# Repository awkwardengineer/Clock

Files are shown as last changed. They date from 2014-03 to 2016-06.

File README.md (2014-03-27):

Voltmeter Clock Image

# Intro
This is the repository for the AWK-105 Voltmeter clock. Here is where we'll be storing requirements documents, design history files, useful tidbits of information, and other material that otherwise wouldn't be release to manufacture or included in a Bill of Materials

##Consumer Facing Page
The repo may be cool, but it's not for everyone. The consumer facing product page has the bulk of the media material.

[Awkward Engineer Product Page](http://www.awkwardengineer.com/pages/voltmeter-clock)

##How This Repo Is Organized
In general, there are two categories of thing:  
+ Artifacts that will become part of the Bill Of Materials and will be released to a manufacturer. This includes CAD files, drawings, Gerbers, etc.  
+ Documentation and design files that record useful and important information, but that the manufacturer doesn't need to actually MAKE something.

The idea was to try to organize the documentation near the design file, kindof like things are arranged below.

Clock  
|  
|--Mechanical  
|&nbsp;&nbsp;&nbsp;|----CAD            <=== BOM artifacts, 3d part files, drawings  
|&nbsp;&nbsp;&nbsp;|----Design Docs    <=== Documentation specific to mechanical stuff
|&nbsp;&nbsp;&nbsp;|----Reference Mat. <=== Usually mostly .pdfs  
|  
|--Electrical  
|&nbsp;&nbsp;&nbsp;|----CAD            <=== Gerbers, net files, etc...  
|&nbsp;&nbsp;&nbsp;|----Design Docs    <=== Documentation specific to electrical stuff  
|  
|--Photos  
|  
|--etc...  

##Design Documents
Here are some quick links to some design stuff, right off the bat.

[Requirements](Electrical/Design Docs/requirements.md)  
[Microchip selection](Electrical/Design Docs/microcontroller selection.md)  
Sales strategy

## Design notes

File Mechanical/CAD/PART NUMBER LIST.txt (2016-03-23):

NUMBER	DESCRIPTION

AWK-105-0001-ARTWORK    ARTWORK FOR METERS
AWK-105-0001-H          VOLTMETER, HOURS
AWK-105-0001-M          VOLTMETER, MINUTES
AWK-105-0001-S          VOLTMETER, SCRAP
AWK-105-0002            BOX, FRONT FACE
AWK-105-0003            ASSEMBLY, VOLTMETER
AWK-105-0004            BOX, BACK FACE
AWK-105-0005            PCB
AWK-105-0006            **** obsolete BOX MODIFICATION NOTES
AWK-105-0007            PCB LAYOUT SKETCH
AWK-105-0008            QUADRATURE ENCODER, BOURNES PEC12R-2xxxF-Nxxxx
AWK-105-0009	        POTENTIOMETER              
AWK-105-0010            HOUSING DRAWINGS, VOLTMETER CLOCK
AWK-105-0011            PHILLIPS PAN HEAD SCREW, 4-40x.25, 18-8 SS
AWK-105-0012            NUT, METRIC M2, 18-8 SS
AWK-105-0013            PHILLIPS PAN HEAD SCREW, METRIC M2 x 4mm, 18-8 SS
AWK-105-0014            CONTROL KNOB
AWK-105-0015            ASSEMBLY DRAWINGS, VOLTMETER CLOCK
AWK-105-0016            SCREEN PRINT ARTWORK, FRONT FACE
AWK-105-0017            SCREEN PRINT ARTWORK, TOP FACE
AWK-105-0018            PHILLIPS PAN HEAD SCREW, METRIC M2.5 x 4mm, 18-8 SS
AWK-105-0019            CARDBOARD MAILER BOX
AWK-105-0020            STICKER, MAILER BOX
AWK-105-0021            ARTWORK, STICKER, MAILER BOX

AWK-105-0022            PROGRAMMED ATtiny CHIP
AWK-105-0023 Rev A      HEX FILE TO BURN INTO CHIP
AWK-105-0024 Rev A      FUSE SETTINGS TO BURN CHIP

AWK-105-0024            BATTERY CLIP

AWK-105-0025            VOLTMETER CLOCK ASSEMBLY PROCEDURE

AWK-105-0026            TOGGLE SWITCH
AWK-105-0027            TOGGLE SWITCH COVER
AWK-105-0028            LED

AWK-105-0029            WADDING (PACKAGING)

AWK-105-0030            SCREEN PRINT ARTWORK, TOP FACE, ALARM
AWK-105-0031            SCREEN PRINT ARTWORK, FRONT FACE, ALARM

AWK-105-0032            AA BATTERY
AWK-105-0033            INSTRUCTION SHEET
AWK-105-0034            METER TEST SPEC
AWK-105-0035            STICKER DOT
AWK-105-0036            M3 PEM NUT
AWK-105-0037		CASE FRONT, UNPAINTED
AWK-105-0038		CASE BACK, UNPAINTED
AWK-105-0039		INK PAD
AWK-105-0040		EXTRA NARROW SOCKET DRIVER
AWK-105-0041		SQUEEZE DRIVER HAND TOOL
AWK-105-0042            MASTER CARTON
AWK-105-0043            MASTER CARTON LABEL
AWK-105-0044            MASTER CARTON ARTWORK
AWK-105-0045		GIFT CODE INSERT

TEST RIGS BLOCK O'NUMBERS:
===============================================
AWK-105-0100            METER TEST MASTER MODEL
AWK-105-0101		HOUSING, TEST RIG

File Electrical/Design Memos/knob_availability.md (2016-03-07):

Potentiometer, 50K from panasonic  
readily available with 10mm centerline height (same as existing) and a 25mm flatted shaft (5mm longer)  
EVU-E2AF25B54  
  
has a 3 pin configuration, whereas the Bourns PTV111 family I used had 4 pins

from Bourns, not as readily available 10K version in identical package

PTV09A-2025F-B103

PTV-09A-2020F is slightly shorter, but available in more resistances, although not as many

TT Electronics has an encoder, but footprint doesn't work EN11-HSM

CUI makes an ACZ11 family that is pin compatable with the PEC12 encoder, but isn't super available

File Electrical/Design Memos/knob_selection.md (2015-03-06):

>**Executive Summary:** An archived memo details the experience of browsing Digikey and eventually settling on some encoders and potentiometers from a manufacturing company called Bourns. The right angle components were slightly more expensive, but they more than make up for the cost in terms of reduced assembly steps. This memo recaps the selection of specific part numbers.

##Encoder
PEC12R-<config><detents><shaft length>F-<switch><resolution>

PEC12R-2120F-N0012

PEC12R-

2  - <config: horizontal>
1  - <detents: 12>
20 - <shaft length: 20mm shaft>
F  - flatted shaft
N  - <switch: no switch>
0012 - <resolution: 12 pulses>

##Potentiometer

PTV111-2420A-B104

PTV111-

2 - <config: no bushing, pins horizontal>
4 - <center detent?: none>
20 - <shaft length: 25mm>
A - Flat type shaft
B - <taper: most linearly tapered curve available>
104 - <resistance: 100K>

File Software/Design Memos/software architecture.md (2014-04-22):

>**Executive Summary:** Offload as much work to the TIMERs as possible and shutting down the CPU to save power.

##Software/Power Strategy
To truly take advantage of what the ATtiny84 microcontroller can do, we're going to be getting into some of the features of the chip that the Arduino environment normally hides. More specifically, we'll be taking advantage of some of the power saving modes.

As it turns out, the ATtiny84 has two timers that can be run completely independently of the actual CPU (plus a watchdog, which we won't use). The general idea, therefore, is to keep the CPU off as much as possible, saving power, and only doing work during periodic interrupt service routines when TIMER1 maxes out.

The first timer, TIMER0, will be used to control the PWM outputs that control the hands on the voltmeter. When initialized with the right settings, the timer will chug along, independently of the CPU and the Output Compare Registers A & B will automatically compare their settings to the timer count, setting the duty cycle of the PWM outputs.

The second timer, TIMER1, has a 16 bit register that triggers an interrupt when it overflows, waking up the CPU. The microcontroller then polls the input to see if the "Mode select" knob has changed, adjusts the hands as appropriate, then goes back to sleep.

We started making some notes

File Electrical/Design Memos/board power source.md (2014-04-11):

#Selecting a Power Source

We've gotten some feedback to ditch the wall-wart power supply and move the clock over to battery power. That certainly has some appeal (Ditches a pricey component, eliminates the assembly operation to feed the cable through the wall, eliminates a grommet at the wall, etc...), so we decided to look into it.

#Is battery power reasonable?

Wikipedia gives the capacity of an [AA battery](http://en.wikipedia.org/wiki/AA_battery) as 1800-2600mAHr. The ATtiny84 draws 300uA and the two ammeters draw an average total of 50uA. With some assumptions about an AA battery and some simple math:

2200mAHr / 350uA = 6286 Hrs = 261 days = about 8 months.

8 months is pretty good! And that's without taking advantage of the microcontroller sleep modes. I'd feel pretty good about performance if I could stretch it to a full year. I think adding a battery in parallel would provide good margin to do that.

#Implications of Switching to Battery Power
Other than the need to conserve power, the next challenge is that the battery voltage will droop as it discharges. The ATtiny84 has some brown out detection stuff I don't know much about, but more importantly, drooping voltage can't effect the position of the time keeping analog needles.

There are a few ways I'm considering to deal with this problem:

|Method | Pros | Cons |
|---|---|---|
| Linear regulator on battery | simple | less efficient |
| Buck (and/or) Boost converter on battery | more expensive | more efficient |
| Leave the battery unregulated, but use a voltage reference to make a constant current source to drive the meters. | unsure of cost or efficiency | unsure of cost or efficiency |

The ATtiny84 can run on anything from 1.8V to 5V, so it means 2 or 3 AA batteries in series off the bat. According to [this source](http://www.powerstream.com/AA-tests.htm), an AA alkaline battery will slowly droop from 1.5V to 1V over the course of it's life before really crashing.

I started looking into various ways to power the clock, and figured I'd have to actually price it out to make a decision. Here are the various circuit diagrams I'll refer to:

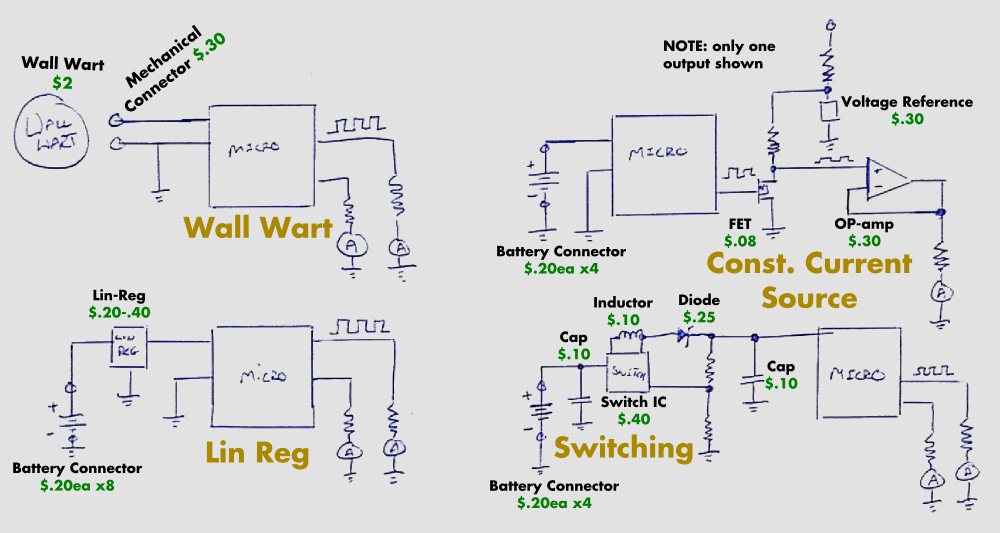
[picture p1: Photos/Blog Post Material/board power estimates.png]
circuit diagram


##Linear Regulator
Working again through the firehose that is Digikey, linear regulator chips like [this](http://www.ti.com/lit/ds/symlink/lp2951-33.pdf) are available for about $.20-.40 in the 100 piece volume range. This is pretty cheap, but the trade is that the two AA batteries will have an average voltage of about 2.5V over their lifespan and if I'm trying to output 2V or so to the micro, the .5V difference between input and output is like a 20% hit to power. Instead of the board pulling 350uA, it'd seem more like 420uA.

##Switching Regulator
Switching regulators can be more efficient than linear regulators and because they can boost voltage, it'd be possible to generate the needed 1.8V to run the micro, even from a 1.5V AA battery.

Again, Digikey can be overwhelming, as there are over 20,000 switching converter SKU's available. My approach was filter by current load first, which got it down to a more manageable 2000 pieces, then sorted by cost in volumes of 100. That lead me to [this chip](http://www.diodes.com/datasheets/AP3015_A.pdf), specifically meant for boosting from one or two battery cells.

It runs aroune $.40, plus it requires several additional components, and can introduce ripple to the voltage. (Although high frequency ripple at the switching speeds will be completely mechanically damped at the needles). The required extra components (caps, inductor, diode), might run $.05-.20 each, which I'll estimate rolled together at adding another $.40, make the boost cicuit cost about $.80.

##Unregulated Battery
The ATtiny84 chip will certainly run off battery power, but to get a consistant current to the meters, rather than rely on the voltage from the micro's digital output, I'd use that to control a constant current source. This could be built with a precision voltage reference, an op-amp, and some FETS. Of course, I'd need to double these up for both the "Hours" meter and the "Minutes" meter.

After browsing digikey for precision voltage references, filtering by current draw, then sorting on price, I found that precision voltage references that drew < .1mA current ran around $.30. Given the other components required, I don't it will be significantly cheaper than the regulated versions, and it is certainly more complicated.

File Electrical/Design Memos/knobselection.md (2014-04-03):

>**Executive Summary:** Browsing digikey found no appropriate SMT encoders or pots. Of the through-hole connectors, the "right angle" style are $.10-.20 more expensive, but I believe that is justified by the fact a single board can connect the knobs and dials, reducing assembly complexity, and eliminating the need for flying leads or jumpers to the dials. Quantities may necessitate a special order through a distributor. [Bourns](http://www.bourns.com/Products.aspx) was the company picked to select encoders and pots from. I picked the Bourns **PEC12R-2020F-N0024** encoder, and the Bourns **PTV11-2420A-A4503** potentiometer.

##Intro
The Clock has two control knobs, one to select the mode of operation, and one to make adjustments to time or calibration, depending on the mode. The mode select knob uses a pot to measure absolute position and the adjustment knob uses a quadrature encoder to allow the knob to rotate 360 degrees and to measure relative motion.

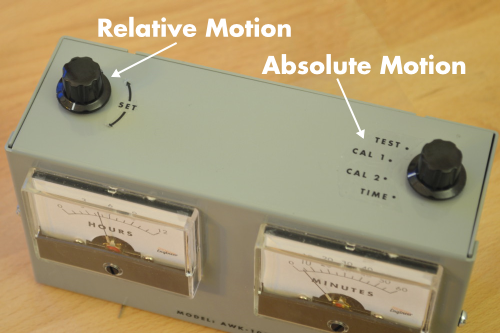
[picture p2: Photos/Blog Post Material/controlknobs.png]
knobs


##The Prototype, aka The Rat's Nest
The prototype has a lot of hand soldered flying leads, cobbled together from knob components that I found, the Digispark microcontroller, and the voltmeters.

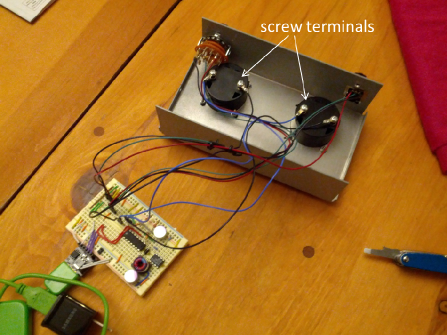
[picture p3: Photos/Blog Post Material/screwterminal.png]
rat nest


##Designing for Assembly
The electronics assembly absolutely needs to be cleaned up so that assembly process can be quick and reliable. I've worked in the past with a mechanical assembly house that provide employment for the mentally disabled and I try to keep them in mind when designing. The assembly house is also near my e-commerce warehouse, so I have to have a really good reason to not use them. Poor design can't be one of those reasons.

I had two ideas:

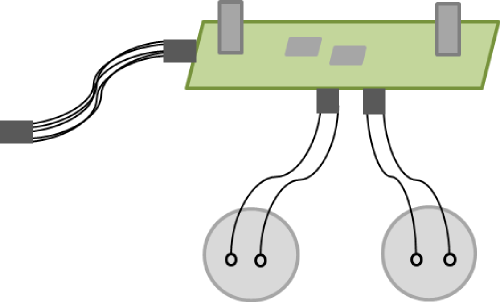
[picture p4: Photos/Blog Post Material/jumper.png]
jumper
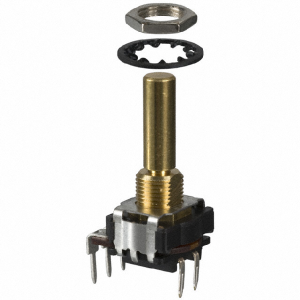
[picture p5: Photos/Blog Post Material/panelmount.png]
panel mount
1. Use panel mount switches to hold the PCBA underneath the clock. The flying leads running to the dials would be replaced with a jumper kit, with a plug on one end of the harness running to the board and ring terminal crimps on the other that would screw onto the dial leads. I figured the overall board size would be smaller (and therefore cheaper), and the cable, if I could source it, would be easy for an unskilled laborer to install. The nuts on "panel mount" style knobs would secure the PCBA and eliminate the need for standoffs in the housing.<br>
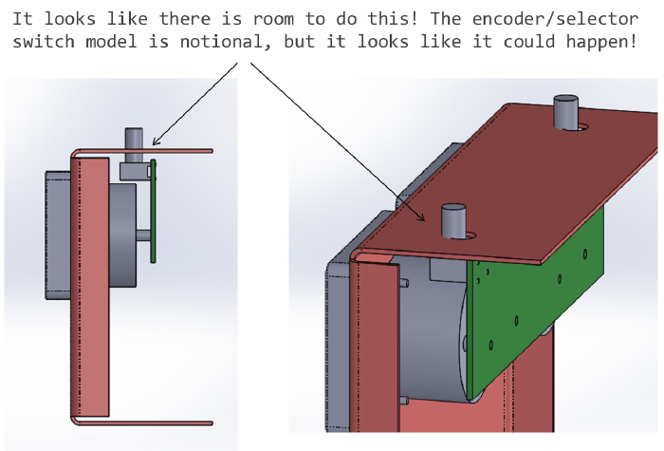
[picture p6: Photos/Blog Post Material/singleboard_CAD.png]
single
2. I had a second idea to use the board itself to run traces to a through hole. The area around the hole would be plated so that screwing the board to the dial leads would make electrical contact and mechanically mount the board. This would require a "right angle" style encoder and pot. <br>

##Searching Digikey
Much like microcontroller selection, browsing the zillions of components on Digikey can be overwhelming. Here's what drove selection:

- sorting by price, I found 6mm shafts were typically cheapest. (closest metric size to 1/4in and a common knob size. I learned this from work on the Awkard Engineer [Panic Button Light Switch Kit](http://www.awkwardengineer.com/collections/stuff/products/panic-button-limited-edition))
- SMTs were out pretty quickly, they're just not available in the right sizes or form factors.
- next I learned that right angle style components were running around $.10-.20 more expensive than straight on style devices, but given that it saves sourcing a jumper cable and two nut turning operations on the panel mount style switch, I think it's worth it.
- finally, try to select by size / price.

Of the Digkey components I found, [Bourns](http://www.bourns.com/Products.aspx) was a name that popped up for in stock products in the sub $1 range for components.

##A comment on sourcing before final selection
I know I'm too small a player to deal with a manufacturer directly and my volumes may necessitate a special order, given what I saw on Digikey. Rather than designing based on what's in-stock with Digikey right *now*, my approach will be to take the manufacturer I identified, select an encoder and pot with identical packaging (will make mechanical assembly easier) and pick what I really want.

An EE friend suggested that when you cross over from the on-demand, prototype quantities available through Digi-key, there's another market for chips out there with a mix of distributors and "gray market" sources. Manufacturers take multi thousand piece orders (think whole reels, trays, or cases... in retail we'd call this the Minimum Order Quantity, or MOQ)from middlemen, then little guys like me buy from the middleman.

For example, a distributor may place the MOQ sized order and hold the balance in stock while selling the smaller quanitity to me, or a board house who had to place a MOQ sized order to populate a PCBA might try to sell the balance of their stock on the gray market.

The EE friend refered me specifically to [findchips.com](http://www.findchips.com/) as a "meta" search engine, that will search all the distributors for a paricular part and return the amount in stock. If the components aren't available there, then I'd place an order through a distributor and the lead time might be about 8-12 weeks.

##Selecting components
Finally, after picking Bourns's catalog, I used the parts I found using the "sort by price" option on Digikey to direct me to a specific "series" of part.

Within each series, you can pick from a range of options like mounting style, shaft length, encoder counts per revolution, press on / press off switch, and so on.  I picked

encoder: PEC12R-2020F-N0024
potentiometer: PTV11-2420A-A4503

When it comes time to go to fab, I may work with the board house to come up with a list of alternate components that would be acceptable. (For example, a 20K pot would be just as good as a 50K pot for my purposes).

##Physical Check
I modeled the components in CAD to physically check them. It looks like the single board idea will work, but I'll either need to stand it off from the screw terminals, or move the control knobs forward. (I know which way is cheaper, but also which way affects the look of the finished part)

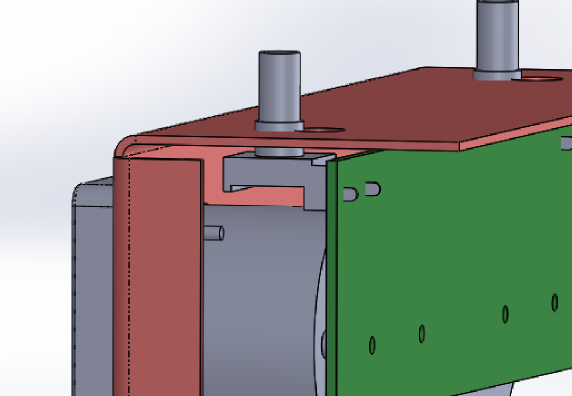
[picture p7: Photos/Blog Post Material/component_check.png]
CAD Check


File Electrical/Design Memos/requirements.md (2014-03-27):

#Short background of the requirements:

The microchip is meant to run a "voltmeter clock." It's responsible for time keeping, sending PWM signals to the meters, reading inputs from the control knobs, and so on. The prototype was controlled with a Digispark hobby board and I'm trying to develop a short run production version. (probably more than 100 units and less than 1000)  

Prototype program code was around 5kB on a Digispark board (atTiny85) using the Arduino environment plus whatever bootloader was already burned on the chip

##System Diagram
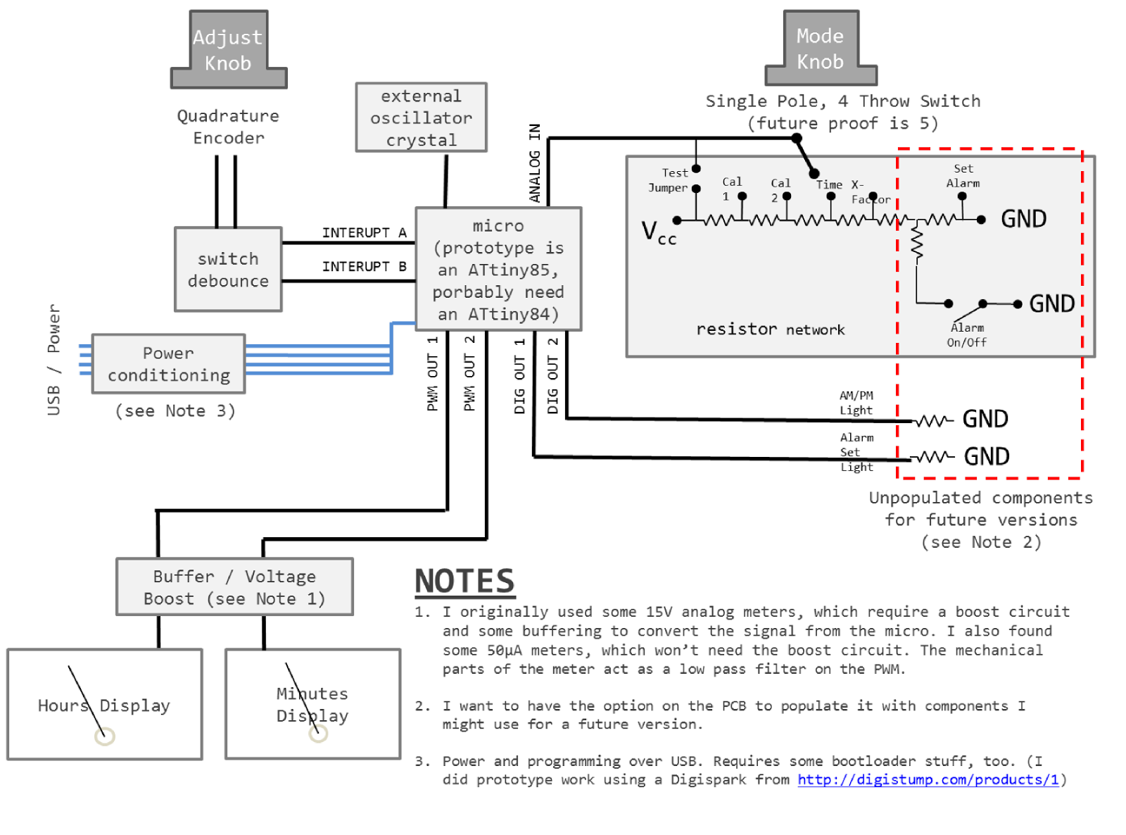
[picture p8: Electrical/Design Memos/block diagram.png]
system diagram


##Pin requirements
(beyond what's on the Digispark) would be as follows:

1 analog in to read selector switch / voltage divider  
2 interrupts to read quadrature encoder  
2 PWM outputs  
3 digital outputs for am/pm light, alarm set, and buzzer  
2 pins for external oscillator crystal

ISP connection

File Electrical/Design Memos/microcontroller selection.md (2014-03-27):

#Microcontroller Selection and Justification by Someone Who's Only Selected One or Two Before

>**Executive Summary:** An ATtiny84 microchip was selected based on requirements developed after prototyping a Voltmeter clock with a Digispark Board/ATtiny85. Specifically, the ATtiny84 can handle the 10 I/O plus ISP lines and a 5Kb+ program size.

##Intro
The purpose of this document is to justify the selection of a microcontroller for the Voltmeter Clock. Although a prototype was built using a Digispark Board/ATtiny85, the ATtiny85 didn't have enough I/O to implement all the desired features.

##Requirements review:
The following quotes from the [requirements doc](requirements.md).  
>**Pin summary**  
>1 analog in to read selector switch / voltage divider  
>2 interrupts to read quadrature encoder  
>2 PWM outputs  
>3 digital outputs for am/pm light, alarm set, and buzzer  
>2 pins for external oscillator crystal  

All together, this works out to 8 I/O pins, the 2 clock pins, and whatever is needed for In System Programming (ISP) pins, which can serve double duty.

##Design Descision \#1: Stay in the Atmel family
This decision is made more on qualitative measures rather than rigorous analysis. I'm familiar with the Arduino toolchain, I have some familiarity with libraries available for the ATtiny, and the parts are in stock and available in volumes of hundreds through Digikey.

##Design Decision \#2: Chip Selection with parametric tool
Atmel has a parametric selection tool [here](http://www.atmel.com/products/microcontrollers/avr/default.aspx?tab=parameters). Using the I/O pin slider on the parametric tool, the closest breakpoint after the 10 I/O pins (plus ISP) I required is 11. Setting the maximum number of I/O pins at 12 and making sure I have enough flash (8Kb is the next breakpoint after the estimated 5Kb in size), results in a more manageable selection choice of 4 devices: the ATtiny84, plus three other automotive qualified and/or low power variants.  Of these, I've selected the **ATtiny84**

##Design Note on the Dual Purpose ISP pins and RESET
I learned that Digispark disabled the RESET pin on the ATtiny85 after burning the initial bootloader with the ISP. This means that once the bootloader is on there and the RESET pin has been switched to a general purpose input, it can't be programmed with ISP any more. **I would like to be able to reprogram the boards!**

Quoting from the digispark [website](https://digistump.com/wiki/digispark/tutorials/programming)
>\[ISP\] is meant to provide a cheap way to update code, to fix bugs, or to extend capabilities without unsoldering the chip. There are, however,some restrictions to this mode as well: ISP uses MISO, MOSI and SCK (as well as RESET), and there is limited interference with those three pins allowed. Atmel recommends using resistors between these ISP pins and their other uses in a circuit. In general it's a good recommendation, to read design considerations:

>As ISP connection needs the enabled RESET function (and therefore disabled GPIO function of the shared physical pin), there is no way, to program an off-the-shelf digispark with any ISP device, because the digispark has disabled the reset function.

##Pin out check on the ATtiny84
The proposed pinouts are below. Note that there were enough pins to be able to leave the reset pin clear.

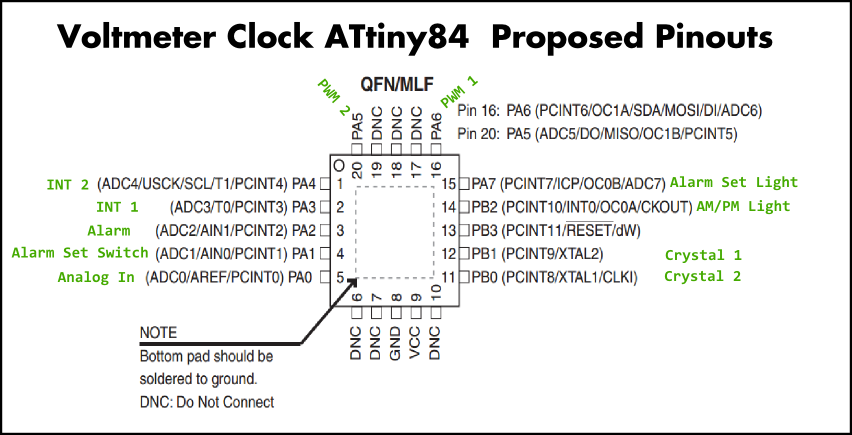
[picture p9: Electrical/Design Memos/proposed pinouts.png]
pinouts


8kB memory [check!]  
Interrupts galore [check!]  
2 PWM channels [check!]  
Digital channels galore [check!]  
External clock pins [check!]  

##Conclusion
The **ATtiny84** is an appropriate chip for this project.

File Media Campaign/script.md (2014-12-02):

This is my take on what a desk clock would be in a world that isn't overrun by flashing LCD screens. This is the Model AWK-105 Analog Voltmeter Clock.

It's look and feel is heavily inspired by my grandfather's WWII era telegraph keyer. The sheet metal construction and the instrumentation knobs were so solid and substantial, it left no doubt as to the durability and quality of construction. To me, old analog equipment like that has a functional beauty and aesthetic quality that I really tried to capture with my Clock design.

Clock operation is simple. The key design feature is of course, the dual analog meters. The first meter's gage goes up to 12, for hours, and the other goes up to 60, for minutes.

The mode knob selects between time keeping and calibration modes, and the adjustment knob does what it's name would suggest, adjusting the time and calibration.

Behind the sheet metal enclosure, a 32.768 Khz crystal oscillator and an ATtiny microcontroller keep track of the time and power the machine.

We really want this Clock to be a keepsake that's worthy of a place on your desk for the years to come. We've gone through CAD modeling, laid out custom circuit boards, and written our own firmware, and we're ready to build a small batch of these. We're turning to Kickstarter to get funds so we can place bulk orders and bring this project to life. Please donate, and thank you for your support!

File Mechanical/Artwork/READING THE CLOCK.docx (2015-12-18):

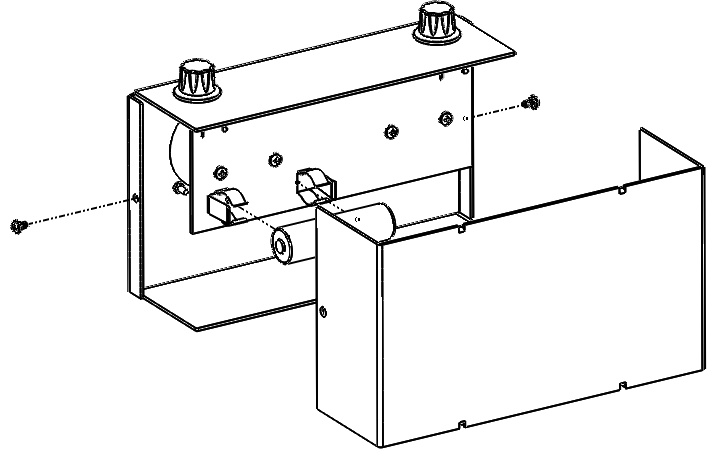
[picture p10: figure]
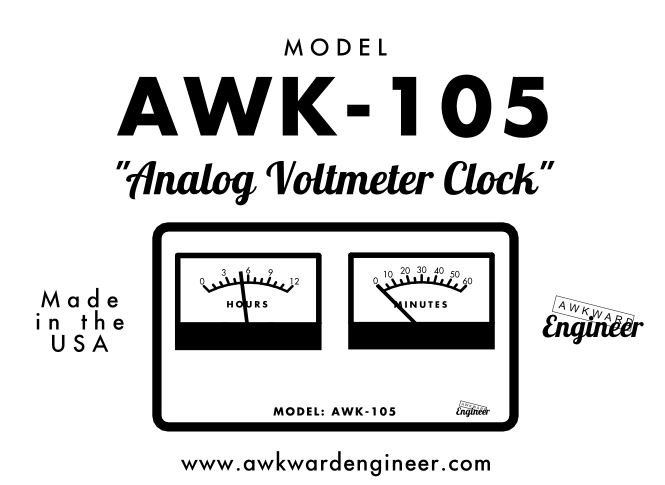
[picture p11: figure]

INSTALLING THE BATTERY Remove the screws from both sides of the case and then remove the back cover. Install single AA battery in the direction indicated on the circuit board.
INSTALLING THE BATTERY Remove the screws from both sides of the case and then remove the back cover. Install single AA battery in the direction indicated on the circuit board.

READING THE CLOCK

Read the time below as 4:57 (almost 5 o’clock somewhere.) The hours hand moves in whole hour increments.

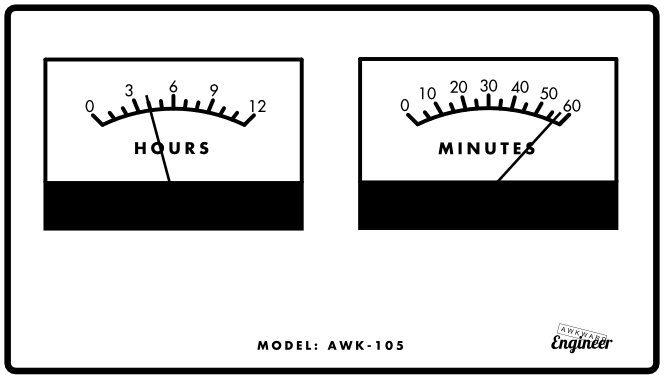
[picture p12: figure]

CONTROL KNOB FUNCTIONS

note: Calibration modes are to adjust meter sensitivity, not time!

MODE | METERS STATUS | ADJUST KNOB FUNCTION
TIME | Meters point to full scale for 2 seconds before returning to zero, then displays the time. | Adjust knob sets time. The minutes and hours hand are connected, so may take several rotations.
WARBLE | Meters point to half scale for 2 seconds and then briefly show full scale before displaying the time. The needles twitch randomly. | None.
CAL 1 | Minutes meter points to zero, hours meter points to 12 hours. Use a screwdriver to adjust the zero point. | Adjust knob sets calibration of hours meter. Meter should point exactly to 12 hours.
CAL 2 | Hours meter points to zero, minutes meter points to 60 min. Use a screwdriver to adjust the zero point. | Adjust knob sets calibration of minutes meter. Meter should point exactly to 60 minutes.

READING THE CLOCK

Read the time below as 4:57 (almost 5 o’clock somewhere.) The hours hand moves in whole hour increments.

CONTROL KNOB FUNCTIONS

note: Calibration modes are to adjust meter sensitivity, not time!

MODE | METERS STATUS | ADJUST KNOB FUNCTION
TIME | Meters point to full scale for 2 seconds before returning to zero, then displays the time. | Adjust knob sets time. The minutes and hours hand are connected, so may take several rotations.
WARBLE | Meters point to half scale for 2 seconds and then briefly show full scale before displaying the time. The needles twitch randomly. | None.
CAL 1 | Minutes meter points to zero, hours meter points to 12 hours. Use a screwdriver to adjust the zero point. | Adjust knob sets calibration of hours meter. Meter should point exactly to 12 hours.
CAL 2 | Hours meter points to zero, minutes meter points to 60 min. Use a screwdriver to adjust the zero point. | Adjust knob sets calibration of minutes meter. Meter should point exactly to 60 minutes.

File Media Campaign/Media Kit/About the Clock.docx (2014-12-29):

About the Clock

The Model AWK-105 Analog Voltmeter Clock is my take on what a desk clock would be in a world that isn't overrun by flashing LCD screens.

- Dual analog meters - one "meter" for hours and another for minutes.
- Powder coated sheet metal construction.
- Highly tactile knob selector switches to set and adjust the time.
- Contrasting mix of analog and digital – the time is tracked digitally by the microcontroller, but an analog signal is output to the needles on the meters.

The Inspiration

The look and feel of the Model AWK-105 Voltmeter Clock is heavily inspired by my grandfather's WWII era telegraph keyer. The sheet metal construction and the instrumentation knobs were so solid and substantive, it left no doubt as to the durability and quality of construction. For me, old analog equipment like that has a functional beauty and aesthetic quality that I really tried to capture with my Clock design.

The Technology Inside

- Started as an Arduino prototype
- Moved to a custom circuit board built around an ATtiny microcontroller
- Optimized to draw microamps of power from a battery

About Sam Feller

Sam Feller is a mechanical engineer living in Somerville, MA. A while ago, he realized that the goofy, awkward thing he had going wasn't a phase he would grow out of, so he should decided to just run with it.

Sam has his own odd sense of humor and thoroughly enjoys making things. He has also been known to spend time in the kitchen, enjoys doodling, and has a habit of staring off in to space mid-conversation as he holds his own conversation entirely inside his head.

About Awkward Engineer Creations, LLC

Awkward Engineer Creations had its humble beginnings a few years ago as a humor blog that made approximately zero dollars. With the dawning realization that the Adsense revenue off a few hundred page views a day was not going to cut it, Sam made the decision to Do Something Different. The company’s line of products has been completely bootstrapped from an initial $500 investment.

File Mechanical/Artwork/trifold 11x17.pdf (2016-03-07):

# AWK-105

### M O D E L

# "Analo Voltmeter Cloc"

Engineer

A W K W A R D
MO D E L : AW K - 1 0 5

H O U R S

3 | 6 | 9
12 12

M I N U T E S

0

30
10

20 40 50
60

### www.awkwardengineer.com

### M a d e i n t h e U S A

## Engineer

A W K W A R D

T E C H N I C A L S P E C I F I C A T I O N S

Housing | .5052-H32 aluminum, .050" thick
Meters | 50µA current draw each at full scale deflection
PCBA | fully custom, 2 layer copper, lead free average power draw of entire circuit, approx. 300µA
Power Source | AA alkaline battery, expected life approx. 1 year onboard boost regulator will discharge battery to .4v while ouputing a steady 2v to system
Main CPU | Atmel ATtiny 24/44/84 family, memory is burned at factory, lock fuse unset so tinker/hackers can program via ISP
Firmware | power efficient, fully interrupt driven code

Awkward Engineer started life as a humor blog that made approximately zero dollars. We made the decision to Do Something Different and to use our mechanical engineering background to start designing physical products.

We invested $500 and launched our first product, the Panic Button Light Switch Kit, with a whopping 3 sales, including one to mom and one to dad. Stubbornly refusing to sit on inventory, we cold called our way into a key large retailer, and sold a few thousand units.

To make a long story short, we felt like we were on to something and threw ourselves into product development, learning more and getting better with each product. We now enjoy working on topics as varied as graphic design, microelectronics, mechanical design, embedded firmware, sales and marketing, and more!

We have a blast designing this stuff and love sharing our work with you! Check out www.awkwardenginer.com to see more and to join our mailing list. Email questions, comments, or your pictures (we love pictures!) to questions@awkwardengineer.com

A B O U T A W K W A R D E N G I N E E R

# AWK-105

### M O D E L

# "Analo Voltmeter Cloc"

Engineer

A W K W A R D
MO D E L : AW K - 1 0 5

H O U R S

3 | 6 | 9
12 12

M I N U T E S

0

30
10

20 40 50
60

### www.awkwardengineer.com

### M a d e i n t h e U S A

## Engineer

A W K W A R D

T E C H N I C A L S P E C I F I C A T I O N S

Housing | .5052-H32 aluminum, .050" thick
Meters | 50µA current draw each at full scale deflection
PCBA | fully custom, 2 layer copper, lead free average power draw of entire circuit, approx. 300µA
Power Source | AA alkaline battery, expected life approx. 1 year onboard boost regulator will discharge battery to .4v while ouputing a steady 2v to system
Main CPU | Atmel ATtiny 24/44/84 family, memory is burned at factory, lock fuse unset so tinker/hackers can program via ISP
Firmware | power efficient, fully interrupt driven code

Awkward Engineer started life as a humor blog that made approximately zero dollars. We made the decision to Do Something Different and to use our mechanical engineering background to start designing physical products.

We invested $500 and launched our first product, the Panic Button Light Switch Kit, with a whopping 3 sales, including one to mom and one to dad. Stubbornly refusing to sit on inventory, we cold called our way into a key large retailer, and sold a few thousand units.

To make a long story short, we felt like we were on to something and threw ourselves into product development, learning more and getting better with each product. We now enjoy working on topics as varied as graphic design, microelectronics, mechanical design, embedded firmware, sales and marketing, and more!

We have a blast designing this stuff and love sharing our work with you! Check out www.awkwardenginer.com to see more and to join our mailing list. Email questions, comments, or your pictures (we love pictures!) to questions@awkwardengineer.com

A B O U T A W K W A R D E N G I N E E R

Remove the screws from both sides of the case and then remove the back cover. Install single AA battery in the direction indicated on the circuit board.

I N S T A L L I N G T H E B A T T E R Y Read the time below as 4:57 (almost 5 o’clock somewhere.) The hours hand moves in whole hour increments.

C L O C K O P E R A T I O N S G U I D E | R E A D I N G T H E C L O C K

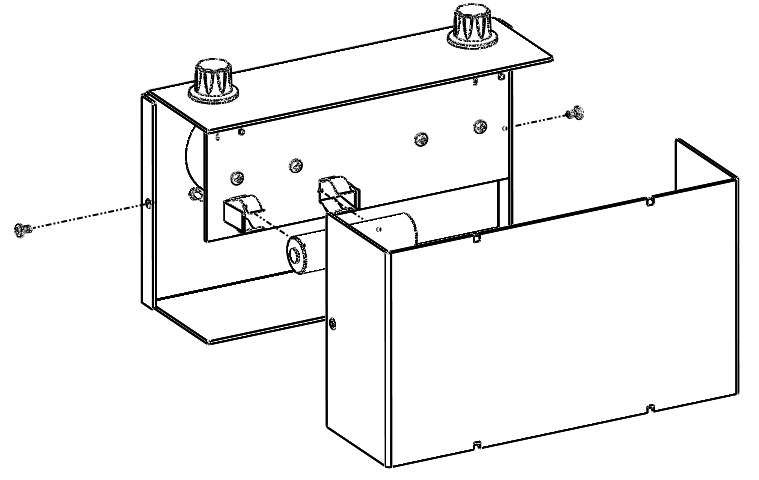
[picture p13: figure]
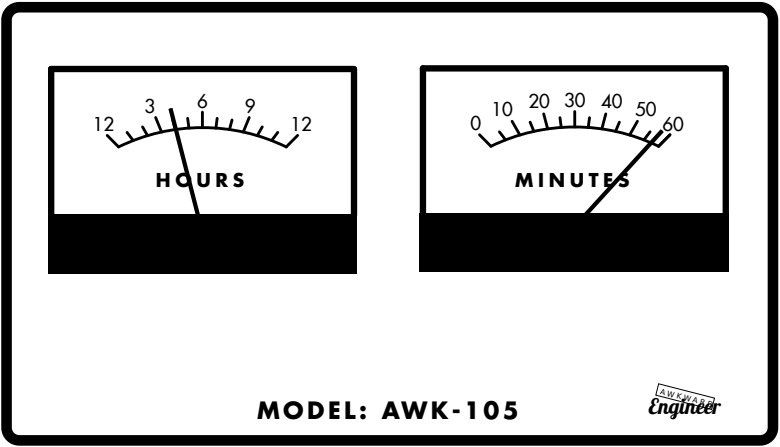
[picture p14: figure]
Engineer

### CAL1

### CAL2

MODE | DESCRIPTION

Turn the ADJUST knob until the minutes meter points to 60. Hours will be pointing to 0.

Turn the ADJUST knob until the hours meter points to 12. Minutes will be pointing to 0.

1st, start by calibrating the meters to achieve full scale deflection. If needed, the zero points can be adjusted with a screwdriver.

2nd, point the MODE knob to TIME mode to set the time. (Defaults to 5:00 at intial powerup.)

### TIME

Meters display full scale deflection for 2 seconds before displaying time. Then, turn the ADJUST knob to set the time. The minutes hand drives the hours hand, so it may take several turns to reach the correct time. WARBLE Meters display half scale deflection for 2 seconds, then the clock displays the time while the meters randomly twitch. The ADJUST knob is disabled in this mode.

Remove the screws from both sides of the case and then remove the back cover. Install single AA battery in the direction indicated on the circuit board.

I N S T A L L I N G T H E B A T T E R Y Read the time below as 4:57 (almost 5 o’clock somewhere.) The hours hand moves in whole hour increments.

C L O C K O P E R A T I O N S G U I D E | R E A D I N G T H E C L O C K

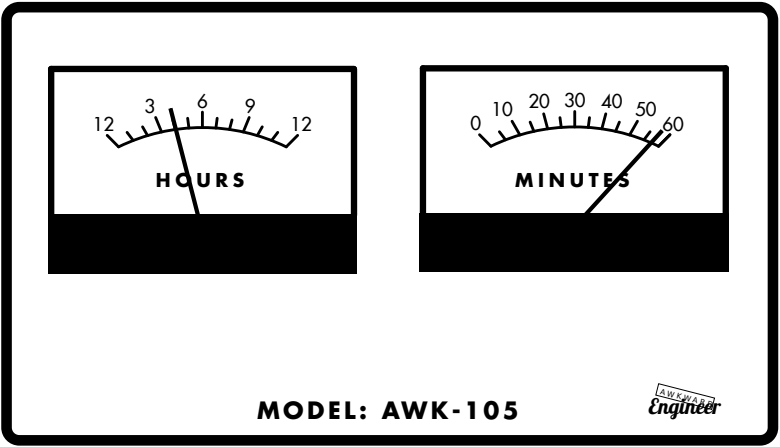
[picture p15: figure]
Engineer

### CAL1

### CAL2

MODE | DESCRIPTION

Turn the ADJUST knob until the minutes meter points to 60. Hours will be pointing to 0.

Turn the ADJUST knob until the hours meter points to 12. Minutes will be pointing to 0.

1st, start by calibrating the meters to achieve full scale deflection. If needed, the zero points can be adjusted with a screwdriver.

2nd, point the MODE knob to TIME mode to set the time. (Defaults to 5:00 at intial powerup.)

### TIME

Meters display full scale deflection for 2 seconds before displaying time. Then, turn the ADJUST knob to set the time. The minutes hand drives the hours hand, so it may take several turns to reach the correct time. WARBLE Meters display half scale deflection for 2 seconds, then the clock displays the time while the meters randomly twitch. The ADJUST knob is disabled in this mode.

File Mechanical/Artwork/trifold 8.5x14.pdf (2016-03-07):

# AWK-105

### M O D E L

# "Analo Voltmeter Cloc"

Engineer

A W K W A R D
MO D E L : AW K - 1 0 5

H O U R S

3 | 6 | 9
12 12

M I N U T E S

0

30 10 20 40 50
60

### www.awkwardengineer.com

M a d e
i n t h e
U S A

Engineer

A W K W A R D

T E C H N I C A L S P E C I F I C A T I O N S

Housing | .5052-H32 aluminum, .050" thick
Meters | 50µA current draw each at full scale deflection
PCBA | fully custom, 2 layer copper, lead free average power draw of entire circuit, approx. 300µA
Power Source | AA alkaline battery, expected life approx. 1 year onboard boost regulator will discharge battery to .4v while ouputing a steady 2v to system
Main CPU | Atmel ATtiny 24/44/84 family, memory is burned at factory, lock fuse unset so tinker/hackers can program via ISP
Firmware | power efficient, fully interrupt driven code

Awkward Engineer started life as a humor blog that made approximately zero dollars. We made the decision to Do Something Different and to use our mechanical engineering background to start designing physical products.

We invested $500 and launched our first product, the Panic Button Light Switch Kit, with a whopping 3 sales, including one to mom and one to dad. Stubbornly refusing to sit on inventory, we cold called our way into a key large retailer, and sold a few thousand units.

To make a long story short, we felt like we were on to something and threw ourselves into product development, learning more and getting better with each product. We now enjoy working on topics as varied as graphic design, microelectronics, mechanical design, embedded firmware, sales and marketing, and more!

We have a blast designing this stuff and love sharing our work with you! Check out www.awkwardenginer.com to see more and to join our mailing list. Email questions, comments, or your pictures (we love pictures!) to questions@awkwardengineer.com

A B O U T A W K W A R D E N G I N E E R

# AWK-105

### M O D E L

# "Analo Voltmeter Cloc"

Engineer

A W K W A R D
MO D E L : AW K - 1 0 5

H O U R S

3 | 6 | 9
12 12

M I N U T E S

0

30 10 20 40 50
60

### www.awkwardengineer.com

M a d e
i n t h e
U S A

Engineer

A W K W A R D

T E C H N I C A L S P E C I F I C A T I O N S

Housing | .5052-H32 aluminum, .050" thick
Meters | 50µA current draw each at full scale deflection
PCBA | fully custom, 2 layer copper, lead free average power draw of entire circuit, approx. 300µA
Power Source | AA alkaline battery, expected life approx. 1 year onboard boost regulator will discharge battery to .4v while ouputing a steady 2v to system
Main CPU | Atmel ATtiny 24/44/84 family, memory is burned at factory, lock fuse unset so tinker/hackers can program via ISP
Firmware | power efficient, fully interrupt driven code

Awkward Engineer started life as a humor blog that made approximately zero dollars. We made the decision to Do Something Different and to use our mechanical engineering background to start designing physical products.

We invested $500 and launched our first product, the Panic Button Light Switch Kit, with a whopping 3 sales, including one to mom and one to dad. Stubbornly refusing to sit on inventory, we cold called our way into a key large retailer, and sold a few thousand units.

To make a long story short, we felt like we were on to something and threw ourselves into product development, learning more and getting better with each product. We now enjoy working on topics as varied as graphic design, microelectronics, mechanical design, embedded firmware, sales and marketing, and more!

We have a blast designing this stuff and love sharing our work with you! Check out www.awkwardenginer.com to see more and to join our mailing list. Email questions, comments, or your pictures (we love pictures!) to questions@awkwardengineer.com

A B O U T A W K W A R D E N G I N E E R

Remove the screws from both sides of the case and then remove the back cover. Install single AA battery in the direction indicated on the circuit board.

I N S T A L L I N G T H E B A T T E R Y Read the time below as 4:57 (almost 5 o’clock somewhere.) The hours hand moves in whole hour increments.

C L O C K O P E R A T I O N S G U I D E | R E A D I N G T H E C L O C K

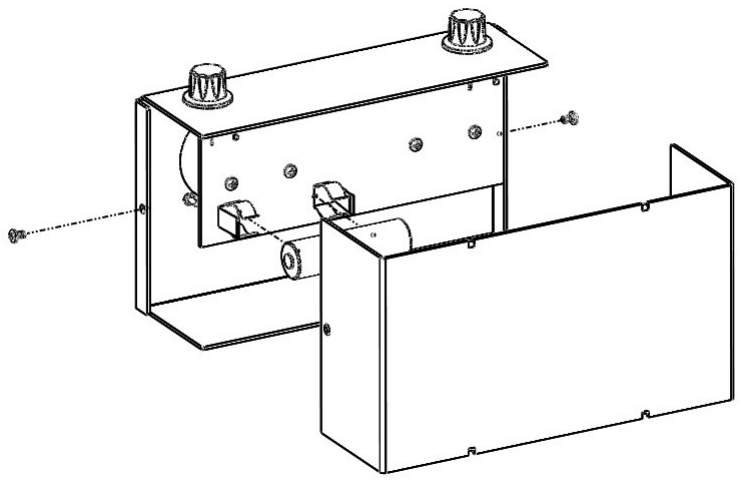
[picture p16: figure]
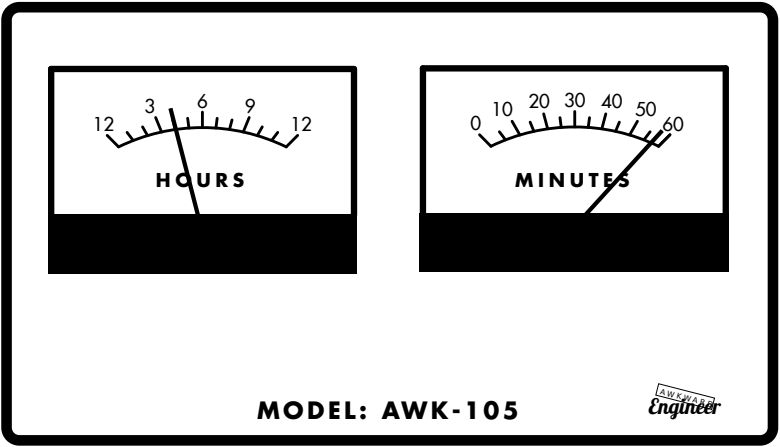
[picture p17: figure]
Engineer

### CAL1

### CAL2

MODE | DESCRIPTION
| Turn the ADJUST knob until the minutes meter points to 60. Hours will be pointing to 0.
| Turn the ADJUST knob until the hours meter points to 12. Minutes will be pointing to 0.

1st, start by calibrating the meters to achieve full scale deflection. If needed, the zero points can be adjusted with a screwdriver.

2nd, point the MODE knob to TIME mode to set the time. (Defaults to 5:00 at intial powerup.)

### TIME

Meters display full scale deflection for 2 seconds before displaying time. Then, turn the ADJUST knob to set the time. The minutes hand drives the hours hand, so it may take several turns to reach the correct time. WARBLE Meters display half scale deflection for 2 seconds, then the clock displays the time while the meters randomly twitch. The ADJUST knob is disabled in this mode.

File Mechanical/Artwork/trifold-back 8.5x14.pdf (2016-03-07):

Remove the screws from both sides of the case and then remove the back cover. Install single AA battery in the direction indicated on the circuit board.

### I N S T A L L I N G T H E B A T T E R Y

Read the time below as 4:57 (almost 5 o’clock somewhere.) The hours hand moves in whole hour increments.

C L O C K O P E R A T I O N S G U I D E | R E A D I N G T H E C L O C K

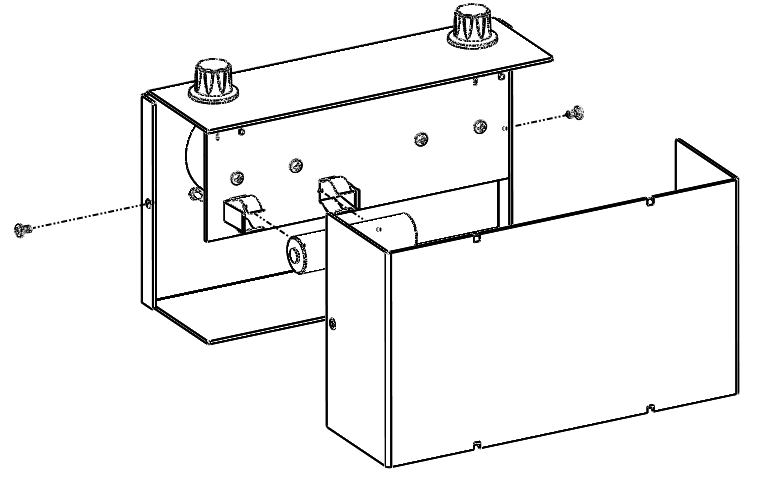
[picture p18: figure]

### CAL1

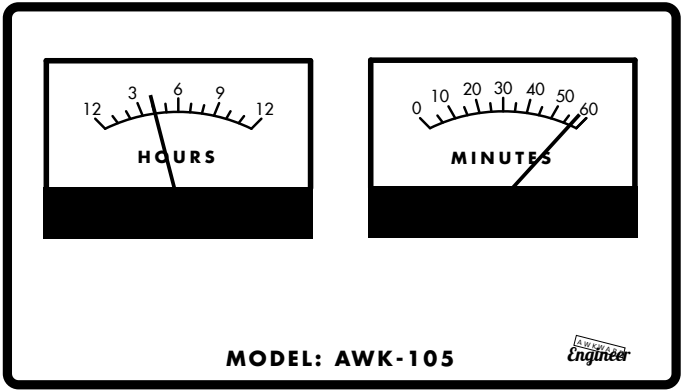
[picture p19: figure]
Engineer

### CAL2

MODE | DESCRIPTION

Turn the ADJUST knob until the minutes meter points to 60. Hours will be pointing to 0.

Turn the ADJUST knob until the hours meter points to 12. Minutes will be pointing to 0.

1st, start by calibrating the meters to achieve full scale deflection. If needed, the zero points can be adjusted with a screwdriver.

2nd, point the MODE knob to TIME mode to set the time. (Defaults to 5:00 at intial powerup.)
TIME | Meters display full scale deflection for 2 seconds before displaying time. Then, turn the ADJUST knob to set the time. The minutes hand drives the hours hand, so it may take several turns to reach the correct time.
WARBLE | Meters display half scale deflection for 2 seconds, then the clock displays the time while the meters randomly twitch. The ADJUST knob is disabled in this mode.

Remove the screws from both sides of the case and then remove the back cover. Install single AA battery in the direction indicated on the circuit board.

### I N S T A L L I N G T H E B A T T E R Y

Read the time below as 4:57 (almost 5 o’clock somewhere.) The hours hand moves in whole hour increments.

C L O C K O P E R A T I O N S G U I D E | R E A D I N G T H E C L O C K

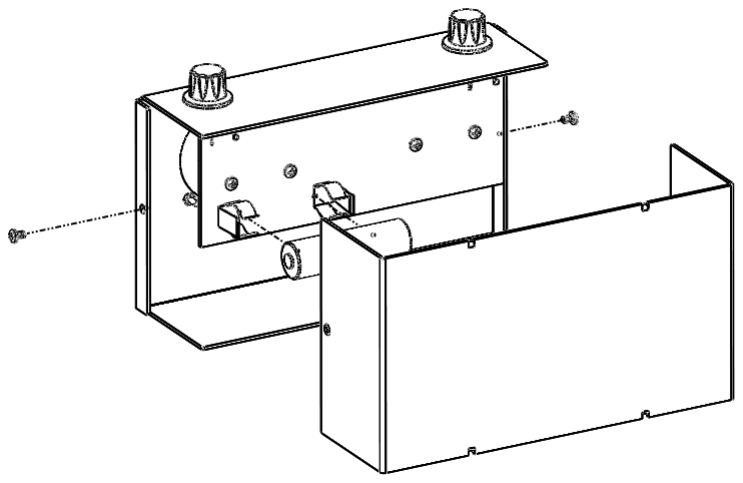
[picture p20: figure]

### CAL1

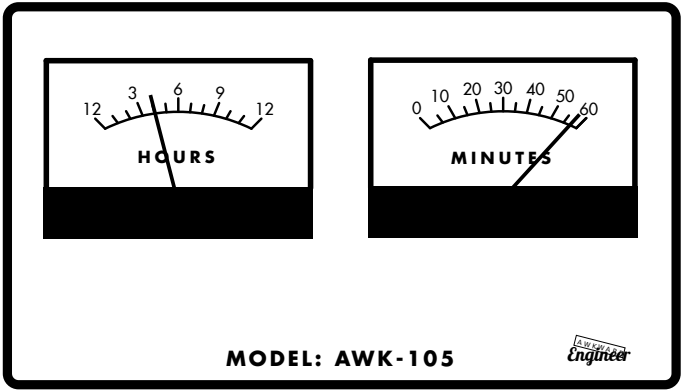
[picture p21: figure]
Engineer

### CAL2

MODE | DESCRIPTION

Turn the ADJUST knob until the minutes meter points to 60. Hours will be pointing to 0.

Turn the ADJUST knob until the hours meter points to 12. Minutes will be pointing to 0.

1st, start by calibrating the meters to achieve full scale deflection. If needed, the zero points can be adjusted with a screwdriver.

2nd, point the MODE knob to TIME mode to set the time. (Defaults to 5:00 at intial powerup.)
TIME | Meters display full scale deflection for 2 seconds before displaying time. Then, turn the ADJUST knob to set the time. The minutes hand drives the hours hand, so it may take several turns to reach the correct time.
WARBLE | Meters display half scale deflection for 2 seconds, then the clock displays the time while the meters randomly twitch. The ADJUST knob is disabled in this mode.

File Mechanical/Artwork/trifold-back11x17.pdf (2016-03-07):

Remove the screws from both sides of the case and then remove the back cover. Install single AA battery in the direction indicated on the circuit board.

### I N S T A L L I N G T H E B A T T E R Y

Read the time below as 4:57 (almost 5 o’clock somewhere.) The hours hand moves in whole hour increments.

C L O C K O P E R A T I O N S G U I D E | R E A D I N G T H E C L O C K

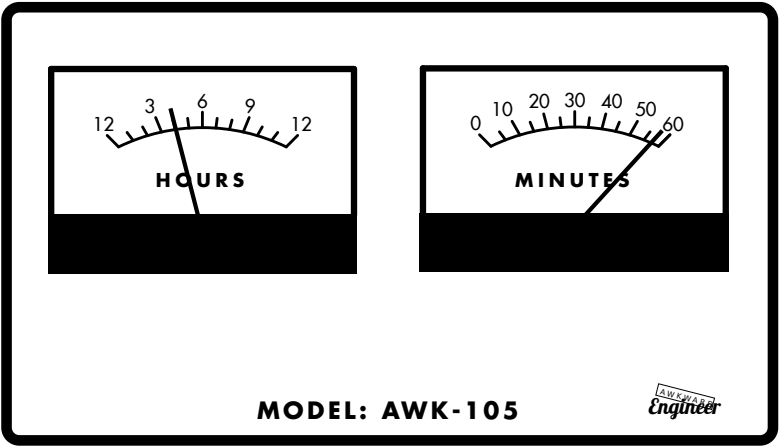
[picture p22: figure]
Engineer

### CAL1

### CAL2

MODE | DESCRIPTION

Turn the ADJUST knob until the minutes meter points to 60. Hours will be pointing to 0.

Turn the ADJUST knob until the hours meter points to 12. Minutes will be pointing to 0.

1st, start by calibrating the meters to achieve full scale deflection. If needed, the zero points can be adjusted with a screwdriver.

2nd, point the MODE knob to TIME mode to set the time. (Defaults to 5:00 at intial powerup.)
TIME | Meters display full scale deflection for 2 seconds before displaying time. Then, turn the ADJUST knob to set the time. The minutes hand drives the hours hand, so it may take several turns to reach the correct time.
WARBLE | Meters display half scale deflection for 2 seconds, then the clock displays the time while the meters randomly twitch. The ADJUST knob is disabled in this mode.

Remove the screws from both sides of the case and then remove the back cover. Install single AA battery in the direction indicated on the circuit board.

### I N S T A L L I N G T H E B A T T E R Y

Read the time below as 4:57 (almost 5 o’clock somewhere.) The hours hand moves in whole hour increments.

C L O C K O P E R A T I O N S G U I D E | R E A D I N G T H E C L O C K

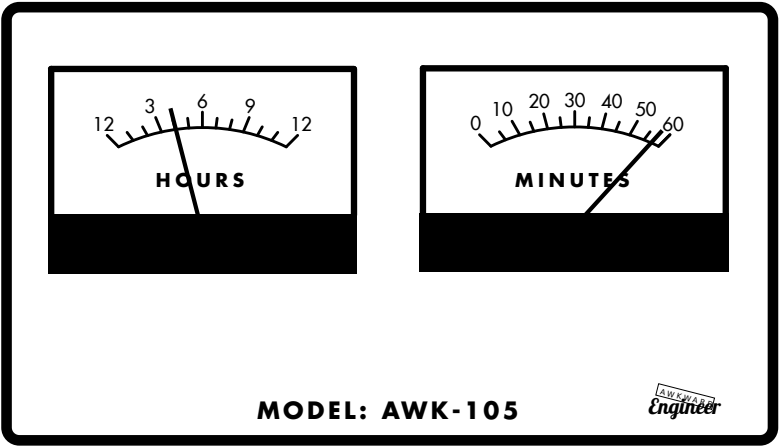
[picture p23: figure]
Engineer

### CAL1

### CAL2

MODE | DESCRIPTION

Turn the ADJUST knob until the minutes meter points to 60. Hours will be pointing to 0.

Turn the ADJUST knob until the hours meter points to 12. Minutes will be pointing to 0.

1st, start by calibrating the meters to achieve full scale deflection. If needed, the zero points can be adjusted with a screwdriver.

2nd, point the MODE knob to TIME mode to set the time. (Defaults to 5:00 at intial powerup.)
TIME | Meters display full scale deflection for 2 seconds before displaying time. Then, turn the ADJUST knob to set the time. The minutes hand drives the hours hand, so it may take several turns to reach the correct time.
WARBLE | Meters display half scale deflection for 2 seconds, then the clock displays the time while the meters randomly twitch. The ADJUST knob is disabled in this mode.

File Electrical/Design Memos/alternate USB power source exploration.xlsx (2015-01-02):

 |  | Uses lin reg to work with the boost converter. Effectively makes a buck boost. Doesn't interfere with rest of board design | Disable boost converter, replace resistors
Common Parts |  | LDO | Bypass
MicroUSB + Walwart | $5.00 | LDO Chip | meter resistors
MicroUSB | $0.30 | power smoothing capacitor | boost disable resistor
Grommet |  |  | remove existing resistors
Ziptie

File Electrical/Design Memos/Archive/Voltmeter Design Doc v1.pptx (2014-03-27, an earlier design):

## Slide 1

“Set” Knob for Quadrature Encoder

“Mode Select” Knob for Single Pole / Multi Throw

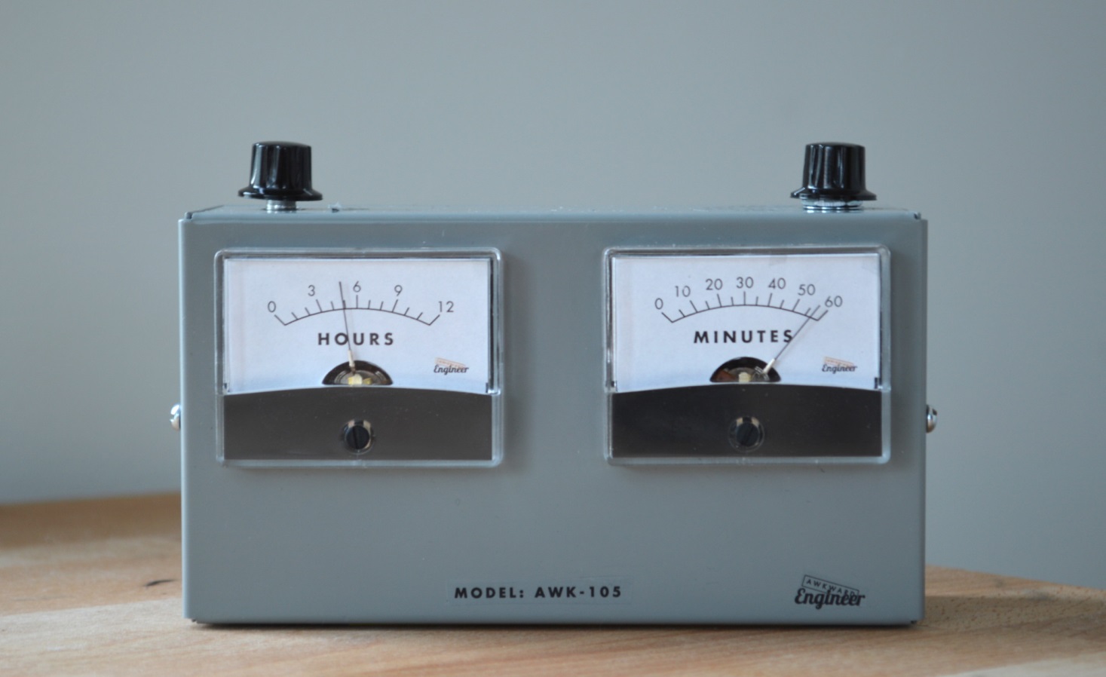
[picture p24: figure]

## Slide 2

Stuff I Could Use Help With
1. Schematic Capture
2. Component selection / sourcing (I’ve started on the meter selection, but not individual components. You don’t happen to speak Chinese, do you?)
3. Design For Manufacture / Design For Assembly Support (some specific fab related questions)
4. Board Layout
5. Fab house selection / support

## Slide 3

Adjust
Knob

Quadrature Encoder

Mode
Knob

external oscillator crystal

INTERUPT A

Single Pole, 4 Throw Switch (future proof is 5)

ANALOG IN

micro
(currently an ATtiny85)

PWM OUT 1

Test Jumper

Cal 1

Cal 2

Time

X-Factor

GND

GND

GND

Unpopulated components for future versions
(see Note 2)

Set Alarm

switch debounce

INTERUPT B

Vcc

resistor network

Alarm On/Off

GND

USB / Power

Power conditioning

(see Note 3)

PWM OUT 2

DIG OUT 1

DIG OUT 2

AM/PM Light

Alarm Set Light

Buffer / Voltage Boost (see Note 1)

Minutes Display

NOTES
1. I originally used some 15V analog meters, which require a boost circuit and some buffering to convert the signal from the micro. I also found some 50μA meters, which won’t need the boost circuit. The mechanical parts of the meter act as a low pass filter on the PWM.
2. I want to have the option on the PCB to populate it with components I might use for a future version.
3. Power and programming over USB. Requires some bootloader stuff, too. (I did prototype work using a Digispark from http://digistump.com/products/1)

Hours Display

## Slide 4

Encoder/ Switch Selection Notes


SOFT REQUIREMENT:
select shaft size of either ¼” or 6mm, but whatever you pick must be the same for both. (They fit a sourceable knob size)

SOFT REQUIREMENT:
“panel mount” style encoders and selection switches are easier

“panel mount” style switches only seem to come in through hole mounts. (FYI)

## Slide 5

Design For Manufacure / Design For Assembly Discussion Points

This prototype is almost an example of what not to do:
- Lots of hand soldered flying leads (think slow and expensive trained technicians)
- A bunch of crimped screw terminals (slow and expensive)


screw terminals

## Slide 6

Design For Manufacture / Design For Assembly Discussion Points

Seems like a single board can allllllmost make it. Maybe with some standoffs and clever placement of right angle connectors?


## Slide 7

Design For Manufacture / Design For Assembly Discussion Points

Idea #1

main PCB uses panel mount encoder & switch to attach to chassis

PCB connects all screw terminals (no crimped wires)

Description | # of Operations | Cost estimate
Course panel mount screws | 2x | $.20
Fine screws | 4x | $.80
Jumper | 2x | $.05
| | $1.05

To USB bulkhead connector

Jumper assembly with headers. IS THIS HARD TO GET? Can you get it with polarized plugs that can’t be put in backwards?

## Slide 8

Design For Manufacture / Design For Assembly Discussion Points

Idea #2

main PCB uses panel mount encoder & switch to attach to chassis

To USB bulkhead connector

Header one side, ring terminal crimps the other

Description | # of Operations | Cost estimate
Course panel mount screws | 2x | $.20
Crimp terminal screws | 4x | $1.00
Jumper | 2x | $.05
| | $1.25

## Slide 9

Design For Manufacture / Design For Assembly Discussion Points

vs.

If the Industrial Design changes and moves the knobs close together for a physically smaller board, does that save $$$?

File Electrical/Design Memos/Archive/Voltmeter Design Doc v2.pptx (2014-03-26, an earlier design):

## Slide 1

v1 | Initial creation
v2 | Added CAD model study to end of doc showing room for single board to work.

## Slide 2

“Set” Knob for Quadrature Encoder

“Mode Select” Knob for Single Pole / Multi Throw


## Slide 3

Stuff I Could Use Help With
1. Schematic Capture
2. Component selection / sourcing (I’ve started on the meter selection, but not individual components. You don’t happen to speak Chinese, do you?)
3. Design For Manufacture / Design For Assembly Support (some specific fab related questions)
4. Board Layout
5. Fab house selection / support

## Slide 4

Adjust
Knob

Quadrature Encoder

Mode
Knob

external oscillator crystal

INTERUPT A

Single Pole, 4 Throw Switch (future proof is 5)

ANALOG IN

micro
(prototype is an ATtiny85, porbably need an ATtiny84)

PWM OUT 1

Test Jumper

Cal 1

Cal 2

Time

X-Factor

GND

GND

GND

Unpopulated components for future versions
(see Note 2)

Set Alarm

switch debounce

INTERUPT B

Vcc

resistor network

Alarm On/Off

GND

USB / Power

Power conditioning

(see Note 3)

PWM OUT 2

DIG OUT 1

DIG OUT 2

AM/PM Light

Alarm Set Light

Buffer / Voltage Boost (see Note 1)

Minutes Display

NOTES
1. I originally used some 15V analog meters, which require a boost circuit and some buffering to convert the signal from the micro. I also found some 50μA meters, which won’t need the boost circuit. The mechanical parts of the meter act as a low pass filter on the PWM.
2. I want to have the option on the PCB to populate it with components I might use for a future version.
3. Power and programming over USB. Requires some bootloader stuff, too. (I did prototype work using a Digispark from http://digistump.com/products/1)

Hours Display

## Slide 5

Encoder/ Switch Selection Notes


SOFT REQUIREMENT:
select shaft size of either ¼” or 6mm, but whatever you pick must be the same for both. (They fit a sourceable knob size)

SOFT REQUIREMENT:
“panel mount” style encoders and selection switches are easier

“panel mount” style switches only seem to come in through hole mounts. (FYI)

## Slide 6

Design For Manufacure / Design For Assembly Discussion Points

This prototype is almost an example of what not to do:
- Lots of hand soldered flying leads (think slow and expensive trained technicians)
- A bunch of crimped screw terminals (slow and expensive)


screw terminals

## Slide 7

Design For Manufacture / Design For Assembly Discussion Points

Seems like a single board can allllllmost make it. Maybe with some standoffs and clever placement of right angle connectors?


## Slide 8

Design For Manufacture / Design For Assembly Discussion Points

Idea #1

main PCB uses panel mount encoder & switch to attach to chassis

PCB connects all screw terminals (no crimped wires)

Description | # of Operations | Cost estimate
Course panel mount screws | 2x | $.20
Fine screws | 4x | $.80
Jumper | 2x | $.05
| | $1.05

To USB bulkhead connector

Jumper assembly with headers. IS THIS HARD TO GET? Can you get it with polarized plugs that can’t be put in backwards?

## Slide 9

Design For Manufacture / Design For Assembly Discussion Points

Idea #2

main PCB uses panel mount encoder & switch to attach to chassis

To USB bulkhead connector

Header one side, ring terminal crimps the other

Description | # of Operations | Cost estimate
Course panel mount screws | 2x | $.20
Crimp terminal screws | 4x | $1.00
Jumper | 2x | $.05
| | $1.25

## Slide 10

Design For Manufacture / Design For Assembly Discussion Points

vs.

If the Industrial Design changes and moves the knobs close together for a physically smaller board, does that save $$$?

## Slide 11

Design For Manufacture / Design For Assembly Discussion Points

Seems like a single board can allllllmost make it. Maybe with some standoffs and clever placement of right angle connectors?

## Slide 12

DFM CAD Model Study (1 of 2)

Single board screws to both meters and has panel mount selector switch and encoder


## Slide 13

DFM CAD Model Study (2 of 2)

It looks like there is room to do this! The encoder/selector switch model is notional, but it looks like it could happen!


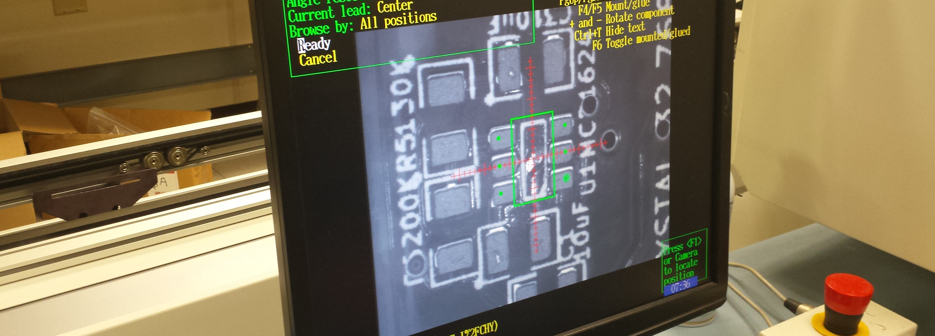
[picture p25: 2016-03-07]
Photos/Covers/original covers/cover - electronics.jpg

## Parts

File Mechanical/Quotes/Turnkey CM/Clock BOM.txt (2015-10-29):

ITEM NO.	PART NUMBER	REV	DESCRIPTION	QTY.	TYPE	REFERENCE DRAWING / PROCEDURE	DETAILED DESCRIPTION	FINISH	Vendor	VendorNo	Manufacturer	ManufacturerNo
0	"AWK-105GR, AWK-105OL"		ANALOG VOLTMETER CLOCK	1	TOP LEVEL ASSEMBLY	AWK-105-0025 revA -assembly procedure	Grey and Olive Voltmeter Clocks					
1	AWK-105-0004	F	"BOX, BACK FACE"	1	BUILD TO PRINT	"AWK-105-0010 revF - dimensional drawing
AWK-105-0004.sldprt - CAD FILE"	".050"" SHEET METAL, ALUMINUM"	POWDER COAT				
2	AWK-105-0002	F	"BOX, FRONT FACE"	1	BUILD TO PRINT	"AWK-105-0010 - dimensional drawing
AWK-105-0002.sldprt - CAD FILE
AWK-105-0016 - artwork
AWK-105-0017 - artwork"	".050"" SHEET METAL, ALUMINUM"	"POWDER COATED, SCREEN PRINTED"				
3	AWK-105-0005	C	PCBA AND LONG LEAD ELECTRONICS	1	BUILD TO PRINT	see separate electronics package						
3.1	AWK-105-0005	-	PCBA	1	BUILD TO PRINT	see separate electronics package	PRINTED CIRCUIT BOARD ASSEMBLY	-	CircuitHub.com			
3.2	AWK-105-0022		PROGRAMMED MICROCONTROLLER	1	COTS	"AWK-105-0023 - program hex file
AWK-105-0024 - fuse settings"	"ATtiny24A, SEE NOTES FOR ALTERNATES"		DIGIKEY	"Custom Orders, ATTINY24A-SSURCT-ND "	ATMEL	ATTINY24A-SSUR
3.3	AWK-105-0008		ENCODER	1	COTS	-	PEC12R-2120F-N0012		DIGIKEY	non stock special order	BOURNS	PEC12R-2120F-N0012
3.4	AWK-105-0009		POTENTIOMETER	1	COTS	-	PTV111-2420A-B104		DIGI-KEY	"non stock, special order"	BOURNS	PTV111-2420A-B104
4	AWK-105-0001-H	-	"VOLTMETER, HOURS"	1	COTS	purchase / inspection spec needs Doc #	50uA ANALOG PANEL MOUNT AMMETER	-	 	"PM-2, 50uA special order"	CHINA HOPE SUN	PM-2 50uA
5	AWK-105-0001-M	-	"VOLTMETER, MINUTES"	1	COTS	purchase / inspection spec needs Doc #	50uA ANALOG PANEL MOUNT AMMETER	-	 	"PM-2, 50uA special order"	CHINA HOPE SUN	PM-2 50uA
6	AWK-105-0018	-	"PHILLIPS PAN HEAD SCREW, METRIC M3 x 4mm, ZINC PLATE"	6	COTS	-	"PHILLIPS PAN HEAD SCREW, METRIC M3 x 4mm, 18-8 SS"	-	MCMASTER	92000A113		
7	AWK-105-0012	-	"NUT, METRIC M2"	4	COTS	-	"NUT, METRIC M2"	-	MCMASTER	91828A111		
8	AWK-105-0014	-	CONTROL KNOB	2	COTS	-	"ITEM #1910, SKIRTED KNOB, 1/4"" SHAFT"	-	DAVIES MOLDING	1910	DAVIES MOLDING	1910
9	AA_BATTERY		AA BATTERY	1	COTS	-	AA BATTERY		AMAZON	B00YCW3ZK4		
10	AWK-105-0019	-	MAILER BOX	1	COTS	-	CARDBOARD SHIPPING BOX	-	ULINE	S-420		
11	AWK-105-0020	A	"STICKER, MAILER BOX"	1	BUILD TO PRINT	AWK-105-0021 - artwork	"4""x 6"" CUSTOM PERMANENT STICKER"	-	ULINE	S-462		
12	AWK-105-0029	-	WADDING	1	COTS	-	SOFT PACKAGING MATERIAL	-	ULINE	 S-656

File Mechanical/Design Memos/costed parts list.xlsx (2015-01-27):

ITEM NO. | PART NUMBER | REV | DESCRIPTION | QTY. | TYPE | DETAILED DESCRIPTION | REFERENCE DRAWING / PROCEDURE | REFERENCE REV | MATERIAL | FINISH | Vendor | VendorNo | Manufacturer | Manufacturer No | COST | TOOLING COST | COST NOTES |  | EXTENDED COST
1 | AWK-105-0004 | A | BOX, BACK FACE | 1 | BUILD TO PRINT | .060" SHEET METAL, ALUMINUM | AWK-105-0010 | A |  | POWDER COAT |  |  |  |  | 15.48 | 225 | Cost is for qty 100, setup cost is for screen print. |  | 15.48
2 | AWK-105-0002 | A | BOX, FRONT FACE | 1 | BUILD TO PRINT | .060" SHEET METAL, ALUMINUM | AWK-105-0010, ARTWORK IS IN AWK- 105-0016, AWK-105- 0017 | A |  | POWDER COATED, SCREEN PRINTED |  |  |  |  | - |  | cost is rolled up un AWK- 105-0004
3 | AWK-105-0005 | - | PCBA | 1 | BUILD TO PRINT | PRINTED CIRCUIT BOARD ASSEMBLY | SEE SEPERATE ELECTRONICS PACKAGE |  |  | - | CircuitHub.c om |  |  |  | 11.845 |  | Cost is for qty 150, but changes a lot with volume |  | 11.845
4 | AWK-105-0001 | - | VOLTMETER | 2 | COTS | 50uA ANALOG PANEL MOUNT VOLTMETER | - | - |  | - | NexPCB | PM-2, 50uA | CHINA HOPE SUN | PM-2 50uA | 3.6 | 545 | Tooling cost includes screenprint 1000 meter scales |  | 7.2
5 | AWK-105-0018 | - | PHILLIPS PAN HEAD SCREW, METRIC M2.5 x 4mm, 18-8 SS | 6 | COTS | PHILLIPS PAN HEAD SCREW, METRIC M2.5 x 4mm, 18-8 SS | - | - |  | - | MCMASTER | 92000A102 |  |  | 0.0378 |  | min. buy is pack of 100 |  | 0.2268
6 | AWK-105-0012 | - | NUT, METRIC M2 | 4 | COTS | NUT, METRIC M2 | - | - |  | - | MCMASTER | 91828A111 |  |  | 0.045 |  | min. buy pack of 100 |  | 0.18
7 | AWK-105-0014 | - | CONTROL KNOB | 2 | COTS | SKIRTED INSTRUMENT CONTROL KNOB, | - | - |  | - | DAVIES MOLDING | 1910 |  |  | 1.81 |  | QTY 250 |  | 3.62
8 | AWK-105-0019 | - | MAILER BOX | 1 | COTS | CARDBOARD SHIPPING BOX | - | - |  | - | ULINE |  |  |  | 0.58 |  | waiting for samples to fill in cost |  | 0.58
9 | AWK-105-0020 | A | STICKER, MAILER BOX | 1 | BUILD TO PRINT | 4"x 6" CUSTOM PERMANENT STICKER | AWK-105-0021 | A |  | - | ULINE | S-462 |  |  | 0.186 |  | cost for QTY 1000 |  | 0.186
 |  |  |  |  |  |  |  |  |  |  |  |  |  |  |  |  |  | BASIC COGS | 39.3178
 |  |  |  |  |  |  |  |  |  |  |  |  |  |  |  |  |  | COGS @QTY150 | 5897.67
 |  |  |  |  |  |  |  |  |  |  |  |  |  |  |  |  |  | TOOLING COST | 770
 |  |  |  |  |  |  |  |  |  |  |  |  |  |  |  |  |  | reverse 10% kickstarter | 740.8522222
 |  |  |  |  |  |  |  |  |  |  |  |  |  |  |  |  |  | MINIMUM BREAK EVEN | 7408.522222

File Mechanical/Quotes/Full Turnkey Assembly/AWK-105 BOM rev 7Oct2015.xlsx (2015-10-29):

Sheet: Intro
 | THE AWK-105 ANALOG VOLTMETER CLOCK
Notes:
* We assembled approx. 500 of the Model AWK-105 Analog Voltmeter Clocks as part of a Kickstarter fulfillment, with Awkward Engineer management procurement and overseeing assembly. We are now looking for a box build / PCBA turnkey vendor and quite happy and willing to pay someone else to do the work of purchasing, receiving, and assembling. We have a 3rd party logistics house the parts will ultimately be sent to that handles our fulfillment. * Box build assembly time on the Kickstarter was between 7-9 units per hour. We didn't have the use of high speed electric screw drivers with torque shutoffs, which I believe would help improve speed. We can provide sample parts for about 10 units for a time study. * We've highlighted generic items and critical items and in particular, identified items where we believe a CM can help with sourcing. (AA batteries, packing material, sheet metal vendor, other odds and ends) * We have two color variants, AWK-105GR, "Gray", and AWK-105OL, "Olive". * We're improving our test procedure and workign with our vendor for the analog meters. Suggested scrap rate for planning purposes is about 3%

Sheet: AWK-105 BOM rev 7Oct2015
 | light blue, generic part, open to alternates
 | light red, opportunity to find better source / alternate
 | purple: critical part, do not change
ITEM NO. | PART NUMBER | REV | DESCRIPTION | QTY. | TYPE | DETAILED DESCRIPTION | REFERENCE DRAWING / PROCEDURE | FINISH | Vendor | VendorNo | Manufacturer | ManufacturerNo | COST | COST NOTES
0 | AWK-105 | 2015-10-07 | TOP LEVEL | 1 | ASSEMBLY | TOP LEVEL ASSEMBLY | ASSEMBLY PROCEDURE: AWK-105-0025
1 | AWK-105-0004 | F | BOX, BACK FACE | 1 | BUILD TO PRINT | .050" SHEET METAL, ALUMINUM | FABRICATION DRAWING: AWK-105-0010 | POWDER COAT | CENTURY TYWOOD MFG CO |  |  |  | 17.95 | 16.60 @ QTY 500, 17.95 @QTY 250, $21.50 QTY 100
2 | AWK-105-0002 | F | BOX, FRONT FACE | 1 | BUILD TO PRINT | .050" SHEET METAL, ALUMINUM | FABRICATION DRAWING: AWK-105-0010 SCREENPRINT ARTWORK: AWK-105-0016, AWK-105-0017 | POWDER COATED, SCREEN PRINTED | CENTURY TYWOOD MFG CO |  |  |  | - | cost is rolled up un AWK-105-0004
3 | AWK-105-0005 | C | PCBA | 1 | ASSEMBLY | SEE ADDITIONAL TABS FOR PCBA DETAIL
4 | AWK-105-0001-H | - | VOLTMETER, HOURS | 1 | BUILT TO ORDER | 50uA ANALOG PANEL MOUNT AMMETER | PURCHASE SPEC: AWK-105-0034 | - | CHINA HOPE SUN / WENZHOU INSTRUMENT CO | PM-2, 50uA | CHINA HOPE SUN / WENZHOU INSTRUMENT CO | PM-2 50uA | 2.8 | @600, price was $3.40 with shipping included
5 | AWK-105-0001-M | - | VOLTMETER, MINUTES | 1 | BUILT TO ORDER | 50uA ANALOG PANEL MOUNT AMMETER | PURCHASE SPEC: AWK-105-0034 | - | CHINA HOPE SUN / WENZHOU INSTRUMENT CO | PM-2, 50uA | CHINA HOPE SUN / WENZHOU INSTRUMENT CO | PM-2 50uA | 2.8
6 | AWK-105-0018 | - | PHILLIPS PAN HEAD SCREW, METRIC M3 x 4mm, ZINC PLATE | 6 | COTS | PHILLIPS PAN HEAD SCREW, METRIC M3 x 4mm, 18-8 SS | - | - | MCMASTER | 92000A113 |  |  | 0.0378 | min. buy is pack of 100
7 | AWK-105-0012 | - | NUT, METRIC M2 | 4 | COTS | NUT, METRIC M2 | - | - | MCMASTER | 91828A111 |  |  | 0.045 | min. buy pack of 100
8 | AWK-105-0014 | - | CONTROL KNOB | 2 | COTS | ITEM #1910, SKIRTED KNOB, 1/4" SHAFT | - | - | DAVIES MOLDING | 1910 | DAVIES MOLDING | 1910 | 1.049 | @QTY 1200
9 | AWK-105-0032 | - | AA BATTERY | 1 | COTS | AA BATTERY | - |  | AMAZON | B00YCW3ZK4 |  |  | 0.436 | @QTY 48
10 | AWK-105-0019 | - | MAILER BOX | 1 | COTS | 6 1/2 x 4 7/8 x 3 3/4" Indestructo Mailers 100/bundle | - | - | ULINE | S-420 |  |  | 0.6 | @QTY 500
11 | AWK-105-0029 | - | WADDING | 1.25 | COTS | SOFT PACKAGING MATERIAL | - | - | ULINE | S-656 |  |  | 0.4 | USING 1.25 SHEETS PER BOX
12 | AWK-105-0033 | A | INSTRUCTION SHEET | 1 | BUILD TO PRINT | 8.5"x11", CUT IN HALF AND FOLDED | - | - | KINKOS | - |  |  | 0.05
13 | AWK-105-0035 | - | ADHESIVE STICKER DOT | 1 | COTS | 2" ROUND CLEAR ACETATE STICKER |  |  | ULINE | S-5504 |  |  | 0.028 | @QTY 1000 per roll
14 | AWK-105-0020 | A | STAMP | 1 | TOOLING | INK STAMP | AWK-105-0021 | - | - | - |  |  | -
15 | AWK-105-0100 | A | METER TEST RIG | 1 | TOOLING | 54 uA CURRENT SOURCE | - | - | - | - |  |  | -
16 |  |  | SHEET METAL LANCE TOOL | 1 | TOOLING | MANUAL KICKER PUNCH FORMING TOOL
17 |  |  | SCREEN PRINT SILK SCREENS | 1 | TOOLING | SILK SCREENS FOR FRONT AND TOP
18 |  |  | 4 MM EXTRA NARROW SOCKET DRIVER | 1 | TOOLING | 4 MM EXTRA NARROW SOCKET DRIVER

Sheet: PCBA Component List
light blue, generic part, open to alternates
light red, opportunity to find better source / alternate
purple: critical part, do not change
AWK-105-0005 | PCBA | Rev C | 2 Layer Board, 1 Side SMT, 2 Sides THRU Hole
Gerbers are in attached .zip
Description | ID | Manufacturer | Manufacturer Part Number | Supplier | Supplier Part Number | Reference Designators | Line Quantity | Order Quantity | Unit Price | Order Price
CLIP BATTERY AA PC MNT PAIR | KEYSTONE/92 | Keystone | 92 | Digi-Key | 92K-ND | BT1 BT2 | 2 | 1205 | 0.17133 | 206.45265
DNP | DNP |  |  |  |  | BT3 BT4 U2 DS1 DS2 C7 D1 SP1 D2 D3 SW1 Q2 R13 R14 R15 R4 Q1 P2 P3 P4 CON2 P1 CON1
CRYSTAL 32.7680KHZ 12.5PF SMD | ABRACON/ABS06-32.768KHZ-T | Abracon | ABS06-32.768KHZ-T | Avnet Express | ABS06-32.768KHZ-T/BKN | X1 | 1 | 600 | 0.7762 | 465.72
ENCODER ROTARY | BOURNS/PEC12R-2120F-N0012 | Bourns | PEC12R-2120F-N0012 | Digi-Key CUSTOM ORDER | PEC12R-2120F-N0012-ND | S1 | 1 | 600 | 0.54 | 324
IC CONV PIC MICROCTRLR SOT-23-6 | MICROCHIP/MCP1624T-I%2FCHY | Microchip | MCP1624T-I/CHY | Newark | 14T4084 | U1 | 1 | 605 | 0.332 | 200.86
CAP CER 12PF 50V 5% NP0 0805 | KEMET/C0805C120J5GACTU | Kemet | C0805C120J5GACTU | Newark | 64K2898 | C2 C4 | 2 | 1250 | 0.012 | 15
RES SMD 33K OHM 1% 1/8W 0805 | YAGEO/RC0805FR-0733KL | Yageo | RC0805FR-0733KL | Newark | 66R3219 | R7 R8 | 2 | 1250 | 0.003 | 3.75
RES SMD 10K OHM 5% 1/8W 0805 | PANASONIC/ERJ-6GEYJ103V | Panasonic | ERJ-6GEYJ103V | Master Electronics | ERJ6GEYJ103V | R12 R3 R9 | 3 | 1850 | 0.0029 | 5.365
CAP CER 10000PF 50V X7R 0805 | MURATA/GRM216R71H103KA01D | Murata | GRM216R71H103KA01D | Quest | GRM216R71H103KA01D | C5 C6 | 2 | 1250 | 0.0068 | 8.5
RES SMD 130K OHM 1% 1/8W 0805 | PANASONIC/ERJ-6ENF1303V | Panasonic | ERJ-6ENF1303V | Newark | 53W4728 | R5 | 1 | 650 | 0.002 | 1.3
RES SMD 200K OHM 1% 1/8W 0805 | PANASONIC/ERJ-6ENF2003V | Panasonic | ERJ-6ENF2003V | Newark | 97W7609 | R6 | 1 | 650 | 0.005 | 3.25
FIXED IND 4.7UH 30MA 1 OHM SMD | MURATA/LQM21NN4R7K10L | Murata | LQM21NN4R7K10L | Quest | LQM21NN4R7K10L | L1 | 1 | 650 | 0.08 | 52
RES SMD 0.0 OHM JUMPER 1/8W 0805 | PANASONIC/ERJ-6GEY0R00V | Panasonic | ERJ-6GEY0R00V | Newark | 97W7729 | R1 | 1 | 650 | 0.004 | 2.6
RES SMD 51K OHM 5% 1/8W 0805 | PANASONIC/ERJ-6GEYJ513V | Panasonic | ERJ-6GEYJ513V | Newark | 52W0327 | R10 R11 | 2 | 1250 | 0.002 | 2.5
CAP CER 10UF 10V 10% X7R 0805 | MURATA/GRM21BR71A106KE51L | Murata | GRM21BR71A106KE51L | Farnell | 1828828 | C1 C3 | 2 | 1250 | 0.01 | 12.5
IC MCU 8BIT 4KB FLASH 14SOIC | ATMEL/ATTINY24A-SSU | Atmel | ATTINY24A-SSU | Digi-Key CUSTOM ORDER | ATCC-1539-ND | IC1 | 1 | 600 | 1.05 | 630
Rotary Potentiometer | BOURNS/PTV111-2420A-B104 | Bourns | PTV111-2420A-B104 | Digi-Key CUSTOM ORDER | PTV111-2420A-B104 | R2 | 1 | 600 | 0.5 | 300

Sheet: SMT XY
ABRACON/ABS06-32.768KHZ-T | X1 | 123.262 | 95.682 | 0
DNP | Q2 | 75.615 | 87.8934 | 90
MICROCHIP/MCP1624T-I%2FCHY | U1 | 113.912 | 89.732 | 0
DNP | R13 | 131.262 | 79.682 | 90
DNP | R14 | 99.304 | 80.08 | 90
DNP | R15 | 149.984 | 79.68 | 90
KEMET/C0805C120J5GACTU | C2 | 124.562 | 99.482 | 270
KEMET/C0805C120J5GACTU | C4 | 122.162 | 99.502 | 270
YAGEO/RC0805FR-0733KL | R7 | 141.912 | 100.252 | 270
YAGEO/RC0805FR-0733KL | R8 | 77.562 | 96.402 | 180
PANASONIC/ERJ-6GEYJ103V | R12 | 148.742 | 89.535 | 180
PANASONIC/ERJ-6GEYJ103V | R3 | 79.044 | 87.8934 | 270
PANASONIC/ERJ-6GEYJ103V | R9 | 148.641 | 86.1568 | 0
MURATA/GRM216R71H103KA01D | C5 | 150.751 | 83.7778 | 0
MURATA/GRM216R71H103KA01D | C6 | 150.8 | 92.9386 | 0
PANASONIC/ERJ-6ENF1303V | R5 | 115.862 | 86.282 | 180
PANASONIC/ERJ-6ENF2003V | R6 | 112.162 | 86.282 | 180
MURATA/LQM21NN4R7K10L | L1 | 108.762 | 90.182 | 270
PANASONIC/ERJ-6GEY0R00V | R1 | 71.6026 | 88.9762 | 90
DNP | R4 | 67.9958 | 90.8812 | 180
PANASONIC/ERJ-6GEYJ513V | R10 | 152.832 | 86.1568 | 180
PANASONIC/ERJ-6GEYJ513V | R11 | 152.832 | 89.4334 | 180
MURATA/GRM21BR71A106KE51L | C1 | 110.962 | 88.982 | 270
MURATA/GRM21BR71A106KE51L | C3 | 117.162 | 89.782 | 270
ATMEL/ATTINY44A-SSU | IC1 | 125.26 | 89.6 | 0
DNP | Q1 | 67.6656 | 87.1474 | 0
DNP | CON2 | 91.186 | 122.53 | 0
DNP | P1 | 159.131 | 121.031 | 0
DNP | CON1 | 185.115 | 94.1578 | 270

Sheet: THRU HOLE, TOP AND BOTTOM
THRU HOLE COMPONENTS, TOP
KEYSTONE/92 | BT1 | 74.412 | 112.482 | 270
KEYSTONE/92 | BT2 | 107.962 | 112.482 | 90
DNP | BT3 | 141.212 | 112.482 | 270
DNP | BT4 | 174.762 | 112.482 | 90
DNP | U2 | 91.567 | 108.839 | 90
DNP | DS1 | 152.273 | 101.092 | 0
DNP | DS2 | 70.993 | 101.092 | 0
DNP | C7 | 83.947 | 106.807 | 180
DNP | D1 | 125.412 | 78.952 | 0
DNP | SP1 | 125.412 | 75.366 | 180
DNP | D2 | 100.828 | 76.016 | 0
DNP | D3 | 151.254 | 75.616 | 0
DNP | SW1 | 61.462 | 90.352 | 270
DNP | P2 | 173.736 | 121.158 | 0
DNP | P3 | 180.569 | 121.082 | 0
DNP | P4 | 80.4164 | 118.821 | 180
THRU HOLE COMPONENTS, BOTTOM
BOURNS/PTV111- | R2 | 67.437 | 80.777 | 0
BOURNS/PEC12R-4220F-S0024 | S1 | 181.737 | 80.777 | 0

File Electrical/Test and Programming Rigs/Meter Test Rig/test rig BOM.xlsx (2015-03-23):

3D Printed Case
Line Number | Part number | Description | Qty | Total Qty (@ Batch Size: 3)
1 | AWK-105-0101 | case CAD model | 1 | 3
Printed Circuit Board
Line Number | Part number | Description | Qty | Total Qty (@ Batch Size: 3)
2 | meter test rig 21Mar2015.zip | gerber files for getting PCB made | 1 | 3
Components from Digikey
Line Number | Part number | Description | Qty | Total Qty (@ Batch Size: 3) | SKU | Notes
~~2.03~~ | ~~BK-92~~ | ~~BATTERY_CLIP~~ | ~~2~~ | ~~6~~ | ~~BK-92-ND~~ | through hole part not in stock
2.03 | BK-53-TR | BATTERY_CLIP | 2 | 6 | BK-53-CT-ND | surface mount part I will try to use
2.03 | 2461K-ND (http://www.digikey.com/product-detail/en/2461/2461K-ND/303810) | BATTERY_CLIP | 1 | 3 | 2461K-ND (http://www.digikey.com/product-detail/en/2461/2461K-ND/303810) | extra part I want to keep on hand to try
2.04 | GRM21BR61A106KE19L | CAP CER 10UF 10V 10% X5R 0805 | 2 | 6 | 490-1709-6-ND | this part is rated X5 for the dielectric constant, as recommended on the MCP1624 data sheet
2.05 | C5SMF-RJS-CT0W0BB2 | LED | 1 | 3 | C5SMF-RJS-CT0W0BB2CT-ND | this part was used on the first clock build
2.06 | LQM21NN4R7K10L | 4.7uH | 1 | 3 | 490-6689-6-ND
2.07 | ERJ-6GEYJ221V | 220 | 1 | 3 | P220ACT-ND
2.08 | ERA6AEB363V | 36K | 1 | 3 | P36KDACT-ND
2.09 | ERJ-6ENF1303V | 130K | 1 | 3 | P130KCDKR-ND
2.10 | ERJ-6ENF2003V | 200K | 1 | 3 | P200KCCT-ND
2.11 | M2011SS1W01/UC | SPST | 1 | 3 | 360-3289-ND
2.12 | MCP1624T-I/CHY | MCP1624 | 1 | 3 | MCP1624T-I/CHYCT-ND | screws
2.13 | H703-ND | Screws | 2 | 6 | H703-ND
2.14 | 952-1962-ND | Standoffs | 2 | 6 | 952-1962-ND

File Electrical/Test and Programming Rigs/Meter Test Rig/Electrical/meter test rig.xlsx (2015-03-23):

PART NUMBER | QTY | REF
BATTERY_CLIP | 2 | BT1 BT2
10uF | 2 | C1 C2
LED | 1 | D1
4.7uH | 1 | L1
CONN_2 | 1 | P1
220 | 1 | R1
36K | 1 | R4
130K | 1 | R2
200K | 1 | R3
 | 2 | R5 R6
SPST | 1 | SW1
MCP1624 | 1 | U1

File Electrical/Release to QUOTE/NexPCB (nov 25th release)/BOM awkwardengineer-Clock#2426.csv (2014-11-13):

Line | Description | ID | Manufacturer | Manufacturer Part Number | Alternates | Supplier | Supplier Part Number | Reference Designators | Line Quantity | Datasheet 1 | Datasheet 2 | Datasheet 3 | Datasheet 4 | Datasheet 5 | Datasheet 6 | Datasheet 7 | Datasheet 8 | Datasheet 9 | Datasheet 10 | Datasheet 11 | Datasheet 12 | Datasheet 13 | Datasheet 14 | Datasheet 15 | Datasheet 16 | Datasheet 17
1 | DNP | DNP |  |  |  |  |  | CON1 Q1 R13 R14 R15 R4 Q2 SW1 D2 D3 SP1 D1 DS1 DS2
2 | IC MCU 8BIT 4KB FLASH 14SOIC | ADESTO/ATTINY44V-10SSU | Adesto Technologies | ATTINY44V-10SSU | ATTINY84V-10SSU ATTINY84-20SSU ATTINY44V-10SSU ATTINY44A-SSU ATTINY44-20SSU | Arrow | ATTINY44V-10SSU | IC1 | 1
3 | CAP CER 10UF 16V 10% X5R 0805 | TE2/GRM21BR61C106KE15L | TDK-EPC | GRM21BR61C106KE15L | open | Mouser | GRM21BR61C106KE15L | C1 C3 | 2 | http://www.murata.com/products/catalog/pdf/c02e.pdf | http://datasheet.octopart.com/GRM21BR61C106KE15L-Murata-datasheet-8326434.pdf | http://datasheet.octopart.com/GRM21BR61C106KE15L-Murata-datasheet-14397509.pdf
4 | RES 51.0K OHM 1/8W 1% 0805 SMD | DALE/CRCW080551K0FKEA | Dale | CRCW080551K0FKEA | open | Newark | 27W4713 | R1 R10 R11 R3 | 4
5 | INDUCTOR 4.7UH 30MA 0805 | MURATA/LQM21NN4R7K10L | Murata | LQM21NN4R7K10L | open | Future Electronics | LQM21NN4R7K10L | L1 | 1
6 | RES 200K OHM 1/8W 1% 0805 SMD | ECG/ERJ-6ENF2003V | ECG | ERJ-6ENF2003V | open | Mouser | ERJ-6ENF2003V | R6 | 1
7 | RES 130K OHM 1/8W 1% 0805 SMD | ECG/ERJ-6ENF1303V | ECG | ERJ-6ENF1303V | open | Mouser | ERJ-6ENF1303V | R5 | 1
8 | CAP CER 10000PF 50V 10% X7R 0805 | AVX2/08055C103KAT2A | AVX / Kyocera | 08055C103KAT2A | open | Newark | 19C6332 | C5 C6 | 2 | http://datasheet.octopart.com/0603ZD105KAT2A-AVX-datasheet-5383.pdf | http://datasheet.octopart.com/08055C104KAT2A-AVX-datasheet-8113618.pdf | http://datasheet.octopart.com/08055C104KAT2A-AVX-datasheet-167033.pdf | http://datasheet.octopart.com/08055C104KAT2A-AVX-datasheet-12509786.pdf | http://datasheet.octopart.com/08055C104KAT2A-AVX-datasheet-12587061.pdf | http://datasheet.octopart.com/08055C104KAT2A-AVX-datasheet-111406.pdf | http://datasheet.octopart.com/08055C104KAT2A-AVX-datasheet-4352.pdf | http://datasheet.octopart.com/08055C104KAT2A-AVX-datasheet-5313617.pdf | http://datasheet.octopart.com/08055C104KAT2A-AVX-datasheet-11546901.pdf | http://datasheet.octopart.com/08055C104KAT2A-AVX-datasheet-8446237.pdf | http://datasheet.octopart.com/08055C104KAT2A-AVX-datasheet-148183.pdf | http://datasheet.octopart.com/08055C104KAT2A-AVX-datasheet-5377487.pdf | http://datasheet.octopart.com/08055C104KAT2A-AVX-datasheet-119053.pdf | http://datasheet.octopart.com/08055C104KAT2A-AVX-datasheet-75321.pdf | http://datasheet.octopart.com/08055C104KAT2A-AVX-datasheet-899.pdf | http://datasheet.octopart.com/06035C103KAT2A-AVX-datasheet-499018.pdf | http://datasheet.octopart.com/08055C103KAT2A-AVX-datasheet-7840860.pdf
9 | RES 10K OHM 1/8W 5% 0805 SMD | PANASONIC/ERJ-6GEYJ103V | Panasonic | ERJ-6GEYJ103V | open | Mouser | ERJ-6GEYJ103V | R12 R9 | 2
10 | RES 36K OHM 1/8W .1% 0805 SMD | ECG/ERA6AEB363V | ECG | ERA6AEB363V | open | Mouser | ERA-6AEB363V | R7 R8 | 2 | http://datasheet.octopart.com/ERA3AEB104V-Panasonic-datasheet-13381385.pdf | http://datasheet.octopart.com/ERA3AEB104V-Panasonic-datasheet-8367715.pdf | http://datasheet.octopart.com/ERA3AEB104V-Panasonic-datasheet-13327109.pdf | http://datasheet.octopart.com/ERA-3AEB104V-Panasonic-datasheet-118567.pdf | http://datasheet.octopart.com/ERJ-6GEYJ122V-Panasonic---ECG-datasheet-15994758.pdf | http://datasheet.octopart.com/ERA2AEB103X-Panasonic-datasheet-10050158.pdf
11 | CAP CER 12PF 50V 5% NPO 0805 | YAGEO/CC0805JRNPO9BN120 | Yageo | CC0805JRNPO9BN120 | open | Future Electronics | CC0805JRNPO9BN120 | C2 C4 | 2
12 | IC CONV PIC MICROCTRLR SOT-23-6 | MICROCHIP/MCP1624T-I%2FCHY | Microchip | MCP1624T-I/CHY | - | Mouser | MCP1624T-I/CHY | U1 | 1
13 | CRYSTAL 32.768KHZ 12.5PF THRU | ABRACON/AB38T-32.768KHZ | Abracon | AB38T-32.768KHZ | open | Digi-Key | 535-9034-ND | X1 | 1
14 | CLIP CONTACT BATTERY AA SMD | MPD/BK-53-TR | MPD | BK-53-TR | open | Digi-Key | BK-53DKR-ND | BT1 BT2 BT3 BT4 | 4
15 | ENCODER ROTARY | BOURNS/PEC12R-2117F-N0024 | Bourns | PEC12R-2117F-N0024 | PEC12R-2120F-N0012 PEC12R-2117F-N0024 PEC12R-2117F-N0012 PEC12R-2217F-N0012 PEC12R-2220F-N0024 PEC12R-2217F-N0024 | Mouser | PEC12R-2117F-N0024 | S1 | 1 | http://datasheet.octopart.com/PEC12R-2117F-N0024-Bourns-datasheet-16722599.pdf
16 | POTENTIOMETER |  | Bourns | open | PTV111-2420A-B203 PTV111-2415A-B103 PTV111-2415A-A105 |  |  | R2 | 1

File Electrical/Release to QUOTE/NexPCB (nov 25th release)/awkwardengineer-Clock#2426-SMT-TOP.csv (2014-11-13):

ID | Manufacturer Part Number | Reference Designator | Xmm | Ymm | Rotation
DNP | DNP | CON1 | 260.553 | 200.076 | 270
DNP | DNP | Q1 | 163.754 | 195.047 | 90
ADESTO/ATTINY44V-10SSU | ATTINY44V-10SSU | IC1 | 200.698 | 195.518 | 0
TE2/GRM21BR61C106KE15L | GRM21BR61C106KE15L | C1 | 186.4 | 194.9 | 270
TE2/GRM21BR61C106KE15L | GRM21BR61C106KE15L | C3 | 192.6 | 195.7 | 270
DNP | DNP | R13 | 206.7 | 185.6 | 90
DNP | DNP | R14 | 174.742 | 185.998 | 90
DNP | DNP | R15 | 225.422 | 185.598 | 90
DALE/CRCW080551K0FKEA | CRCW080551K0FKEA | R1 | 163.982 | 191.922 | 180
DALE/CRCW080551K0FKEA | CRCW080551K0FKEA | R10 | 228.27 | 192.075 | 180
DALE/CRCW080551K0FKEA | CRCW080551K0FKEA | R11 | 228.27 | 195.351 | 180
DALE/CRCW080551K0FKEA | CRCW080551K0FKEA | R3 | 157.251 | 195.453 | 270
DNP | DNP | R4 | 163.881 | 198.044 | 180
MURATA/LQM21NN4R7K10L | LQM21NN4R7K10L | L1 | 184.2 | 196.1 | 270
ECG/ERJ-6ENF2003V | ERJ-6ENF2003V | R6 | 187.6 | 192.2 | 180
ECG/ERJ-6ENF1303V | ERJ-6ENF1303V | R5 | 191.3 | 192.2 | 180
AVX2/08055C103KAT2A | 08055C103KAT2A | C5 | 226.289 | 188.646 | 0
AVX2/08055C103KAT2A | 08055C103KAT2A | C6 | 226.238 | 198.857 | 0
PANASONIC/ERJ-6GEYJ103V | ERJ-6GEYJ103V | R12 | 224.18 | 195.453 | 180
PANASONIC/ERJ-6GEYJ103V | ERJ-6GEYJ103V | R9 | 224.079 | 192.075 | 0
ECG/ERA6AEB363V | ERA6AEB363V | R7 | 217.35 | 206.17 | 270
ECG/ERA6AEB363V | ERA6AEB363V | R8 | 153 | 202.32 | 180
YAGEO/CC0805JRNPO9BN120 | CC0805JRNPO9BN120 | C2 | 200 | 205.4 | 270
YAGEO/CC0805JRNPO9BN120 | CC0805JRNPO9BN120 | C4 | 197.6 | 205.42 | 270
MICROCHIP/MCP1624T-I%2FCHY | MCP1624T-I/CHY | U1 | 189.35 | 195.65 | 0
DNP | DNP | Q2 | 153.822 | 195.453 | 90
MPD/BK-53-TR | BK-53-TR | BT1 | 147.32 | 220.985 | 270
MPD/BK-53-TR | BK-53-TR | BT2 | 187.325 | 220.985 | 90
MPD/BK-53-TR | BK-53-TR | BT3 | 214.63 | 220.985 | 270
MPD/BK-53-TR | BK-53-TR | BT4 | 253.365 | 220.985 | 90

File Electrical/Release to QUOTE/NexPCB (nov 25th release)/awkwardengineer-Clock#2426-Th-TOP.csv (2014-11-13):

ID | Manufacturer Part Number | Reference Designator | Xmm | Ymm | Rotation
DNP | DNP | SW1 | 136.9 | 196.27 | 270
DNP | DNP | D2 | 176.266 | 181.934 | 0
DNP | DNP | D3 | 226.692 | 181.534 | 0
DNP | DNP | SP1 | 200.85 | 181.284 | 180
DNP | DNP | D1 | 200.85 | 184.87 | 0
ABRACON/AB38T-32.768KHZ | AB38T-32.768KHZ | X1 | 198.7 | 201.6 | 180
DNP | DNP | DS1 | 222.59 | 207.075 | 0
DNP | DNP | DS2 | 151.47 | 207.075 | 0
DNP | DNP | R2 | 142.875 | 186.695 | 180
BOURNS/PEC12R-2117F-N0024 | PEC12R-2117F-N0024 | S1 | 257.175 | 186.695 | 180

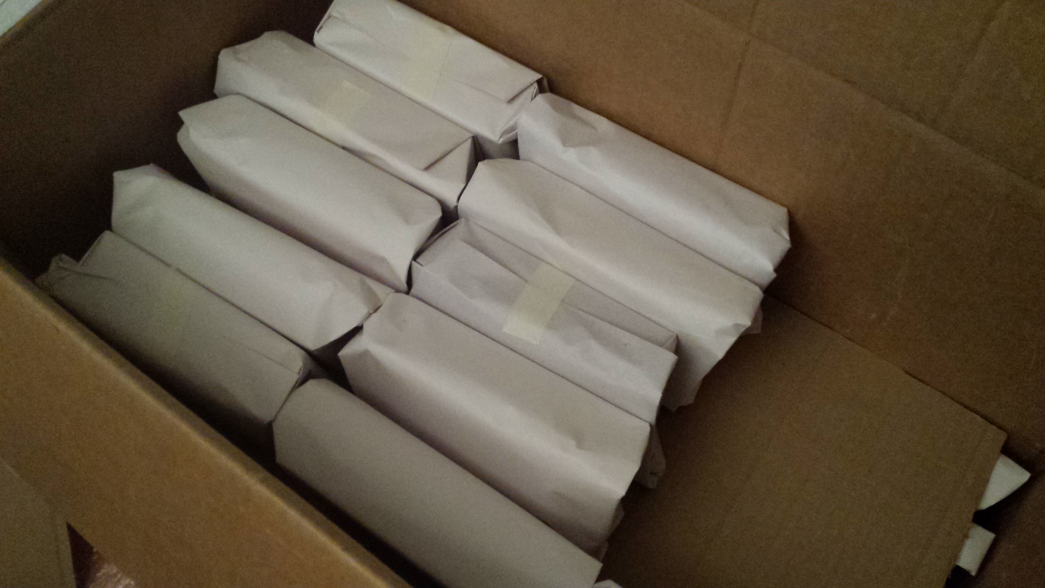
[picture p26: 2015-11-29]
Photos/Blog Post Material/March/bts 2.jpg

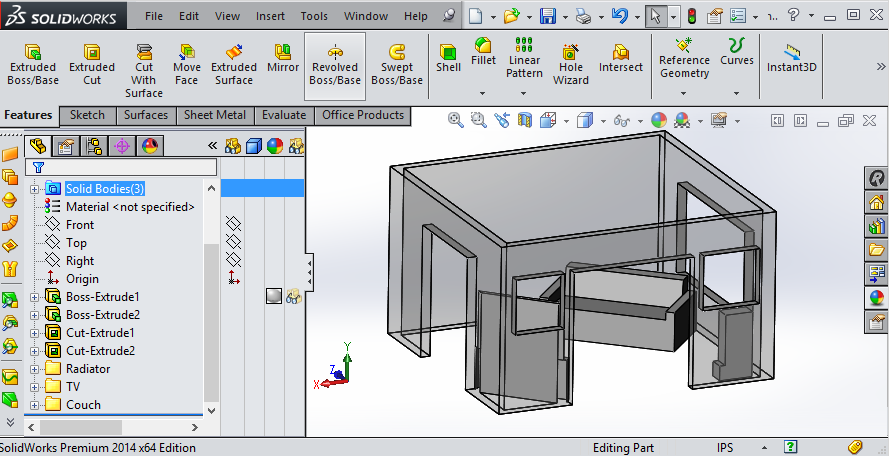
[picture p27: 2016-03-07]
Photos/Blog Post Material/houseCAD.PNG

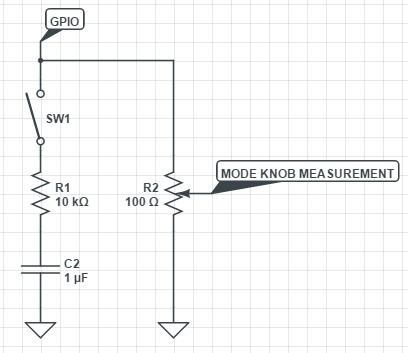
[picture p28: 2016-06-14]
Photos/Blog Post Material/capsense.PNG

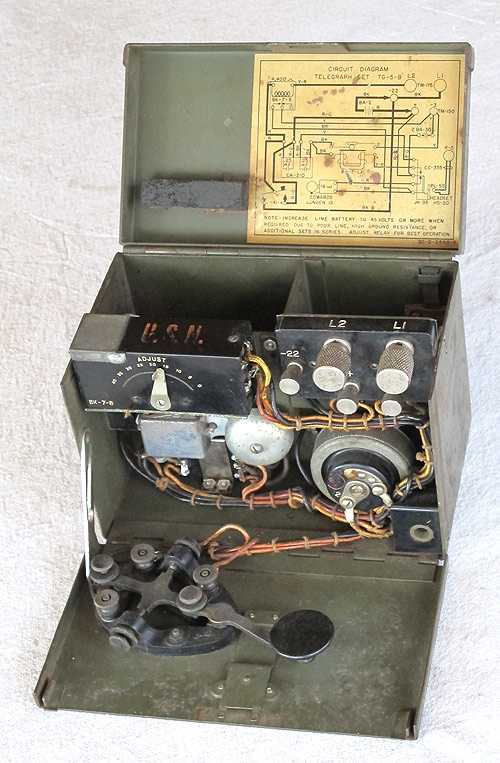
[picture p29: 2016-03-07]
Photos/Blog Post Material/March/tbt 1.jpg

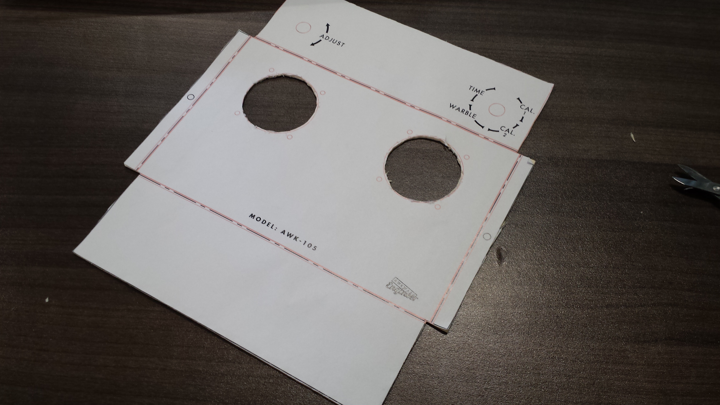
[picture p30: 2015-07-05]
Photos/Blog Post Material/March/bts 5.jpg

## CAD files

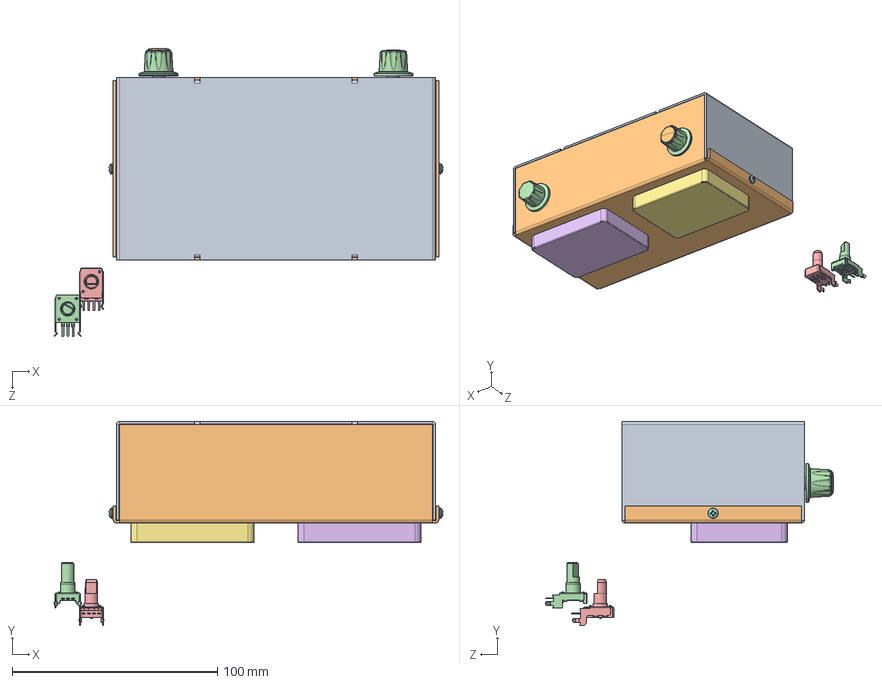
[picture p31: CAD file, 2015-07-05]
Mechanical/Quotes/Case/Rev D Case Quote Package/AWK-105-0003 revD.SLDASM
189.4 x 99.5 x 140.3 mm
AWK-105-0004
AWK-105-0002
AWK-105-0005
AWK-105-0001-H
AWK-105-0001-M
AWK-105-0018 x 3
AWK-105-0012 x 4
AA_BATTERY x 2
AWK-105-0014 Cosmetic x 2

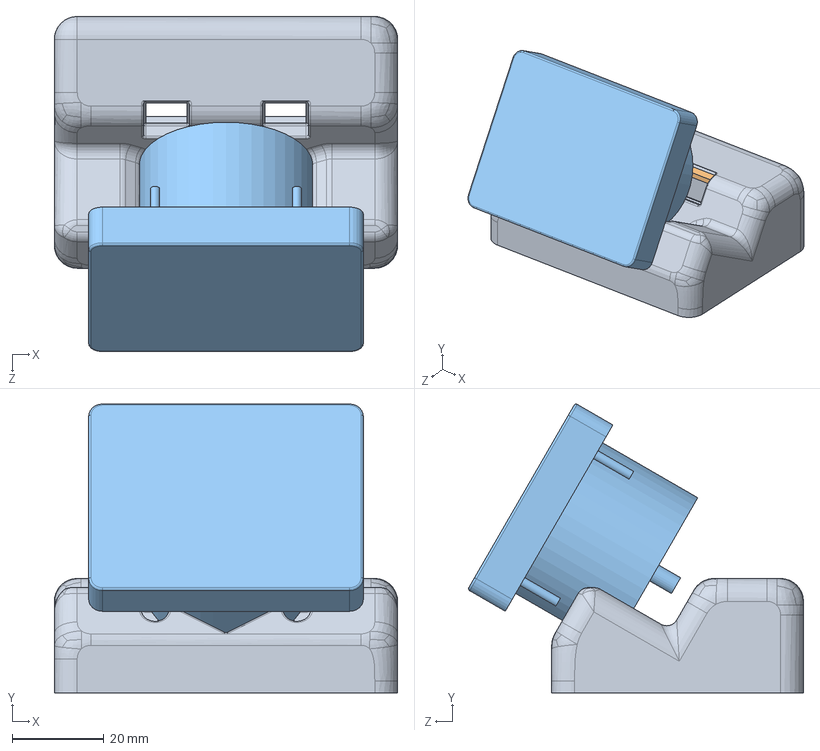
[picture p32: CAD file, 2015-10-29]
Electrical/Test and Programming Rigs/Meter Test Rig/CAD/AWK-105-100.SLDASM
75.0 x 63.1 x 73.2 mm
AWK-105-0101
board outline
AWK-105-0001

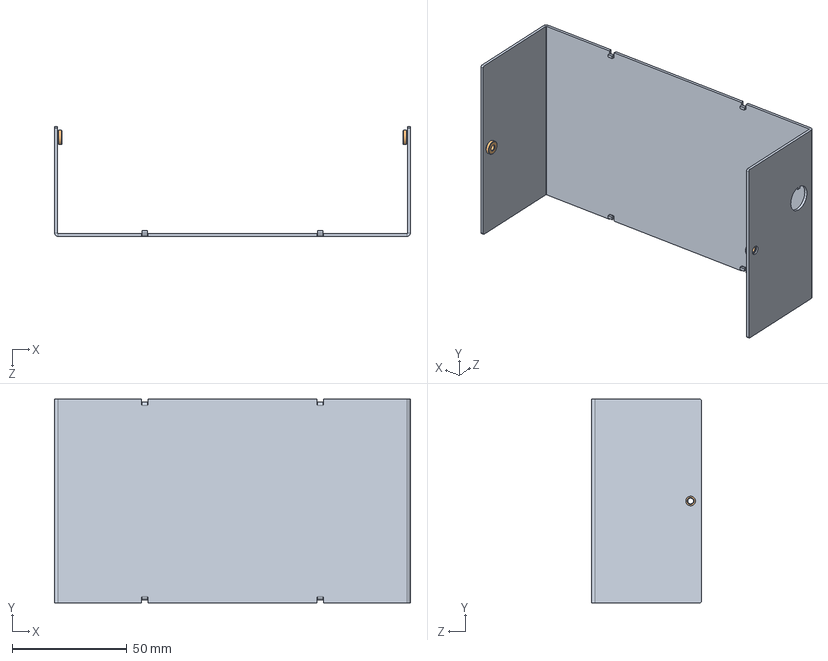
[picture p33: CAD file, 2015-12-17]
Mechanical/CAD/AWK-105-0004.SLDASM
155.4 x 88.9 x 48.0 mm
AWK-105-0004
AWK-105-0036 x 2

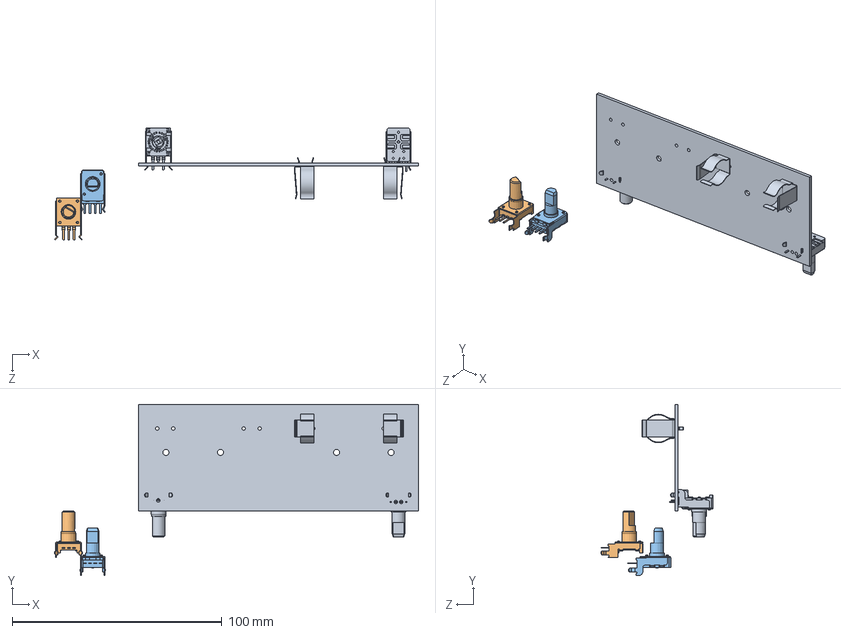
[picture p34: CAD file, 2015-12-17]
Mechanical/CAD/AWK-105-0005.SLDASM
173.4 x 81.5 x 53.5 mm

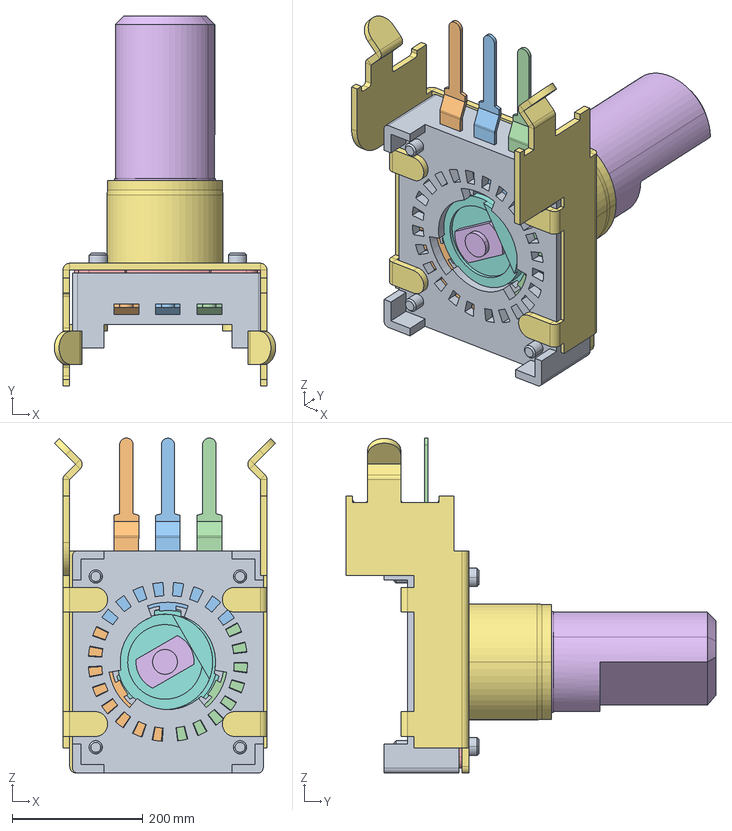
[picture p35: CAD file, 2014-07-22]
Mechanical/Reference Material/pec12r-2020f-n0012_asm.stp
338.8 x 566.4 x 513.1 mm
PRT0002
ED12JCP-15
ED12TP-1
EI12009S
ED1215ZJ
ED12ZX-1

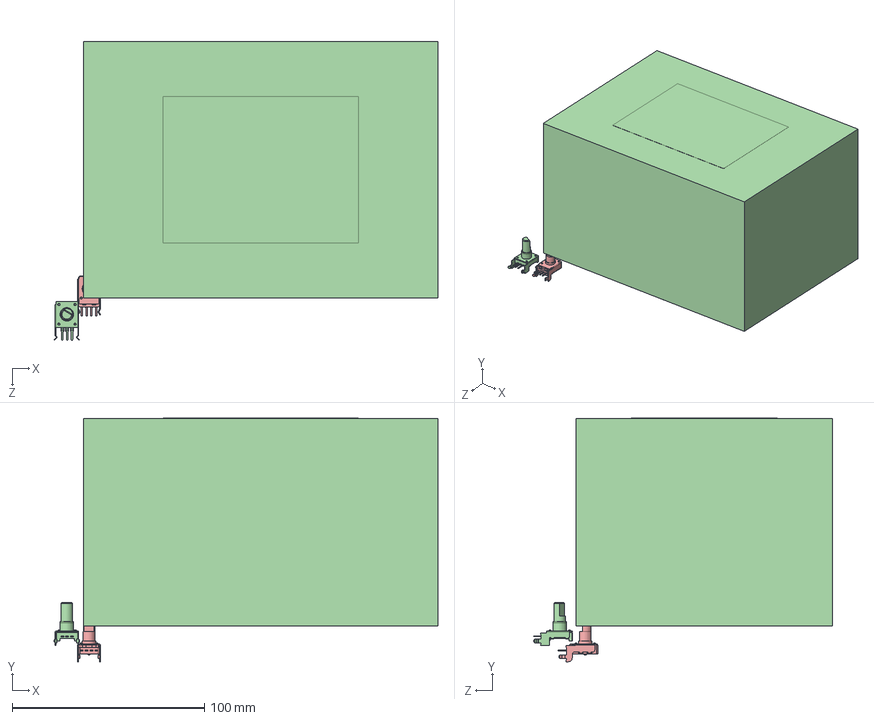
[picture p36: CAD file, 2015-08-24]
Mechanical/CAD/AWK-105-0003.SLDASM
199.6 x 126.6 x 155.2 mm
AWK-105-0002
AWK-105-0005
AWK-105-0001-H
AWK-105-0001-M
AWK-105-0018 x 6
AWK-105-0012 x 4
AA_BATTERY
AWK-105-0014 Cosmetic x 2

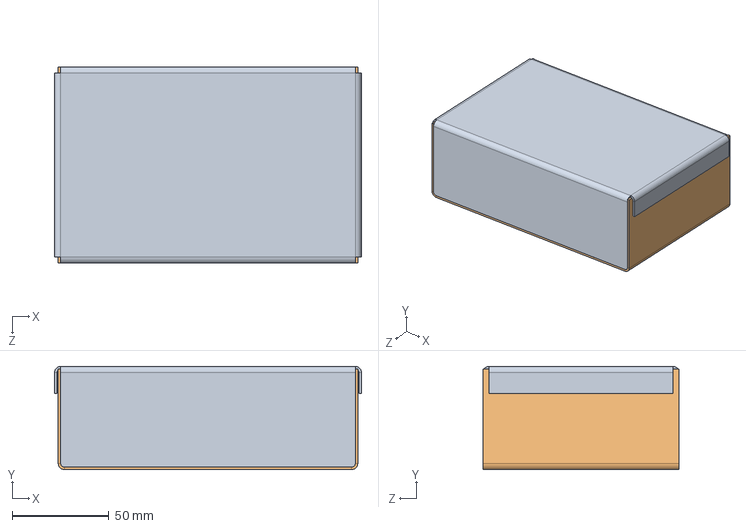
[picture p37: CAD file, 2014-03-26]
Mechanical/CAD/clock.SLDASM
158.8 x 53.4 x 101.6 mm
A SIDE
B SIDE

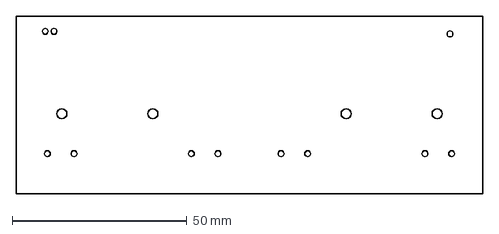
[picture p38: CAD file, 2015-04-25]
Electrical/Board Design/AWK-105-0005 boardoutline.DXF
133.3 x 50.8 mm

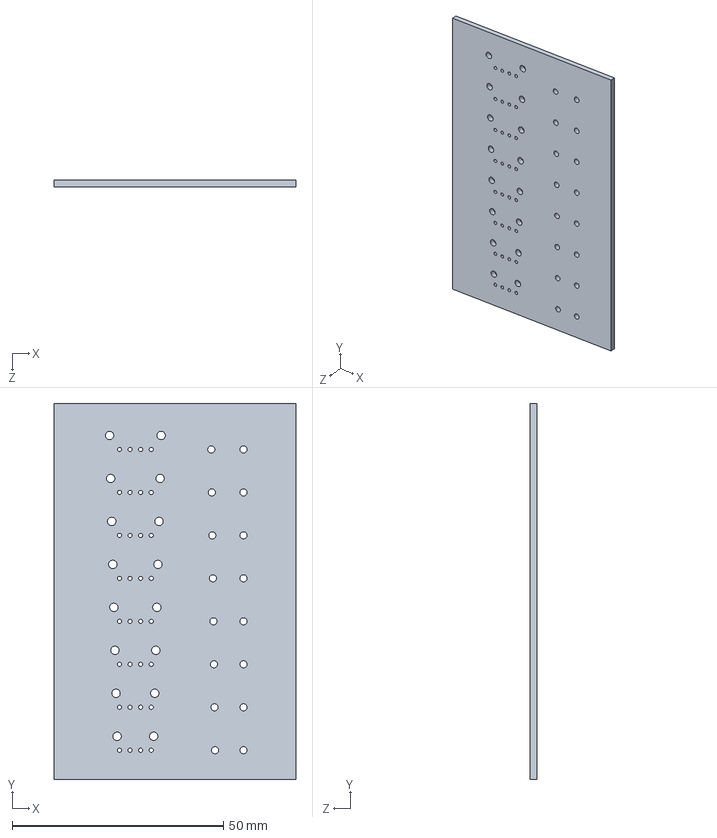
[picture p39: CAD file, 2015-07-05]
Electrical/Design Memos/footprint test/footprint test 2.SLDPRT
57.2 x 88.9 x 1.59 mm

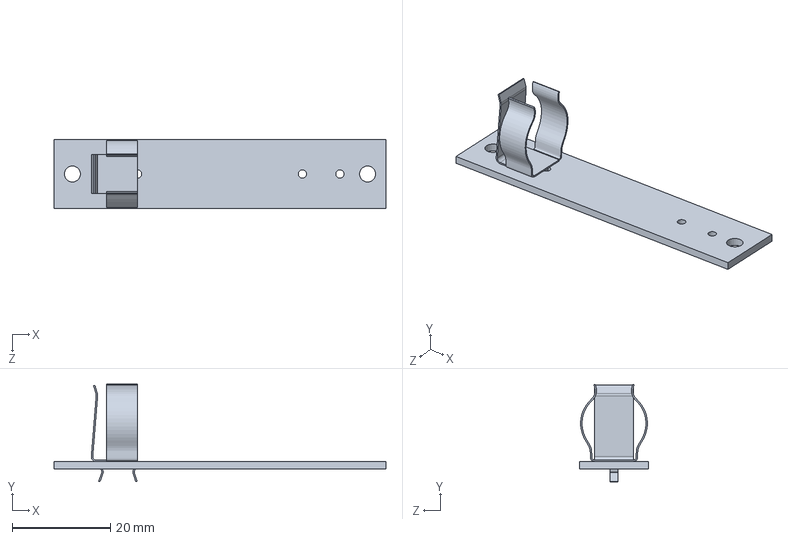
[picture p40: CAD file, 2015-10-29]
Electrical/Test and Programming Rigs/Meter Test Rig/CAD/board outline.SLDPRT
67.5 x 19.8 x 14.0 mm

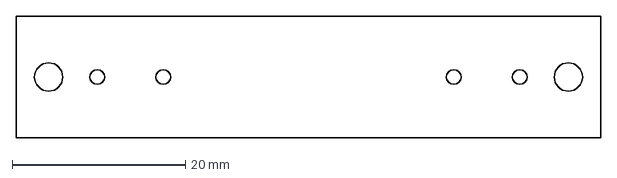
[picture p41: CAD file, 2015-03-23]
Electrical/Test and Programming Rigs/Meter Test Rig/Electrical/board outline.DXF
67.5 x 14.0 mm

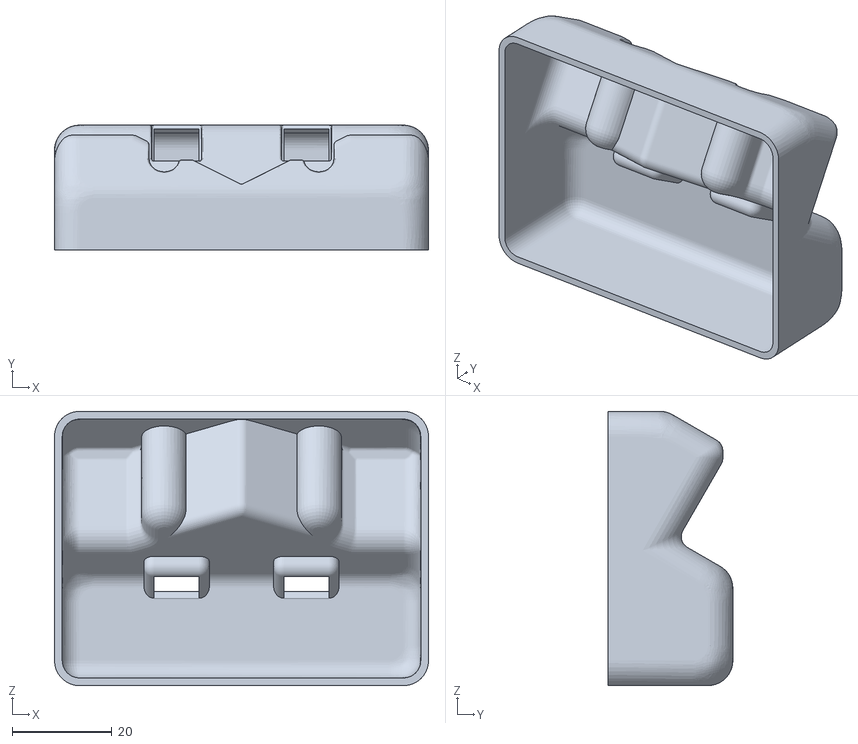
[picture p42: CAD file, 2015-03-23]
Electrical/Test and Programming Rigs/Meter Test Rig/for 3d Print/AWK-105-0101 v1.STL
75.0 x 25.0 x 55.0

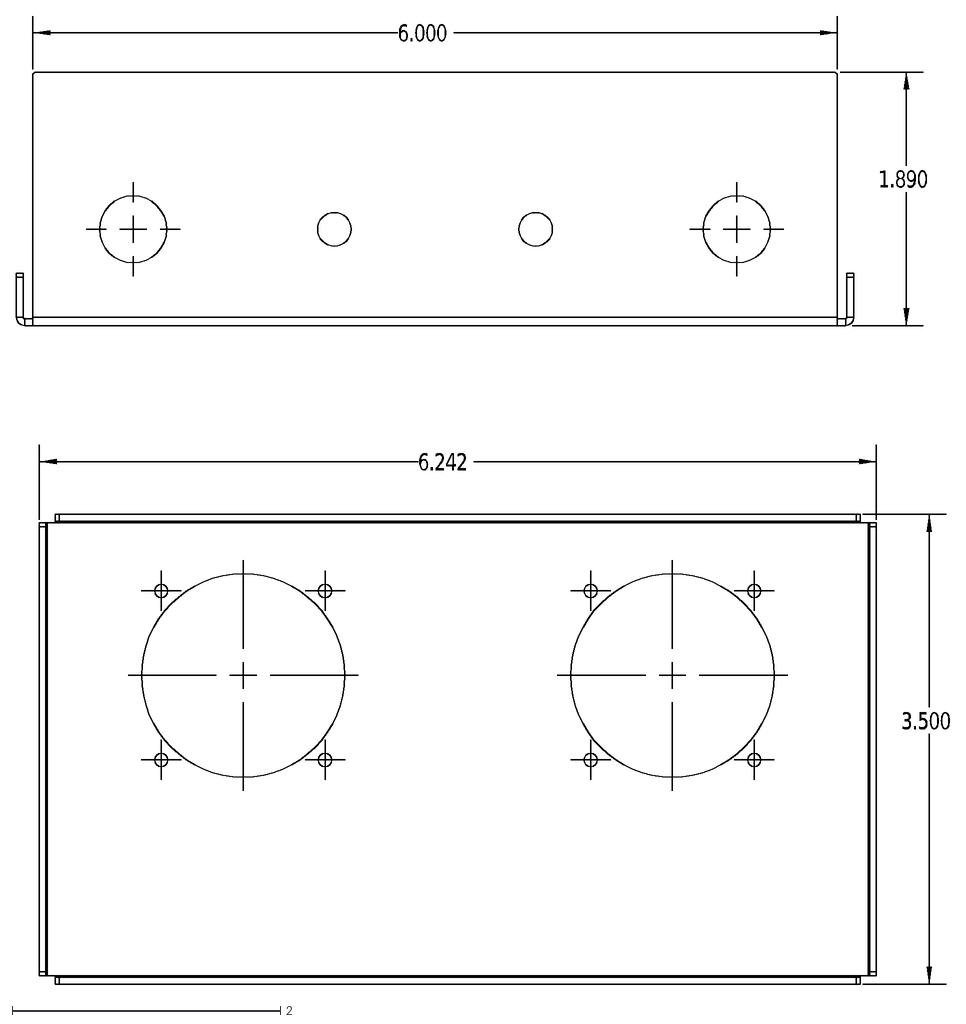
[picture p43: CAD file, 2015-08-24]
Mechanical/Artwork/REFERENCE box outlines alarm.DXF
6.000
1.890
6.242
3.500

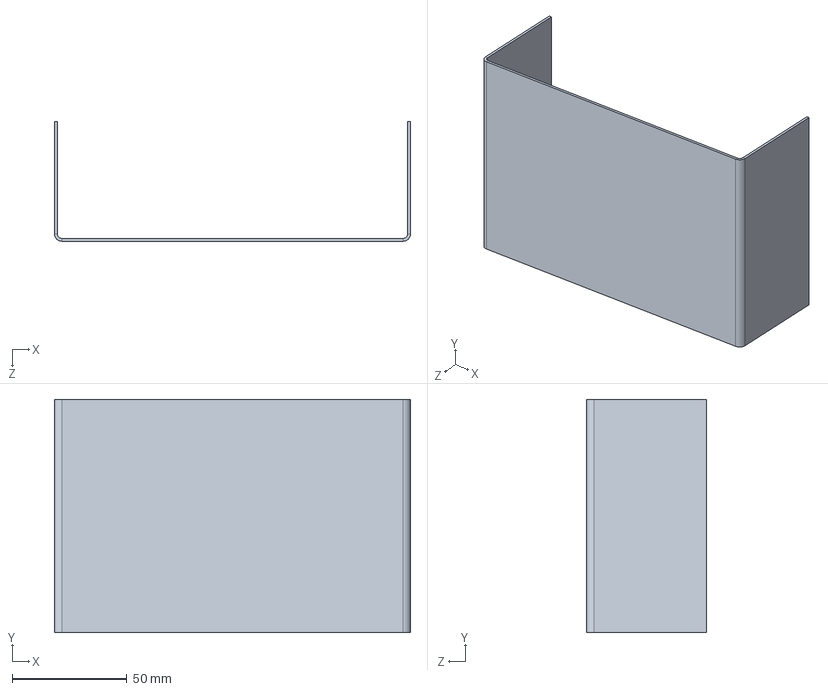
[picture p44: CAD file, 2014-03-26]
Mechanical/B SIDE.SLDPRT
155.0 x 101.6 x 52.1 mm

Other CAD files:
Mechanical/CAD/AWK-105-0002.SLDPRT
Mechanical/Design Memos/meter front face paper cutout/front face cutout.SLDPRT
Mechanical/Quotes/Case/AWK-105-0004 revH.SLDPRT
Mechanical/Reference Material/BK-92.STEP
Electrical/Design Memos/footprint test/footprint test 2.dxf
Electrical/Design Memos/footprint test/footprint test.SLDPRT
Electrical/Design Memos/footprint test/footprint test.dxf
Electrical/Design Memos/footprint test/footprint test.step
Electrical/Test and Programming Rigs/Meter Test Rig/CAD/AWK-105-0101.SLDPRT
Mechanical/A SIDE.SLDPRT
Mechanical/Artwork/Archive/Archive 2/dial overlay sketch model.SLDPRT
Mechanical/Artwork/Archive/Archive 2/dials.DXF
Mechanical/Artwork/Archive/Archive 2/face plate CAD layout.SLDPRT
Mechanical/Artwork/Archive/REFERENCE box outlines.DXF
Mechanical/Artwork/REFERENCE back flat pattern.DXF
Mechanical/Artwork/REFERENCE box outlines.DXF
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

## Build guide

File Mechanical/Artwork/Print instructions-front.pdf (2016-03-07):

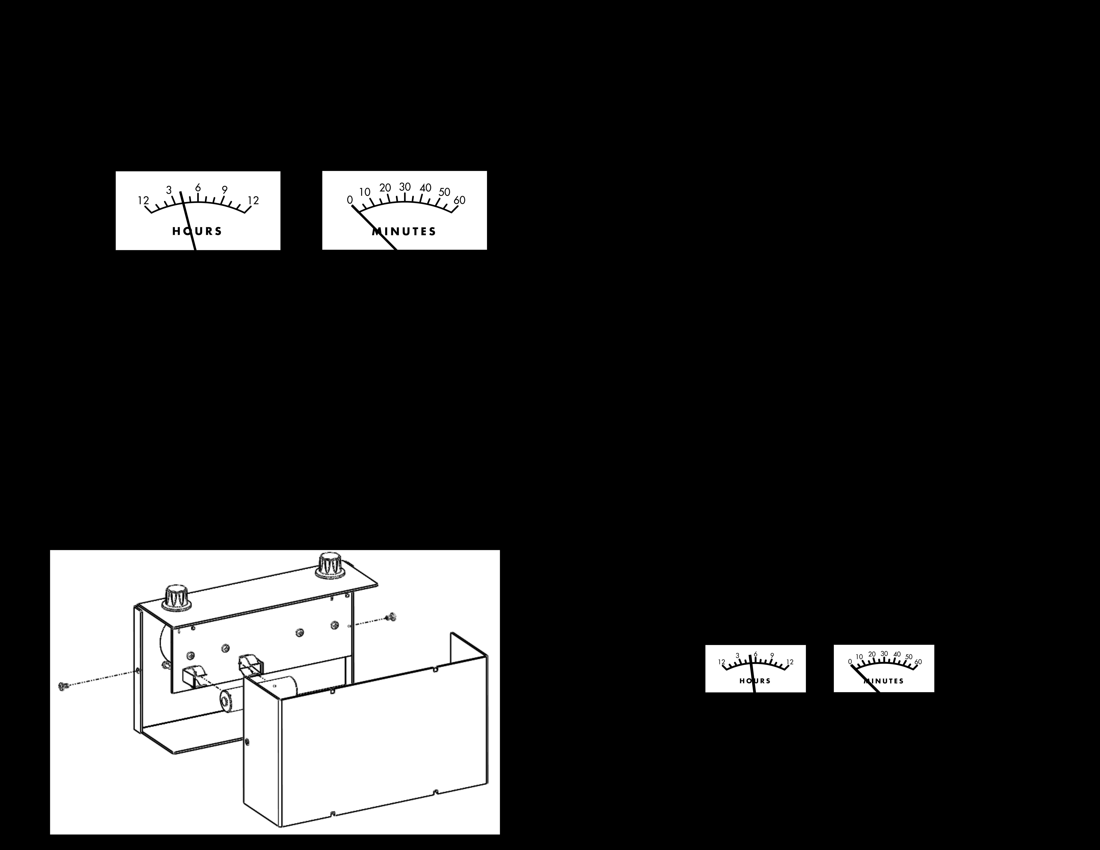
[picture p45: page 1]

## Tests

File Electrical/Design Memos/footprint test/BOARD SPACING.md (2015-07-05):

***CLOCK BATTERY FOOTPRINT NOTES***

The BK-92 footprint, when ordered from OSHPARK, didn't quite fit. The holes were too wide for the clip.  

Between the footprint, the part, and the as built, I could only confirm that the digital footprint was correct.  

I do know that opening one hole with a 5/64" bit improved the fit, and opening both holes made one clip fit perfectly, but a second clip was a bit loose. If a 4/64" bit ran cleanly, and opening it up 1/64" made it fit better, it means, the hole edges actually moved half a 64th closer together, which is .0078". It's really hard to make accurate measurements with the roughed over caliper edges, but I think the approach is to move the holes closer together by .010"

***RESULTS OF LASER CUT TEST PART*** 

"footprint test 2.sldprt" was laser cut in 1/16" THK acrylic. the following hole spacings had the best fits 

battery clips: .290" center to center 
potentiometer: .440" center to center

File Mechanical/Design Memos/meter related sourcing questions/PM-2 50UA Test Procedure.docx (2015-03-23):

PM-2 50UA Test Procedure：

1、 Test “Zero” position

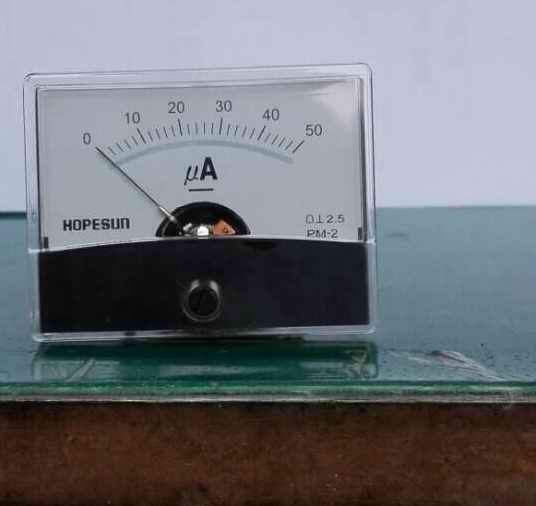
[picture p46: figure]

2、 The balance test at 45degree, horizontal and vertical

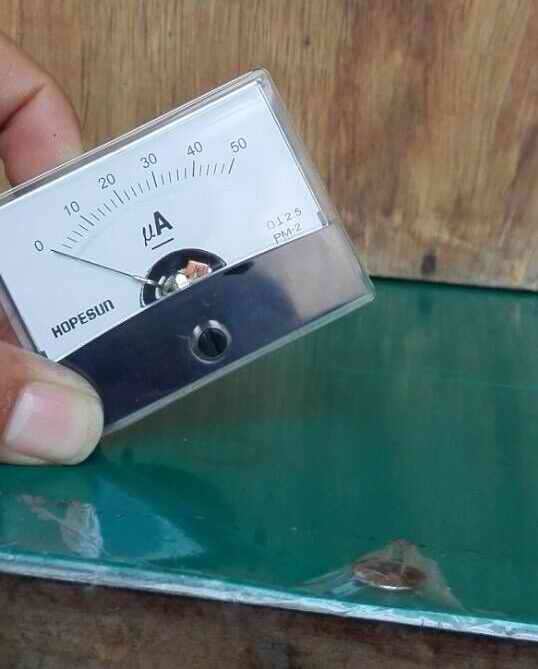
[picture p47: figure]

3、Test the scale between Zero and full scale

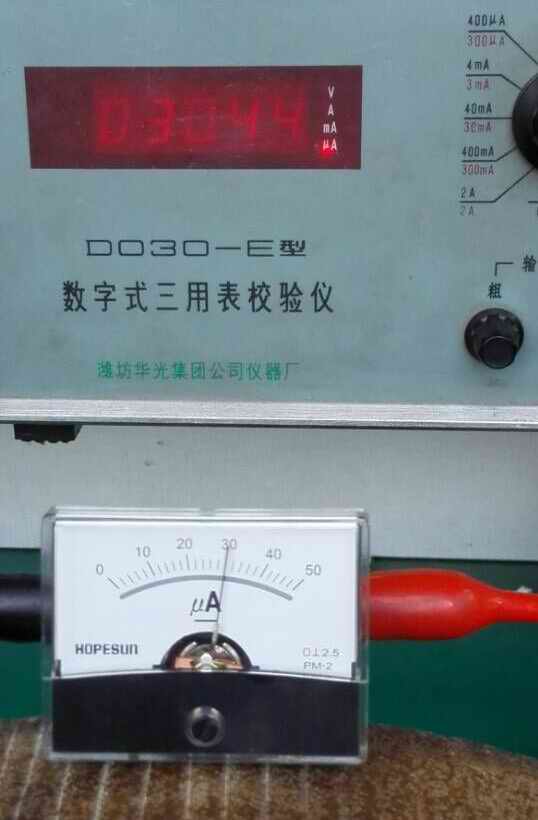
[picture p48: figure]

4、 Test at full scale

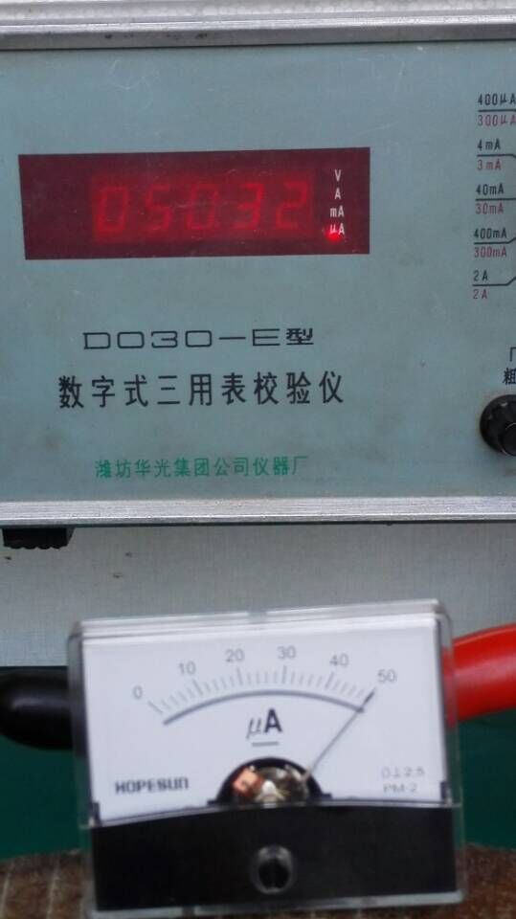
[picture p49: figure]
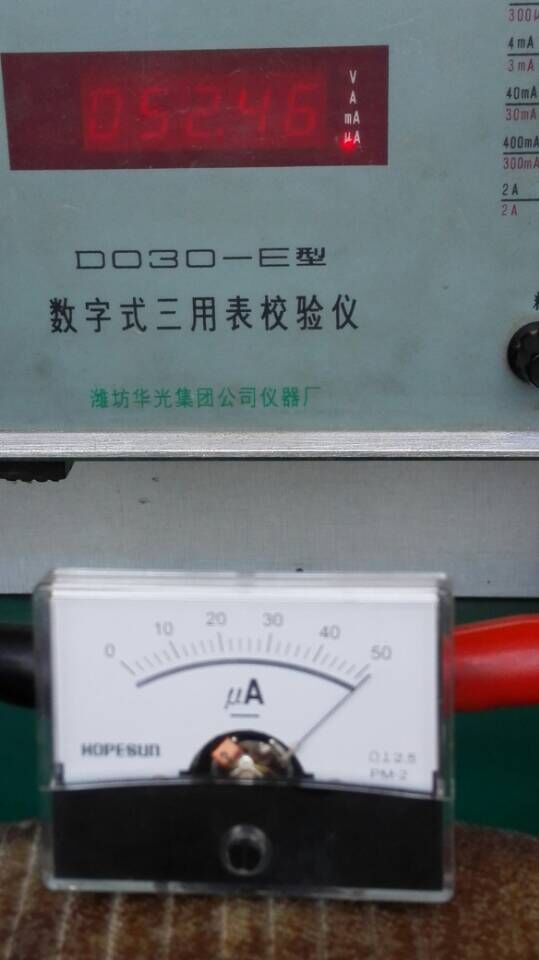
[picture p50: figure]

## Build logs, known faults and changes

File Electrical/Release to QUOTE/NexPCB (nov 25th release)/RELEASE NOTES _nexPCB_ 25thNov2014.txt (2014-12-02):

RELEASE NOTES
==================
8th Oct 2014 release

This has been my first crack getting PCB's spun. I went through a US manufacturer for prototypes, and I'm curious how you stack up. Most components are generic, 0805 size passives, with the exception of the items below.

The voltmeters themselves aren't on the BOM for the board, as they are attached mechanically at a different assembly level. The voltmeters for the clock are the PM-2, 50uA DC ammeter from China Hope Sun.

I had planned on adding some extra features onto the board to support an alarm clock, but left them unpopulated.

Finally, what are the implications of moving Lines 15 and 16, the encoder and potentiometer knobs, to the other side of the board? Beside the clock crystal and the unpopulated features, they are the only thru hole components. I'm fairly certain that Circuithub.com's manufacturer ended up hand soldering them, anyway.

Line 2, IC1
Design was based around an Atmel ATtiny44. The ATtiny88 and a bunch of low power versions are available as alternates. I'd be curious to talk about burning the chips in, too.

Line 12, U1
I had picked this specific voltage boost regulator from Microchip and think it's best to keep it.

Line 13, X1
I was surprised, but I think the thru hole package crystal ended up cheaper than SMT, when sourced on Octopart... would be happy to consider alternates, though.

Line 14, BT1 BT2 BT3 BT4
Battery Clip BK-53-TR
I looked high and low for battery clips for AA batteries. This is the doodad I found, but I'd be open to look for others.

Line 15, S1
I had picked this particular family of encoder knobs from Bourns because there was a matching potentiometer knob in their catalog. I liked that it was at a right angle, and the size was good. Unfortunately, I had trouble sourcing the POT, and ended up bending the pins 90 degrees to sortof fake the "right angle" knob that I wanted. The knob affects the fit to the case, so any alternates would need mechanical approval, but otherwise I'd love to find a pair of matching encoders/potentiometer knobs. I found a whole bunch of potential alternates:

PEC12R-2120F-N0012
PEC12R-2117F-N0024
PEC12R-2117F-N0012
PEC12R-2217F-N0012
PEC12R-2220F-N0024
PEC12R-2217F-N0024

Line 16, R2
See notes on Line 15 above.
PTV111-2420A-B203
PTV111-2415A-B103		
PTV111-2415A-A105

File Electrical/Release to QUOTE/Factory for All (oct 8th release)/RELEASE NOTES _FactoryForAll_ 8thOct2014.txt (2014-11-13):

RELEASE NOTES
==================
8th Oct 2014 release

This has been my first crack getting PCB's spun. I went through Circuithub.com before and I'm curious how you stack up for an order of QTY 100 boards. Most components are generic, 0805 size passives, with the exception of the items below.

The voltmeters themselves aren't on the BOM for the board, as they are attached mechanically at a different assembly leve. The voltmeters for the clock are the PM-2, 50uA DC ammeter from China Hope Sun. I had gotten pricing through an intermediary tht didn't speak english well. Specifically, I wanted to get the same meter, but with my design for the scale inserted, and wanted quotes of QTY 50, 100, 500, 1000, both with my custom scale and with their standard one. (http://www.chinahopesun.com/en/products/PDetail.aspx?ID=27600)

I had planned on adding some extra features onto the board to support an alarm clock, but left them unpopulated.

Finally, what are the implications of moving Linest 15 and 16, the encoder and potentiometer knobs, to the other side of the board? Beside the clock crystal and the unpopulated features, they are the only thru hole components. I'm fairly certain that Circuithub.com's manufacturer ended up hand soldering them, anyway.

Line 2, IC1
Design was based around an Atmel ATtiny44. The ATtiny88 and a bunch of low power versions are available as alternates. I'd be curious to talk about burning the chips in, too.

Line 12, U1
I had picked this specific voltage boost regulator from Microchip and think it's best to keep it.

Line 13, X1
I was surprised, but I think the thru hole package crystal ended up cheaper than SMT, when sourced on Octopart... would be happy to consider alternates, though.

Line 14, BT1 BT2 BT3 BT4
Battery Clip BK-53-TR
I looked high and low for battery clips for AA batteries. This is the doodad I found, but I'd be open to look for others.

Line 15, S1
I had picked this particular family of encoder knobs from Bourns because there was a matching potentiometer knob in their catalog. I liked that it was at a right angle, and the size was good. Unfortunately, I had trouble sourcing the POT, and ended up bending the pins 90 degrees to sortof fake the "right angle" knob that I wanted. The knob affects the fit to the case, so any alternates would need mechanical approval, but otherwise I'd love to find a pair of matching encoders/potentiometer knobs. I found a whole bunch of potential alternates:

PEC12R-2120F-N0012
PEC12R-2117F-N0024
PEC12R-2117F-N0012
PEC12R-2217F-N0012
PEC12R-2220F-N0024
PEC12R-2217F-N0024

Line 16, R2
See notes on Line 15 above.
PTV111-2420A-B203
PTV111-2415A-B103		
PTV111-2415A-A105

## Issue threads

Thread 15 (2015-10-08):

Add filter cap to reduce potentiometer noise

awkwardengineer, 2015-10-08:

Closed 2015-10-30.

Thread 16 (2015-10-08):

Rework circuit board with good transistor network switch

awkwardengineer, 2015-10-08:

Closed 2015-10-25.

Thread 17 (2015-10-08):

Make correction to schematic and circuit board to update transistor network

awkwardengineer, 2015-10-08:

Closed 2015-10-30.

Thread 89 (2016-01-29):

get insert slips printed

awkwardengineer, 2016-01-29:

Closed 2016-03-21.

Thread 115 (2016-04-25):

tighten USB cable hole

awkwardengineer, 2016-04-25:

Closed 2016-04-28.

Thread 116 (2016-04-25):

fix upside down switch mount, check dimensions

awkwardengineer, 2016-04-25:

Closed 2016-04-28.

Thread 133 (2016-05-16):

burn software onto boards

awkwardengineer, 2016-05-16:

Closed 2016-06-12.

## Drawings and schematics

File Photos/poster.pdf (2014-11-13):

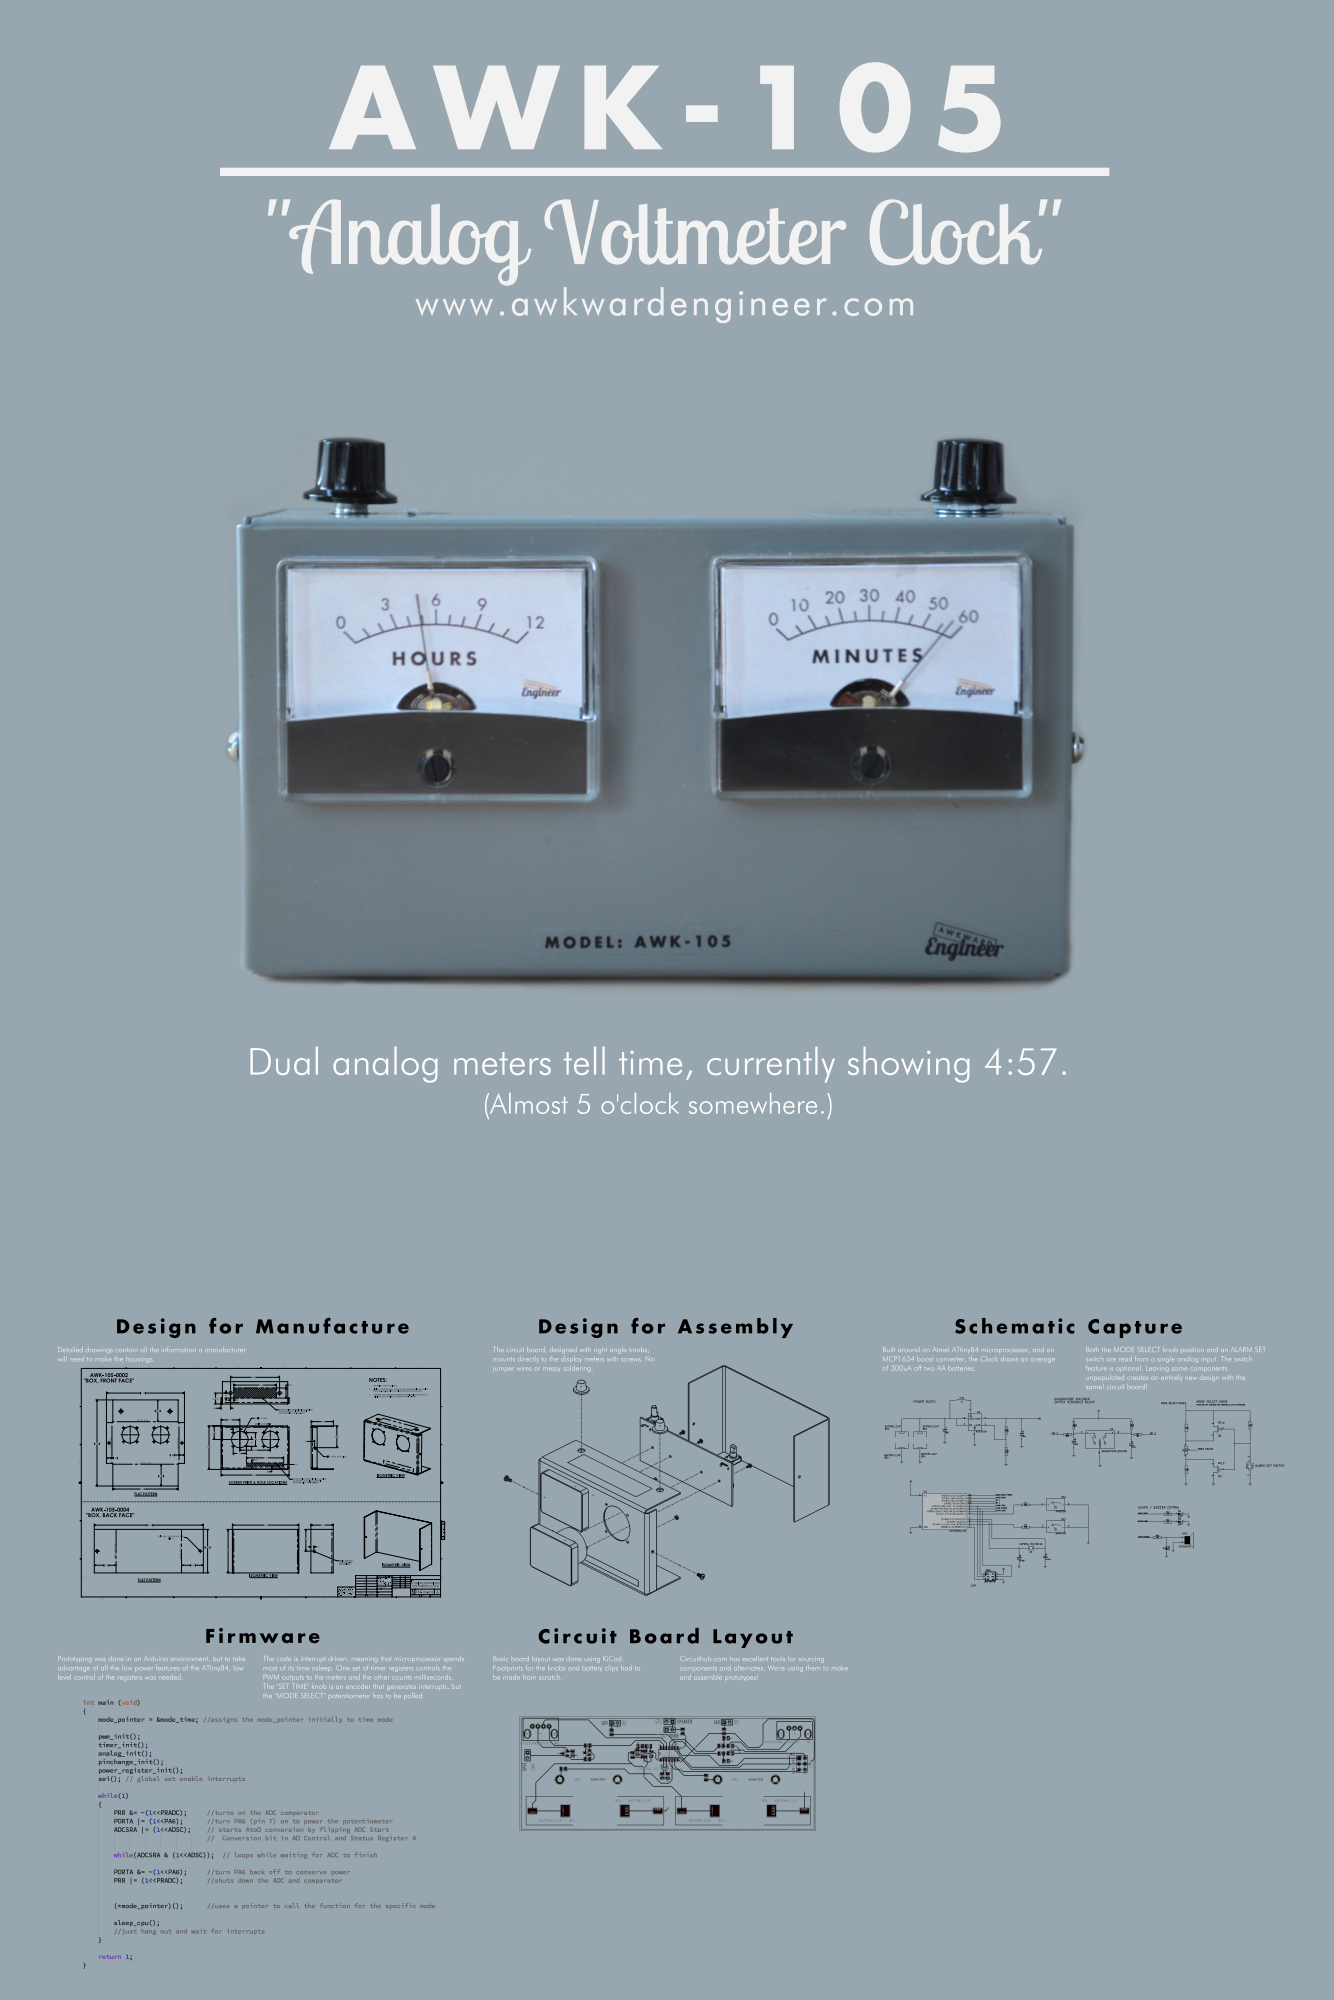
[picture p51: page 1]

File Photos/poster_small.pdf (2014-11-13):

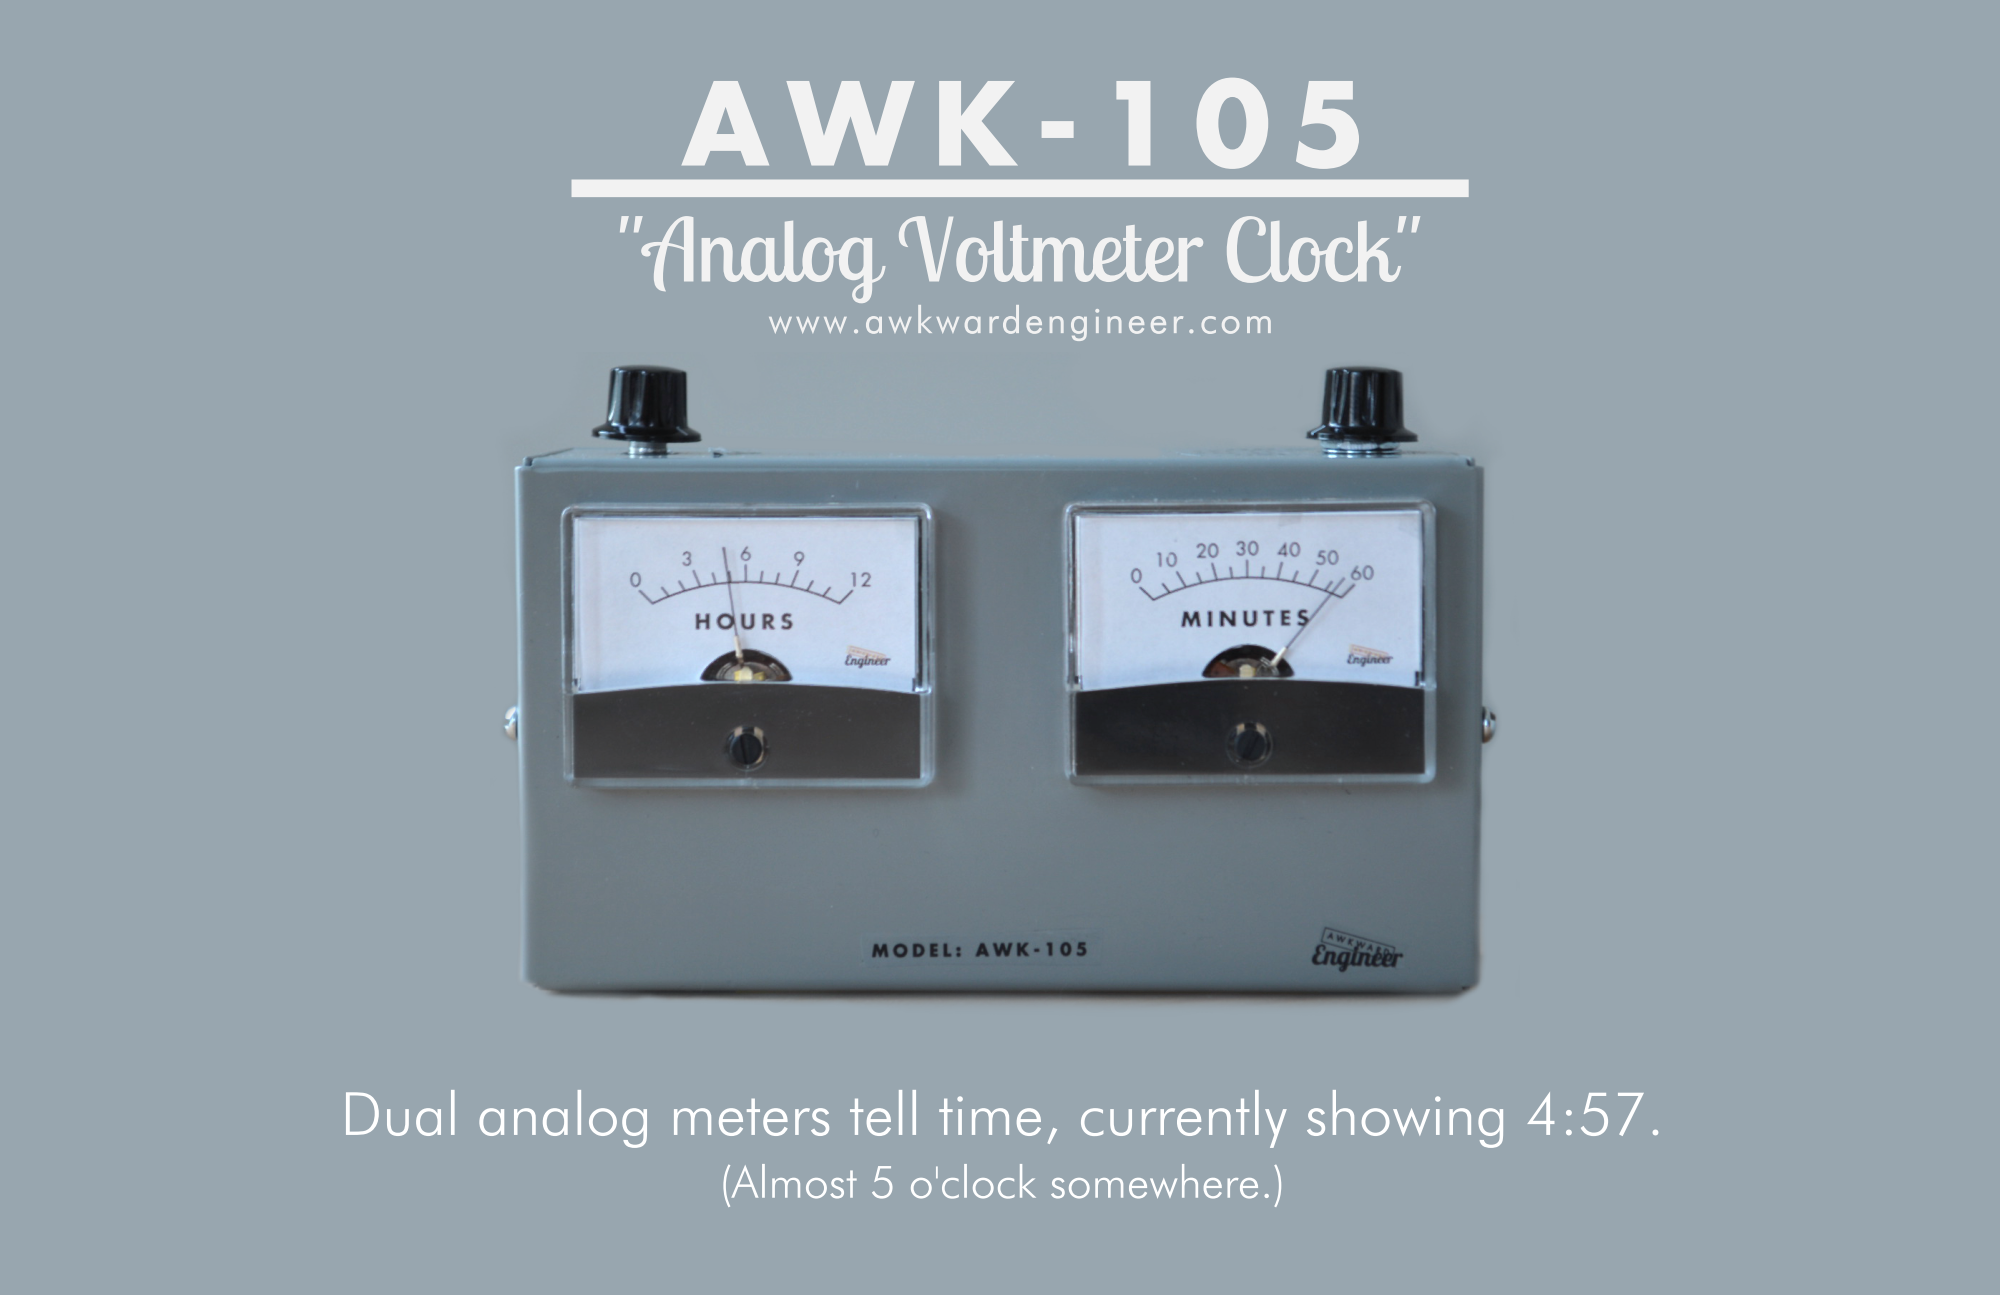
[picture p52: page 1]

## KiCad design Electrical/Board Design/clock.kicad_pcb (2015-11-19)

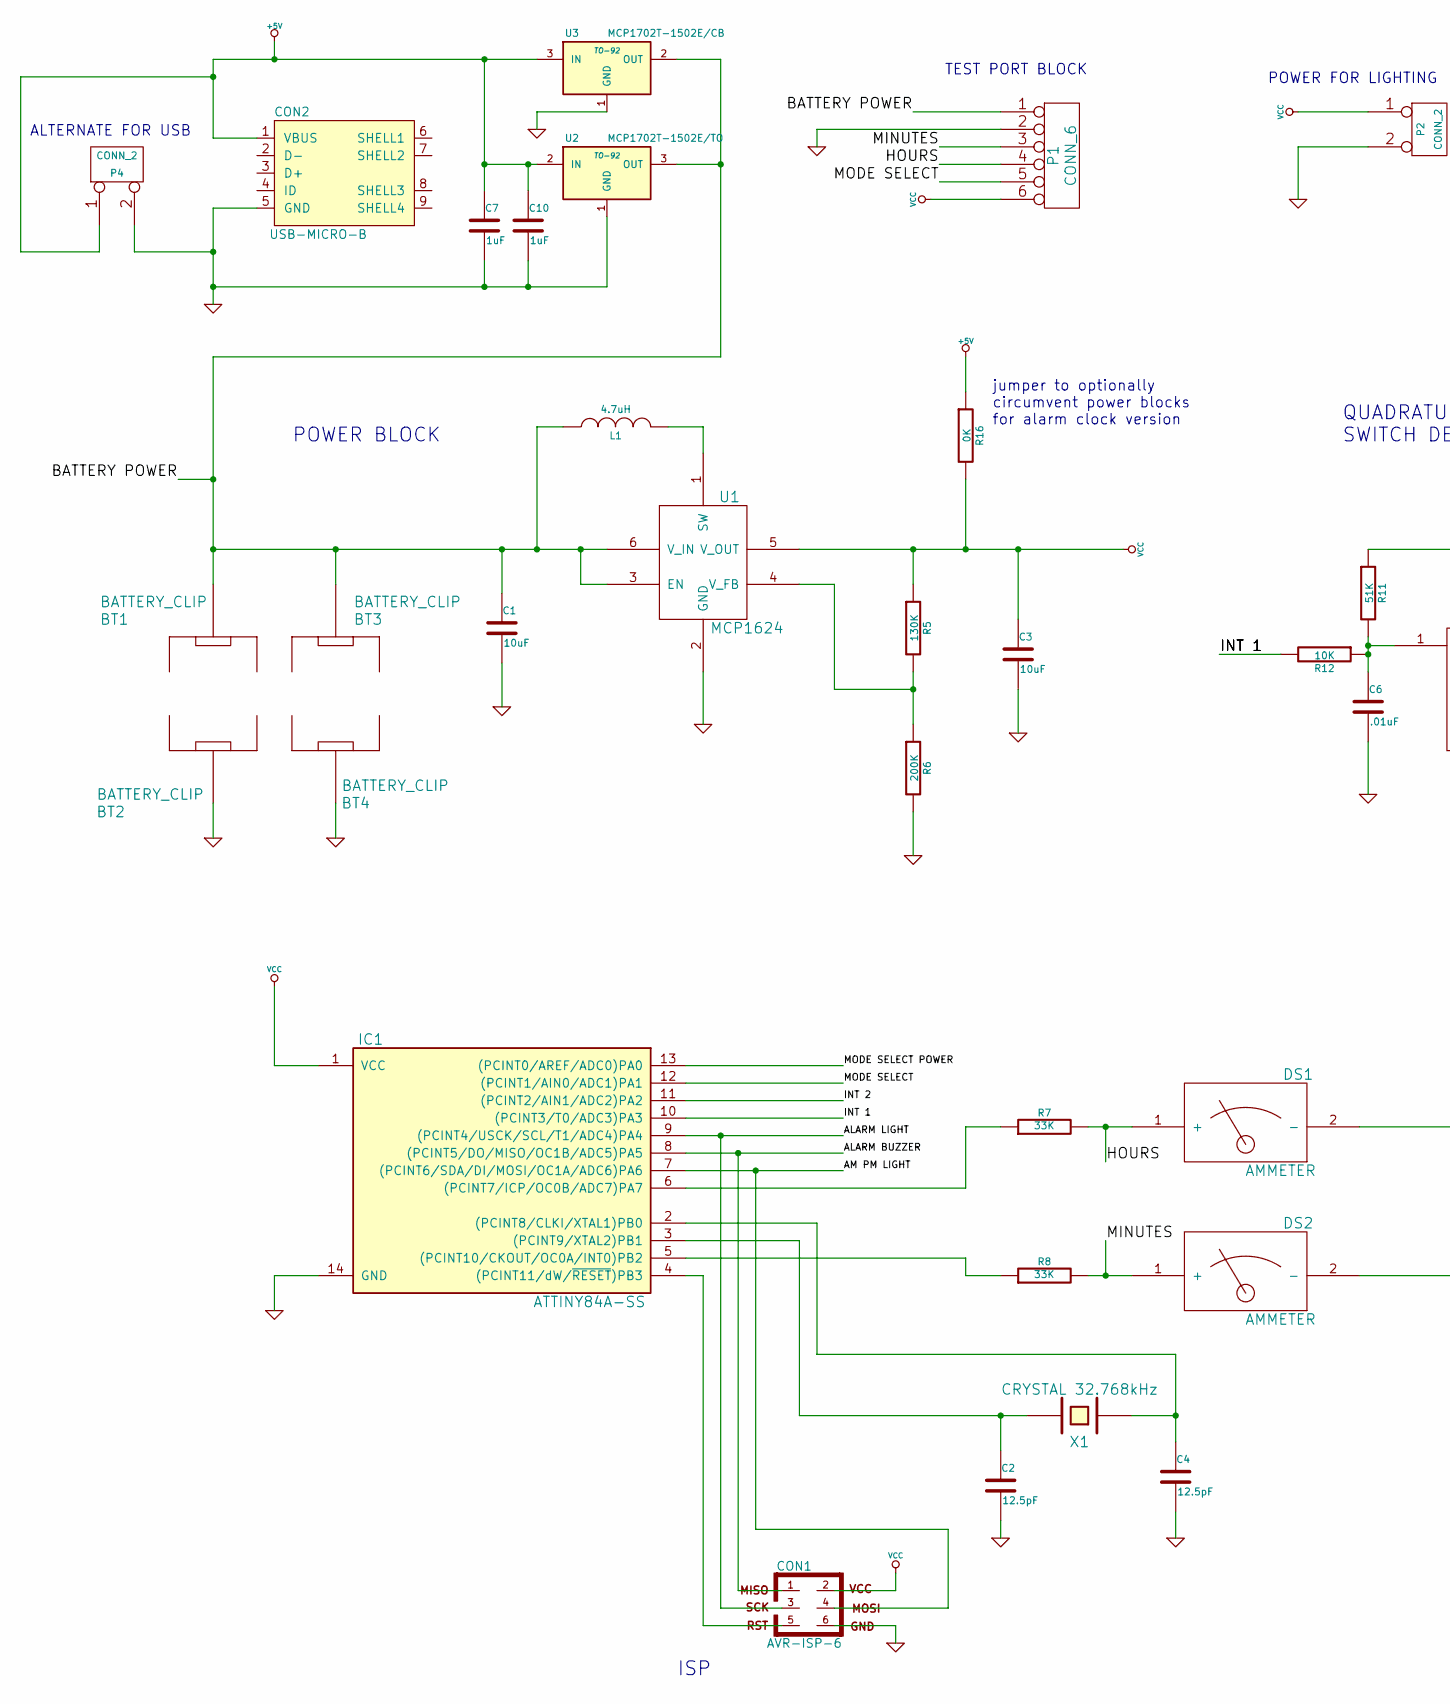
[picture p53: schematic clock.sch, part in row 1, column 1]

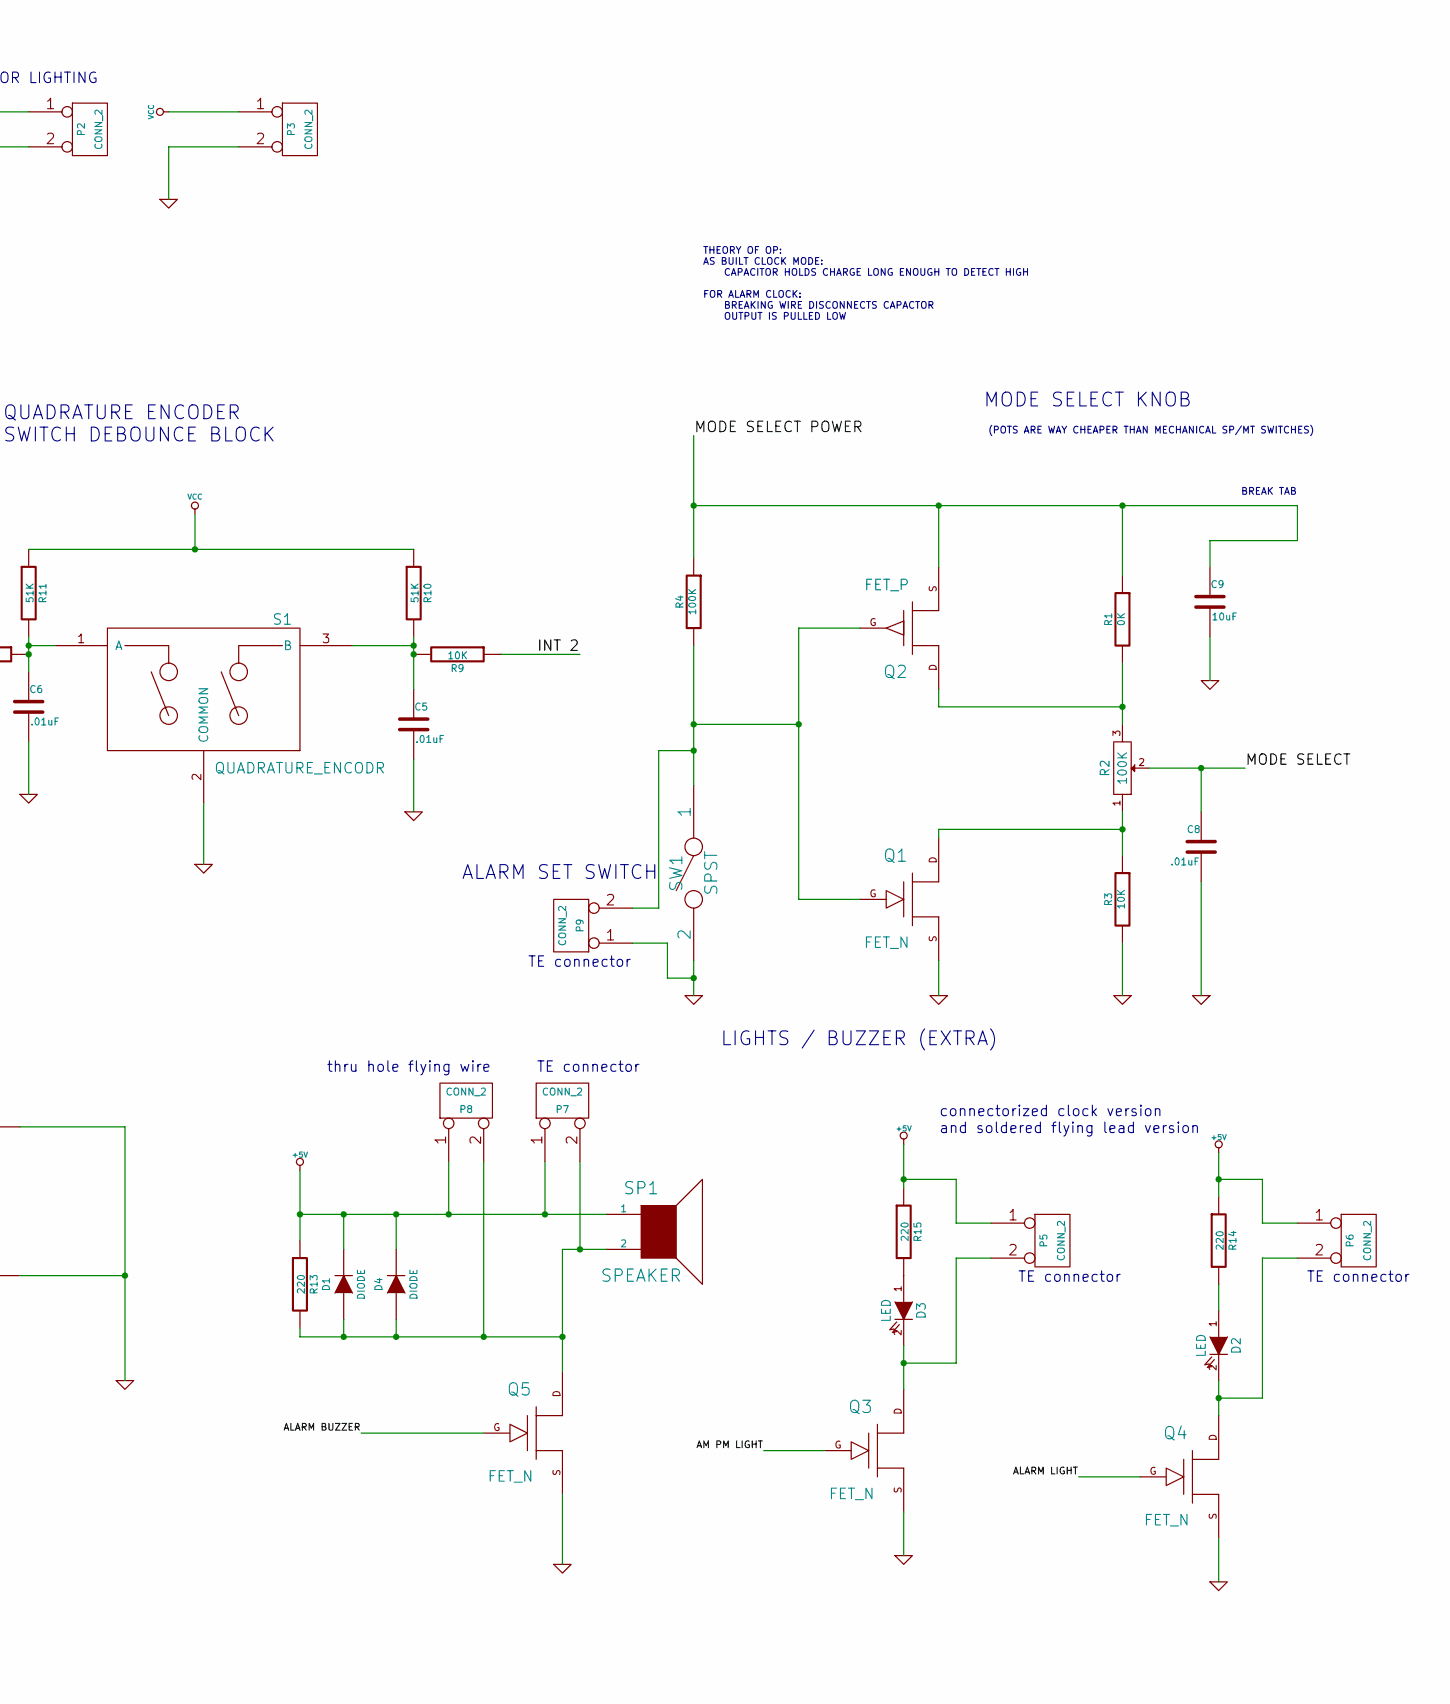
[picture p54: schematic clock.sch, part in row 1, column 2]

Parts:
BT1, BT2, BT3, BT4: BATTERY_CLIP
C1, C3, C9: 10uF
C2, C4: 12.5pF
C5, C6, C8: .01uF
C7, C10: 1uF
CON1: AVR-ISP-6
CON2: USB-MICRO-B
D1, D4: DIODE
D2, D3: LED
DS1, DS2: AMMETER
IC1: ATTINY84A-SS; SO14
L1: 4.7uH
P1: CONN_6
P2, P3, P4, P5, P6, P7, P8, P9: CONN_2
Q1, Q3, Q4, Q5: FET_N
Q2: FET_P
R1, R16: 0K
R2, R4: 100K
R3, R9, R12: 10K
R5: 130K
R6: 200K
R7, R8: 33K
R10, R11: 51K
R13, R14, R15: 220
S1: QUADRATURE_ENCODR
SP1: SPEAKER
SW1: SPST
U1: MCP1624
U2: MCP1702T-1502E/TO; TO-92
U3: MCP1702T-1502E/CB; TO-92
X1: CRYSTAL 32.768kHz

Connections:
+5V: C7.1, C10.1, CON2.1 (VBUS), D1.2 (K), D4.2 (K), P4.1, P5.1, P6.1, P7.1, P8.1, R13.1, R14.1, R15.1, R16.1, SP1.1, U2.2 (IN), U3.3 (IN)
/ALARM BUZZER: CON1.1, IC1.8 ((PCINT5/DO/MISO/OC1B/ADC5)PA5), Q5.G
/ALARM LIGHT: CON1.3, IC1.9 ((PCINT4/USCK/SCL/T1/ADC4)PA4), Q4.G
/AM PM LIGHT: CON1.4, IC1.7 ((PCINT6/SDA/DI/MOSI/OC1A/ADC6)PA6), Q3.G
/BATTERY POWER: BT1.~, BT3.~, C1.1, L1.1, P1.1, U1.3 (EN), U1.6 (V_IN), U2.3 (OUT), U3.2 (OUT)
/HOURS: DS1.1 (+), P1.4, R7.2
/INT 1: IC1.10 ((PCINT3/T0/ADC3)PA3), R12.2
/INT 2: IC1.11 ((PCINT2/AIN1/ADC2)PA2), R9.1
/MINUTES: DS2.1 (+), P1.3, R8.2
/MODE SELECT: C8.1, IC1.12 ((PCINT1/AIN0/ADC1)PA1), P1.5, R2.2
/MODE SELECT POWER: C9.1, IC1.13 ((PCINT0/AREF/ADC0)PA0), Q2.S, R1.1, R4.1
GND: BT2.~, BT4.~, C1.2, C2.2, C3.2, C4.2, C5.2, C6.2, C7.2, C8.2, C9.2, C10.2, CON1.6, CON2.5 (GND), DS1.2 (-), DS2.2 (-), IC1.14 (GND), P1.2, P2.2 (PM), P3.2 (PM), P4.2 (PM), P9.1, Q1.S, Q3.S, Q4.S, Q5.S, R3.2, R6.2, S1.2 (COMMON), SW1.2, U1.2 (GND), U2.1 (GND), U3.1 (GND)
unnamed: R5.2, R6.1, U1.4 (V_FB)
unnamed: C5.1, R9.2, R10.2, S1.3 (B)
unnamed: IC1.5 ((PCINT10/CKOUT/OC0A/INT0)PB2), R8.1
unnamed: L1.2, U1.1 (SW)
unnamed: D1.1 (A), D4.1 (A), P7.2 (PM), P8.2 (PM), Q5.D, R13.2, SP1.2
unnamed: P9.2 (PM), Q1.G, Q2.G, R4.2, SW1.1
unnamed: Q1.D, R2.1, R3.1
unnamed: Q2.D, R1.2, R2.3
unnamed: D2.1 (A), R14.2
unnamed: IC1.6 ((PCINT7/ICP/OC0B/ADC7)PA7), R7.1
unnamed: C6.1, R11.2, R12.1, S1.1 (A)
unnamed: CON1.5, IC1.4 ((PCINT11/dW/~RESET~)PB3)
unnamed: D3.2 (K), P5.2 (PM), Q3.D
unnamed: D3.1 (A), R15.2
unnamed: D2.2 (K), P6.2 (PM), Q4.D
unnamed: C4.1, IC1.2 ((PCINT8/CLKI/XTAL1)PB0), X1.1
unnamed: C2.1, IC1.3 ((PCINT9/XTAL2)PB1), X1.2
VCC: C3.1, CON1.2, IC1.1 (VCC), P1.6, P2.1, P3.1, R5.1, R10.1, R11.1, R16.2, U1.5 (V_OUT)

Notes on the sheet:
QUADRATURE ENCODER SWITCH DEBOUNCE BLOCK
LIGHTS / BUZZER (EXTRA)
ISP
POWER BLOCK
TEST PORT BLOCK
POWER FOR LIGHTING
ALTERNATE FOR USB
jumper to optionally circumvent power blocks for alarm clock version
connectorized clock version and soldered flying lead version
ALARM SET SWITCH
(POTS ARE WAY CHEAPER THAN MECHANICAL SP/MT SWITCHES)
MODE SELECT KNOB
BREAK TAB
THEORY OF OP: AS BUILT CLOCK MODE: CAPACITOR HOLDS CHARGE LONG ENOUGH TO DETECT HIGH FOR ALARM CLOCK: BREAKING WIRE DISCONNECTS CAPACTOR OUTPUT IS PULLED LOW
thru hole flying wire
TE connector

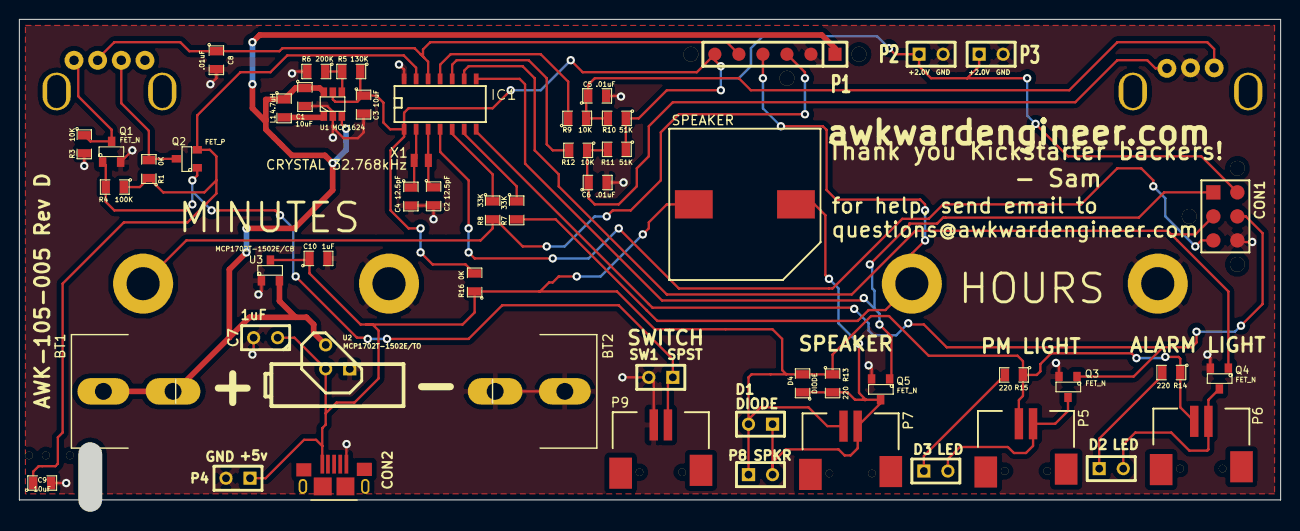
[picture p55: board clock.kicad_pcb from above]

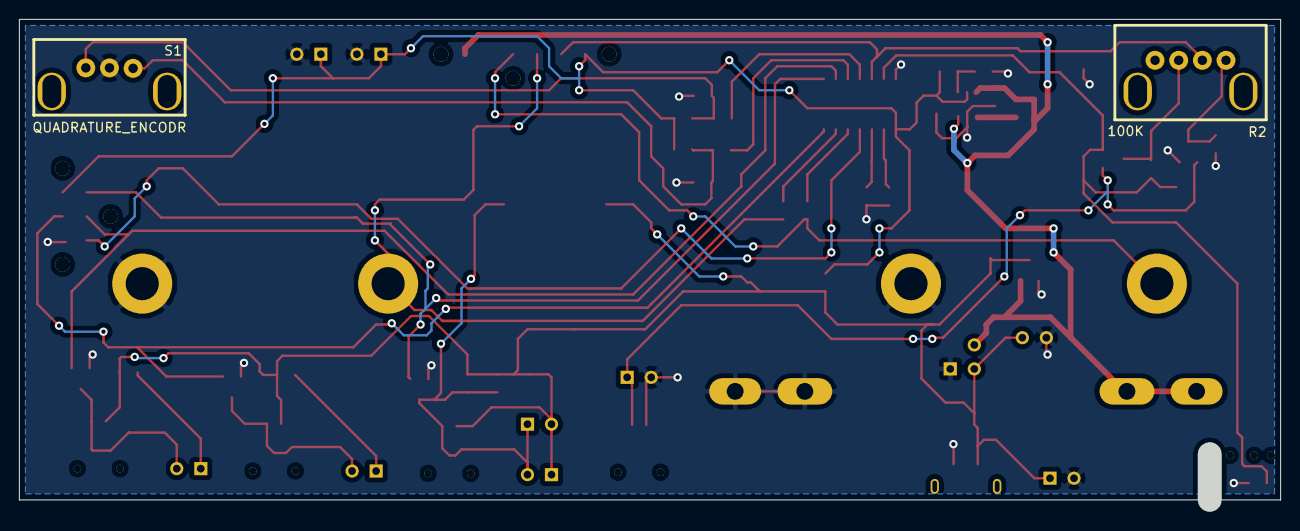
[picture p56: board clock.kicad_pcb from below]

Board: 2 copper layers, 133.3 x 50.8 mm, 62 parts (2 on the bottom side), 30 nets.

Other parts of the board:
BREAK_TAB: Val**; BREAK_HOLE
BREAK_TAB#2, BREAK_TAB#3: Val**; BREAK_HOLE

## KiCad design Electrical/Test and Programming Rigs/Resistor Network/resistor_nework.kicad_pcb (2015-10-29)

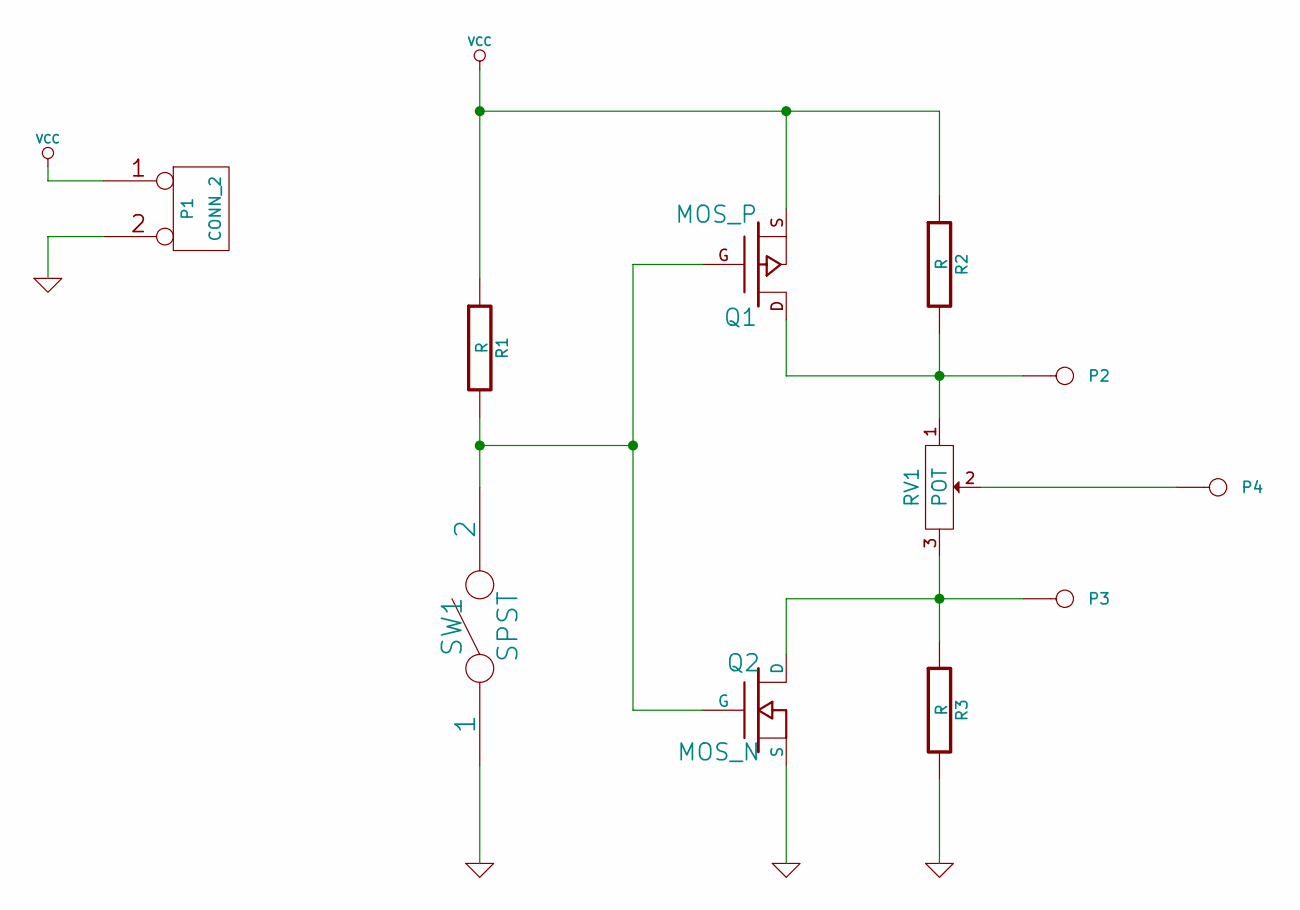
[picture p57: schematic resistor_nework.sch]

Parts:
P1: CONN_2
P2, P3, P4: CONN_1
Q1: MOS_P
Q2: MOS_N
R1, R2, R3: R
RV1: POT
SW1: SPST

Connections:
GND: P1.2 (PM), Q2.S, R3.2, SW1.1
unnamed: Q1.G, Q2.G, R1.2, SW1.2
unnamed: P4.1, RV1.2
unnamed: P3.1, Q2.D, R3.1, RV1.3
unnamed: P2.1, Q1.D, R2.2, RV1.1
VCC: P1.1, Q1.S, R1.1, R2.1

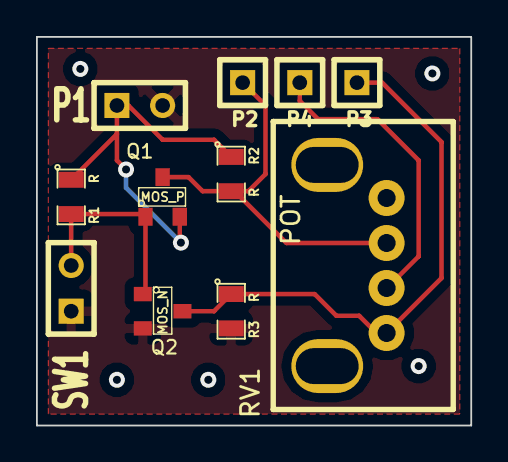
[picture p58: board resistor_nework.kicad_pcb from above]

Board: 2 copper layers, 24.1 x 21.6 mm, 11 parts (0 on the bottom side), 6 nets.

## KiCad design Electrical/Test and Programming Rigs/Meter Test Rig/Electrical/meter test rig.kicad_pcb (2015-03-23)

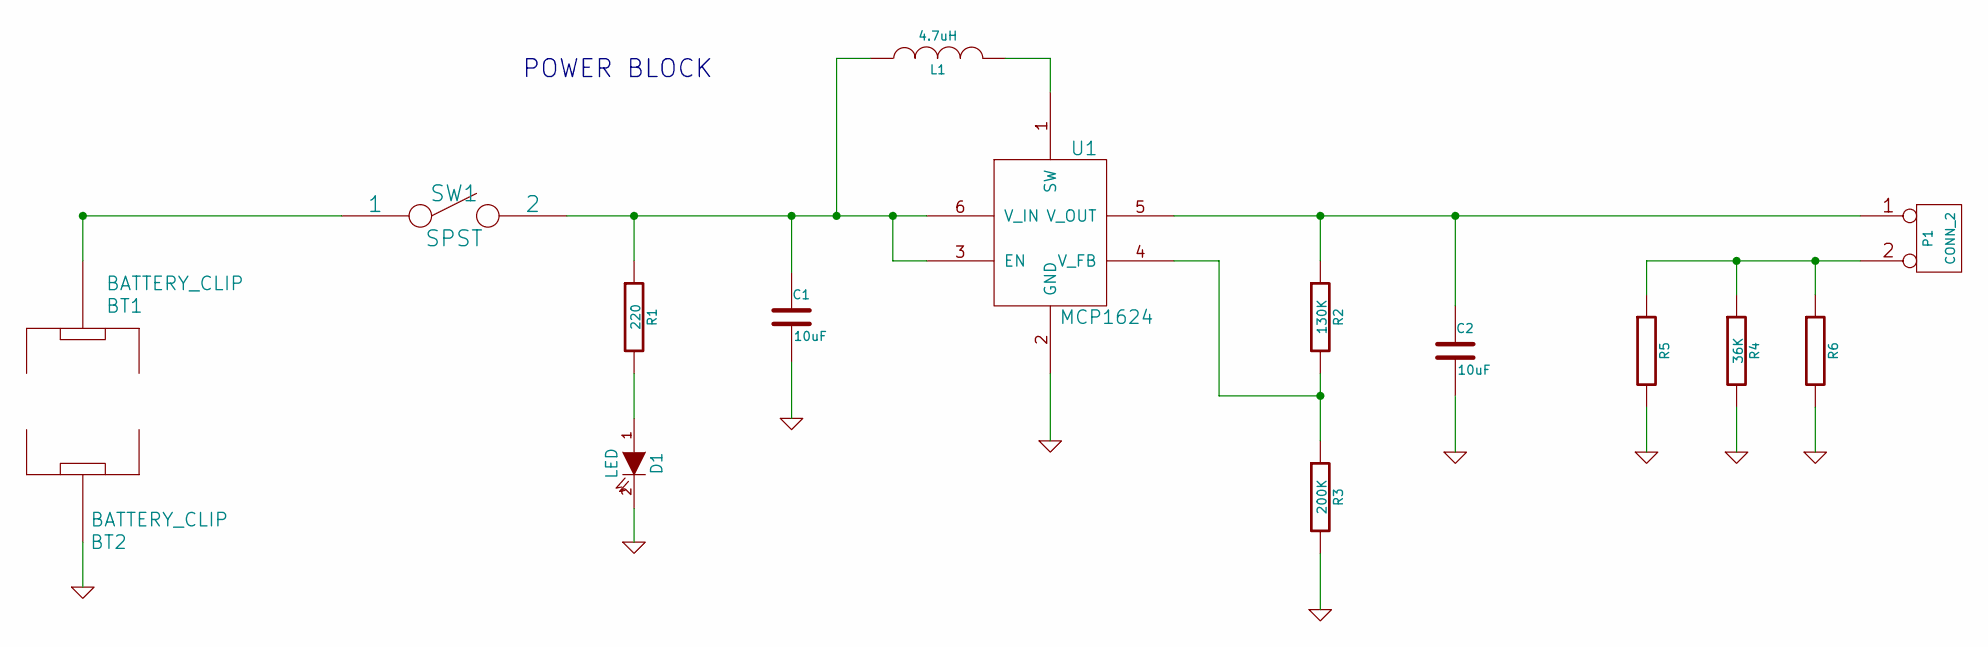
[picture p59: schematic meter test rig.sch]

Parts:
BT1, BT2: BATTERY_CLIP
C1, C2: 10uF
D1: LED
L1: 4.7uH
P1: CONN_2
R1: 220
R2: 130K
R3: 200K
R4: 36K
R5, R6: (no value)
SW1: SPST
U1: MCP1624

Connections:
GND: BT2.~, C1.2, C2.2, D1.2 (K), R3.2, R4.2, R5.2, R6.2, U1.2 (GND)
unnamed: D1.1 (A), R1.2
unnamed: L1.2, U1.1 (SW)
unnamed: P1.2 (PM), R4.1, R5.1, R6.1
unnamed: BT1.~, SW1.1
unnamed: C1.1, L1.1, R1.1, SW1.2, U1.3 (EN), U1.6 (V_IN)
unnamed: C2.1, P1.1, R2.1, U1.5 (V_OUT)
unnamed: R2.2, R3.1, U1.4 (V_FB)

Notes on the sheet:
POWER BLOCK

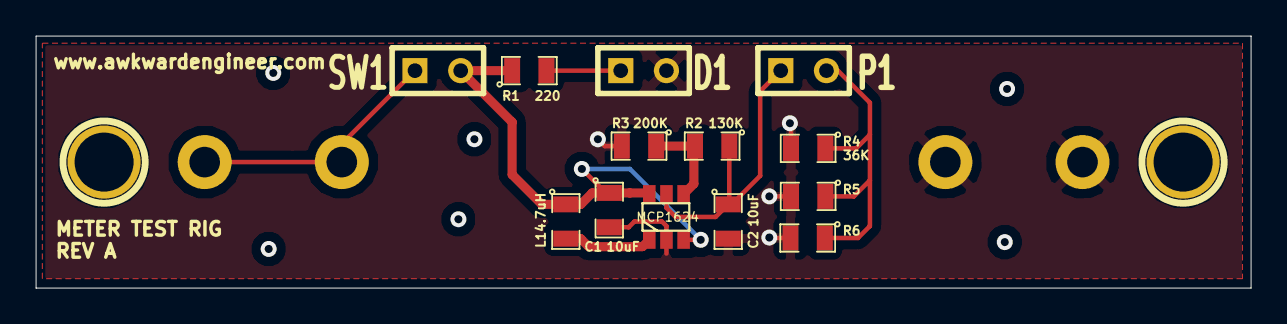
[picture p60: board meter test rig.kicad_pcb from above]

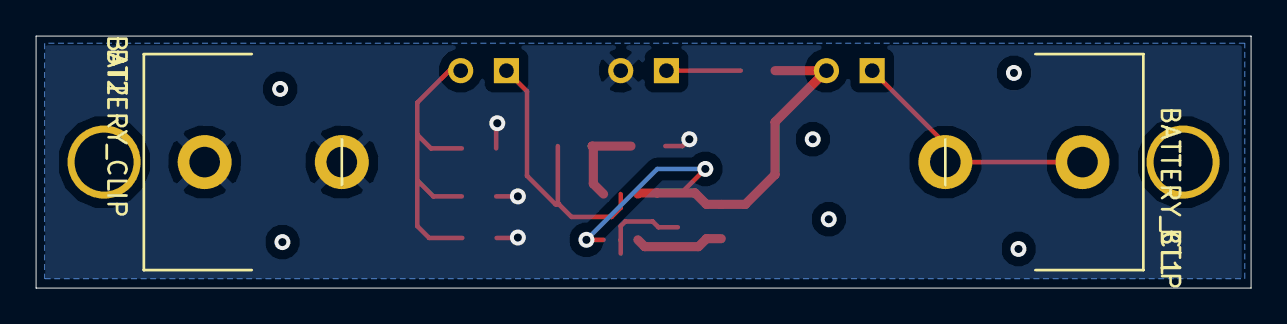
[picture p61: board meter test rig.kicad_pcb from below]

Board: 2 copper layers, 67.5 x 14.0 mm, 17 parts (2 on the bottom side), 8 nets.

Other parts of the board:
1PIN, 1PIN#2: P***; 1pin

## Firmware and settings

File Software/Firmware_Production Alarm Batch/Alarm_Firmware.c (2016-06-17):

/*
 * Alarm_Firmware.c
 *
 * Created: 3/26/2016 10:20:09 AM
 * Author : awkwardengineer
 */ 


#include <avr/io.h>
#include <avr/sleep.h>
#include <stdbool.h>
#include "..\shared\alarm_config.c"
#include "..\shared\alarm_helpers.c"


volatile int ISR_accumulator = 0;
volatile uint16_t ISR_ticks = 0;
volatile bool ISR_ticked = false;

enum Mode {MODE_TEST, MODE_CAL_HOURS, MODE_CAL_MINUTES, MODE_WARBLE, MODE_TIME, MODE_ALARM};

struct State{
	unsigned long numTicks;
	unsigned long alarmTimeInTicks;
	
	uint8_t potReading;
	
	uint8_t cal_hours;
	uint8_t cal_minutes;
	
	uint8_t warbleLevel;
	
	int rotation_accumulator;
	
	enum Mode mode;
	
	bool isAlarmSet;
	bool isAlarmSounding;
	bool isUIActive;
	bool isAlarmSwitchOn;
	
	bool isJustEnteredMode;
	bool isJustBooted;
	
};

void pollInputs(struct State *state){
	
	state->potReading = pollPot();
}

void pollInputsWithPulldown(struct State *state){
	
	state->potReading = pollPot();
	state->isAlarmSwitchOn = isSwitchUp();
}

void pollInputsWithCapSense(struct State *state){
	struct PotAndCap potAndCap;
	
	potAndCap = pollPotWithCapSense();
	state->potReading = potAndCap.pot;
	
	if (potAndCap.cap < CAP_SENSE_THRESHOLD)
	{
		state->isAlarmSwitchOn = true ; //
	}
	else{
		state->isAlarmSwitchOn = false;
	}
}

void processAlarmPolledInputs(struct State *state){
		static int oldPotReading;
		static bool isAlarmLatched = false;
		static enum Mode lastMode = MODE_TIME;
		
		/*
		
		//	this block not needed for Alarm, as it runs at a 4hz loop and is sensitive enough	
		
		//If the pot moved, the UI should be active		
		if ((int)state->potReading - oldPotReading > 5 ||
			(int)state->potReading - oldPotReading < -5){
			state->isUIActive = true;
			//state->isJustBooted = false;
		}
		*/
		
		oldPotReading = state->potReading;
		
		//if the switch is on, and the latch is not set, this is a new trigger
		if (state->isAlarmSwitchOn &&
			!isAlarmLatched){
				
				isAlarmLatched = true; //set a latch so it has to be turned off
				
				if (state->isAlarmSounding){
					state->isAlarmSounding = false ; //if alarm is sounding, turn it off
					state->isAlarmSet = false;
				}
				else{
					state->isAlarmSet = !state->isAlarmSet; //otherwise, toggle the alarm set status
						
						chirp();

				}		
		}
		
		if (!state->isAlarmSwitchOn){isAlarmLatched = false;} 
		
		
		/* for reference
		#define POS_test 10
		#define POS_minutes 45
		#define POS_hours 97
		#define POS_warble 170
		#define POS_time 225
		#define POS_alarm 255*/

	
		if (state->potReading < POS_test){ state->mode = MODE_TEST;}
		else if (state->potReading < POS_minutes){state->mode = MODE_CAL_MINUTES;}
		else if (state->potReading < POS_hours){state->mode = MODE_CAL_HOURS;}
		else if (state->potReading < POS_warble){state->mode = MODE_WARBLE;}
		else if (state->potReading < POS_time){state->mode = MODE_TIME;}
		else {state->mode = MODE_ALARM;}
	
		if (state->mode != lastMode){
			state->isJustEnteredMode = true;
			chirp();
		}
		
		lastMode = state->mode;
	/*	
	if the knob moved, set isUIActive
	
	if isUIActive  (should also be settable by encoder interrupt)
		uiActiveCounter resets
	else
		uiActiveCounter-- until 0
	
	if uiActiveCounter is not zero
		set a short timer interrupt
	else
		set a long timer interrupt
	*/
}

int controlSweep(struct State *state){
		static long oldnumticks = 0;
		static int super_accumulator = 0;
		static int super_accumulator2 = 0;
		static int super_accumulator3 = 0;
		static int super_accumulator4 = 0;
		static int sweep = 0;
		
		super_accumulator += state->rotation_accumulator;
		
		if (state->isAlarmSounding){
			sweep = 0;
			return sweep;
		}
		
		//if in sweep mode and input comes in the other direction, stop sweeping
		if ((sweep > 0) && 	(state->rotation_accumulator < 0)){
			sweep = 0;
			super_accumulator = 0;
			super_accumulator2 = 0;
			super_accumulator3 = 0;
			super_accumulator4 = 0;
			chirp();
		}
		else if ((sweep < 0) && (state->rotation_accumulator > 0)){
			sweep = 0;
			super_accumulator = 0;
			super_accumulator2 = 0;
			super_accumulator3 = 0;
			super_accumulator4 = 0;
			chirp();
		}
		
		int total;
		total = super_accumulator + super_accumulator2 + super_accumulator3 + super_accumulator4;
		//if enough turns are accumulated in 1 second, start sweeping
		if (sweep == 0){
			if (total > 14){sweep = 600; chirp();}
			else if (total < -14){sweep = -600; chirp();}
		}
		
		//if you switched modes while sweeping, stop sweeping
		if (state->isJustEnteredMode){
			sweep = 0;
			super_accumulator = 0;
			super_accumulator2 = 0;
			super_accumulator3 = 0;
			super_accumulator4 = 0;
		}
		
		//if the clock has ticked 2 seconds, flush the superaccumulator
		if (ISR_ticks > oldnumticks ){
			super_accumulator4 = super_accumulator3;
			super_accumulator3 = super_accumulator2;
			super_accumulator2 = super_accumulator;
			super_accumulator = 0;
			oldnumticks = ISR_ticks;
		}
		
		return sweep;
}


void processAlarmEncoderInputs(struct State *state){
	//MODE_TEST, MODE_CAL_HOURS, MODE_CAL_MINUTES,MODE_WARBLE, MODE_TIME, MODE_ALARM
	int holder;
	int sweep;
	
		
	switch(state->mode){
		case MODE_TEST:
			
			break;
			
		case MODE_TIME:
			sweep = controlSweep(state);
		
			state->numTicks += 60 * state->rotation_accumulator + sweep;
			
			if (state->rotation_accumulator != 0){
				state->isJustBooted = false;
			}
			break;
			
		case MODE_ALARM:
			sweep = controlSweep(state);
		
			state->alarmTimeInTicks += 60*state->rotation_accumulator + sweep;				
			break;
				
		case MODE_WARBLE:
			
			holder = (int)state->warbleLevel;
			holder -= state->rotation_accumulator;
			
			if (holder > 5){holder = 5;}
			if (holder < 1){holder = 1;}
			
			state->warbleLevel = holder;
			
			break;
				
		case MODE_CAL_HOURS:
			holder = (int)state->cal_hours + (int)state->rotation_accumulator;
			
			if (holder > 255){holder = 255;}
			if (holder < 0){holder = 0;}
			state->cal_hours = (uint8_t)holder;
			
			
			break;
			
		case MODE_CAL_MINUTES:
			holder = (int)state->cal_minutes + (int)state->rotation_accumulator;
						
			if (holder > 255){holder = 255;}
			if (holder < 0){holder = 0;}
			state->cal_minutes = (uint8_t)holder;
			
			break;
	}
	
	state->rotation_accumulator = 0;
}


void updateMeters(struct State *state){
	static int newModeCounter = 0;
	
	if (state->isJustEnteredMode){
		newModeCounter = 10;
	}
	
	if (newModeCounter > 0){
		newModeCounter--;
	}
	
	switch(state->mode){
		case MODE_TEST:
			OCR0A += 10;
			OCR0B += 10;
			break;
		
		case MODE_TIME:
			if (newModeCounter > 4){
				setMinutesMeter(state->cal_minutes);
				setHoursMeter(state->cal_hours);
			}
			else if (newModeCounter > 3){
				setMinutesMeter(0);
				setHoursMeter(0);
			}
			else{
				setMinutesMeter(calcMinsFromTics(state->numTicks, state->cal_minutes));
				setHoursMeter(calcHoursFromTics(state->numTicks, state->cal_hours));
			}
			break;
		
		case MODE_ALARM:
			setMinutesMeter(calcMinsFromTics(state->alarmTimeInTicks, state->cal_minutes));
			setHoursMeter(calcHoursFromTics(state->alarmTimeInTicks, state->cal_hours));
			
			if (newModeCounter == 9 ){ setAlarmLightOff();}
			else if (newModeCounter == 8 ){ setAlarmLightOn();}
			else if (newModeCounter == 7 ){ setAlarmLightOff();}
			else if (newModeCounter == 6 ){ setAlarmLightOn();}
			else if (newModeCounter == 5 ){ setAlarmLightOff();}
			else if (newModeCounter == 4 ){ setAlarmLightOn();}
			else if (newModeCounter == 3 ){ setAlarmLightOff();}
			else if (newModeCounter == 0){newModeCounter = 10;}
			else{}
			break;
			
		case MODE_WARBLE:
			if (newModeCounter > 6){
				setMinutesMeter(state->cal_minutes);
				setHoursMeter(0);	
			}
			else if (newModeCounter > 3){
				setHoursMeter(state->cal_hours);
				setMinutesMeter(0);
			}
			else if (newModeCounter > 0){
				setMinutesMeter(state->cal_minutes);
				setHoursMeter(0);
			}
			else{
				//this is where the warbling happens
				
				static uint8_t warble_tics = 0;
				static bool isOdd = true;
				static bool minFlag = false;
				static bool hoursFlag = false;
				int direction = 128;
				
				int numTriggers = 0;
				
				warble_tics++;
				
				setMinutesMeter(calcMinsFromTics(state->numTicks, state->cal_minutes));
				setHoursMeter(calcHoursFromTics(state->numTicks, state->cal_hours));
				
				if (warble_tics % 3 == 0){
					direction = -32;	
				}
				else{
					direction = 128;
				}
				
				if (hoursFlag){
					HOURS_PWM += direction;
					hoursFlag = false;
				}
				if (minFlag){
					MINS_PWM += direction;
					minFlag = false;
				}
				
				
				//started out as 3,5,8 as the pseudorandom generators,
				//multiplied by 2 to get 6,10,16
				//multiplied again by 3/2 to get 9,15,24
				//trying by 2 for 12,20,32
				if (warble_tics % (3 * state->warbleLevel) == 0){
					numTriggers++;
					isOdd = !isOdd;
				}
				if (warble_tics % (5 * state->warbleLevel) == 0){
					numTriggers++;
				}
				if (warble_tics % (8 * state->warbleLevel) == 0){
					numTriggers++;
					isOdd = !isOdd;
				}
				
				if (numTriggers == 3){
					//least likely, sets up full wiggle
					newModeCounter = 10;
				}
				if (numTriggers == 2){
					//wiggles both
					hoursFlag = true;
					minFlag = true;
				}
				if (numTriggers == 1){
					//wiggles one
					if (isOdd)     { hoursFlag = true;}
					else           { minFlag = true;}
				}
				
				
			}
			break;
		
		case MODE_CAL_HOURS:
			setMinutesMeter(0);
			setHoursMeter(state->cal_hours);
			break;
		
		case MODE_CAL_MINUTES:
			setMinutesMeter(state->cal_minutes);
			setHoursMeter(0);
			break;
		

		

	}
}

void updateClockMeters(struct State *state){
	static int newModeCounter = 3;
	
	if (state->isJustEnteredMode){
		turnOffTimerB(); //timerB makes the loop run faster. it's useful for warble mode, but should be off everywhere else
		newModeCounter = 4;
	}
	
	if (newModeCounter > 0){
		newModeCounter--;
	}
	
	switch(state->mode){
		case MODE_TEST:
			OCR0A += 10;
			OCR0B += 10;
		break;
		
		case MODE_TIME:
		if (newModeCounter > 2){
			setMinutesMeter(state->cal_minutes);
			setHoursMeter(state->cal_hours);
		}
		else if (newModeCounter > 1){
			setMinutesMeter(0);
			setHoursMeter(0);
		}
		else{
			setMinutesMeter(calcMinsFromTics(state->numTicks, state->cal_minutes));
			setHoursMeter(calcHoursFromTics(state->numTicks, state->cal_hours));
		}
		break;
		
		//there should be no MODE_ALARM in clock mode, but I'm trying not to
		//touch too many things
		case MODE_ALARM:
		setMinutesMeter(calcMinsFromTics(state->alarmTimeInTicks, state->cal_minutes));
		setHoursMeter(calcHoursFromTics(state->alarmTimeInTicks, state->cal_hours));
		
		if (newModeCounter == 9 ){ setAlarmLightOff();}
		else if (newModeCounter == 8 ){ setAlarmLightOn();}
		else if (newModeCounter == 7 ){ setAlarmLightOff();}
		else if (newModeCounter == 6 ){ setAlarmLightOn();}
		else if (newModeCounter == 5 ){ setAlarmLightOff();}
		else if (newModeCounter == 4 ){ setAlarmLightOn();}
		else if (newModeCounter == 3 ){ setAlarmLightOff();}
		else if (newModeCounter == 0){newModeCounter = 10;}
		else{}
		break;
		
		case MODE_WARBLE:
		if (newModeCounter > 2){
			setHoursMeter(state->cal_hours);
			setMinutesMeter(0);
		}
		else if (newModeCounter > 1){
			setHoursMeter(0);
			setMinutesMeter(state->cal_minutes);
		}
		else if (newModeCounter > 0){
			setHoursMeter(state->cal_hours);
			setMinutesMeter(0);
			turnOnTimerB();			//makes the warbles faster
		}
		else{
			//this is where the warbling happens
			
			static uint8_t warble_tics = 0;
			static bool isOdd = true;
			static bool minFlag = false;
			static bool hoursFlag = false;
			int direction = 128;
			
			int numTriggers = 0;
			
			warble_tics++;
			
			setMinutesMeter(calcMinsFromTics(state->numTicks, state->cal_minutes));
			setHoursMeter(calcHoursFromTics(state->numTicks, state->cal_hours));
			
			if (warble_tics % 3 == 0){
				direction = -32;
			}
			else{
				direction = 128;
			}
			
			if (hoursFlag){
				HOURS_PWM += direction;
				hoursFlag = false;
			}
			if (minFlag){
				MINS_PWM += direction;
				minFlag = false;
			}
			
			
			//started out as 3,5,8 as the pseudorandom generators,
			//multiplied by 2 to get 6,10,16
			//multiplied again by 3/2 to get 9,15,24
			//trying by 2 for 12,20,32
			if (warble_tics % (3 * state->warbleLevel) == 0){
				numTriggers++;
				isOdd = !isOdd;
			}
			if (warble_tics % (5 * state->warbleLevel) == 0){
				numTriggers++;
			}
			if (warble_tics % (8 * state->warbleLevel) == 0){
				numTriggers++;
				isOdd = !isOdd;
			}
			
			if (numTriggers == 3){
				//least likely, sets up full wiggle
				newModeCounter = 3;
			}
			if (numTriggers == 2){
				//wiggles both
				hoursFlag = true;
				minFlag = true;
			}
			if (numTriggers == 1){
				//wiggles one
				if (isOdd)     { hoursFlag = true;}
				else           { minFlag = true;}
			}
			
			
		}
		break;
		
		case MODE_CAL_HOURS:
		setMinutesMeter(0);
		setHoursMeter(state->cal_hours);
		break;
		
		case MODE_CAL_MINUTES:
		setMinutesMeter(state->cal_minutes);
		setHoursMeter(0);
		break;
		

		

	}
}


void updateLEDs(struct State *state){
	//in alarm mode, the AM PM light reflects whether the alarm is set for AM or PM
	static bool flashOnBoot=true;
	
	if(state->isJustBooted){
		if(flashOnBoot){setPMLightOn();
						flashOnBoot=false;}
		else           {setPMLightOff();
						flashOnBoot=true;}
	}
	else{
		if (state->mode == MODE_ALARM){
			if (state->alarmTimeInTicks >= AMPM_LINE){
				setPMLightOn();
			}
			else{
				setPMLightOff();
			}
		}
		else{
			if (state->numTicks >= AMPM_LINE){   //in all other modes, the AM PM light reflects AM and PM
				setPMLightOn();
			}
			else{
				setPMLightOff();
			}
		}
	}
	
	if (state->isAlarmSounding){
		return;//relinquish control and do nothing if alarm is sounding
	}
	else{
		if (state->isAlarmSet){
			setAlarmLightOn();
		}
		else{
			setAlarmLightOff();
		}
		
	}
}

void updateSpeaker(struct State *state){
	static unsigned long lastBeepTime;
	static bool isBeeping = false;
	
	if(state->isAlarmSounding){
	
	//	if ((state->numTicks - lastBeepTime) >= 1){ //only run if it's been long enough (length of beep)
	//		lastBeepTime = state->numTicks;
	
	
			if (isBeeping){
				setAlarmLightOff();
				setBuzzerOff();
				isBeeping = false;
			}
			else{
				setAlarmLightOn();
				setBuzzerOn();
				isBeeping = true;
			}
	//	}
	}
	else{
		setBuzzerOff();
	}	
}


void handleTimeRollover (struct State *state){
	if (state->numTicks < TWELVE_HOURS){
		state->numTicks += TWENTY_FOUR_HOURS ; //prevents zero rollover bug
	}
	if (state->numTicks > THIRTY_SIX_HOURS){
		state->numTicks -= TWENTY_FOUR_HOURS ;
	}
	if (state->alarmTimeInTicks < TWELVE_HOURS){
		state->alarmTimeInTicks += TWENTY_FOUR_HOURS ; //prevents zero rollover bug
	}
	if (state->alarmTimeInTicks > THIRTY_SIX_HOURS){
		state->alarmTimeInTicks -= TWENTY_FOUR_HOURS ;
	}
}

void shouldAlarmSound(struct State *state){
	bool isLatchReleased = true;
	
	if (state->isAlarmSet &&
		isLatchReleased &&
		state->numTicks - state->alarmTimeInTicks <= 60 &&
		state->numTicks - state->alarmTimeInTicks >= 0
		){
		//the clock should fire the alarm if it's within a minute. also important not to accidentally
		//refire, hence the latch release
		
		state->isAlarmSounding = true;
		isLatchReleased = false;
	}
	
	if ((state->numTicks - state->alarmTimeInTicks) > 60){ isLatchReleased = true;}
	
}

ISR (PCINT0_vect){
		//much of this code is modified from makeatronics.blogspot.com
		//the idea was to create a clever sort of "grey code" lookup table
		//wherethe previous state is left shifted two bits and added to the most recent
		//state, creating a 4 bit grey code. the code then shows the encoder direction,
		//or 0, if it was an illegal "grey code" state.

		//the static keyword allows the table to persist within the scope of the ISR
		//from one ISR call to the next
		//static int8_t lookup_table[] = {0,-1,1,0,1,0,0,-1,-1,0,0,1,0,1,-1,0}; //saving the original table in a comment
		static int8_t lookup_table[] = {0,-1,1,0,0,0,0,0,0,0,0,0,0,0,0,0};  //trying to limit the to one tick per four counts
		static uint8_t grey_code = 0;
		
		uint8_t input_status;
		
		//the inputs were on QUAD_INT1 and QUAD_INT2  (PA2 and 3), so we mask off the other inputs and then shift
		//the bits to the right
		input_status = (PINA & 0b00001100) >> 2;   //PINA is Port Input A register

		grey_code = grey_code << 2 ;  //move the old grey code over two bits
		grey_code = grey_code | input_status ; //concatenates the current input status onto the old grey code
		grey_code = grey_code & 0b00001111; // masks off the high bits to throw the old grey shifted over grey code away

		ISR_accumulator += lookup_table[grey_code];
		
}

ISR (TIM1_COMPB_vect){
	ISR_ticked = ISR_ticked;
}

ISR (TIM1_OVF_vect){
	ISR_ticks++;
	ISR_ticked= true;
	//THIS ISR IS CALLLED WHEN THE 16 BIT TIMER HITS IT'S MATCH POINT
}



void alarmClockLoop(struct State *state){
	while (1) 
    {
		//************
		//*emptying ISRs
		//*************
		
		state->rotation_accumulator += ISR_accumulator;
		ISR_accumulator = 0;		
		
		if (ISR_ticked){
			ISR_ticked = false;
			
			//once a second
			if (ISR_ticks % 4 == 0){
				state->numTicks += 1;
				handleTimeRollover(state);
			}
		
			//4x per second
					
			shouldAlarmSound(state);  //this should run early to ensure it doesn't miss a time overlap
			
			//the available options for reading the pot are
			//    -just check the pot: pollInputs(state);
			//    -just check the pot and read residual capacitance: pollInputsWithCapSense(state);
			//    -check the pot and check the switch pulldown
			pollInputsWithPulldown(state);
			processAlarmPolledInputs(state);
			
		}
		processAlarmEncoderInputs(state);
		
		

		updateLEDs(state);
		updateSpeaker(state);	
		updateMeters(state);
		
		state->isJustEnteredMode = false;
		sleep_cpu();
	}
}

void powerONST(void){
/*	for( int i=0; i<32; i++){
		if(i<4){	HOURS_PWM = 64;	}
		else if (i<8){	HOURS_PWM = 128;	}
		else if (i<12){	HOURS_PWM = 192;	}
		else if (i<16){	HOURS_PWM = 255;	}
		else if (i<20){	HOURS_PWM = 192;	}
		else if (i<24){	HOURS_PWM = 128;	}
		else if (i<28){	HOURS_PWM = 64;	}
		else{	HOURS_PWM = 0;	}
		
		MINS_PWM = HOURS_PWM;
		
		sleep_cpu();
	}*/
	for( int i=0; i<16; i++){
		if(i<2){	HOURS_PWM = 64;	}
		else if (i<4){	HOURS_PWM = 128;	}
		else if (i<6){	HOURS_PWM = 192;	}
		else if (i<8){	HOURS_PWM = 255;	}
		else if (i<10){	HOURS_PWM = 192;	}
		else if (i<12){	HOURS_PWM = 128;	}
		else if (i<14){	HOURS_PWM = 64;	}
		else{	HOURS_PWM = 0;	}
		
		MINS_PWM = HOURS_PWM;
		
		sleep_cpu();
	}
}

/*
int controlClockSweep(struct State *state){
	static long oldnumticks = 0;
	static int super_accumulator = 0;
	static int super_accumulator2 = 0;
	static int super_accumulator3 = 0;
	static int super_accumulator4 = 0;
	static int sweep = 0;
	
	super_accumulator += state->rotation_accumulator;
		
	//if in sweep mode and input comes in the other direction, stop sweeping
	if ((sweep > 0) && 	(state->rotation_accumulator < 0)){
		sweep = 0;
		turnOffTimerB();
		super_accumulator = 0;
		super_accumulator2 = 0;
		super_accumulator3 = 0;
		super_accumulator4 = 0;
		//chirp();   removed chirp from plain Clock
	}
	else if ((sweep < 0) && (state->rotation_accumulator > 0)){
		sweep = 0;
		turnOffTimerB();
		super_accumulator = 0;
		super_accumulator2 = 0;
		super_accumulator3 = 0;
		super_accumulator4 = 0;
		//chirp();    removed chirp from plain Clock
	}
	
	int total;
	total = super_accumulator + super_accumulator2 + super_accumulator3 + super_accumulator4;
	//if enough turns are accumulated in 1 second, start sweeping
	if (sweep == 0){
		if (total > 14){
			sweep = 600;
			turnOnTimerB();
			//chirp();    removed chirp from plain Clock
		}
		else if (total < -14){
			sweep = -600;
			turnOnTimerB();
			//chirp();    removed chirp from plain Clock
		}
	}
	
	//if you switched modes while sweeping, stop sweeping
	if (state->isJustEnteredMode){
		sweep = 0;
		turnOffTimerB();
		super_accumulator = 0;
		super_accumulator2 = 0;
		super_accumulator3 = 0;
		super_accumulator4 = 0;
	}
	
	//if the clock has ticked 2 seconds, flush the superaccumulator
	if (ISR_ticks > oldnumticks ){
		super_accumulator4 = super_accumulator3;
		super_accumulator3 = super_accumulator2;
		super_accumulator2 = super_accumulator;
		super_accumulator = 0;
		oldnumticks = ISR_ticks;
	}
	
	return sweep;
}
*/
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
int main(void)
{
	struct State state;
	
	state.numTicks = FIVE_OCLOCK_SOMEWHERE;
	state.alarmTimeInTicks = NINE_AM;
	
	state.cal_hours = INITIAL_HOURS_CAL;
	state.cal_minutes = INITIAL_MINUTES_CAL;
	state.rotation_accumulator = 0;
	
	state.warbleLevel = 5;
	state.isAlarmSet = false;
	state.isUIActive = false;
	state.isAlarmSwitchOn = false;
	state.mode = MODE_TIME;
	state.isJustBooted = true;
	
	state.isAlarmSounding = false;  	
	
	
	
	init_all();
	
	powerONST();	
	
	if (isPlainClock()){
		set1HzTicks();
		plainClockLoop(&state);
	}
	else{
		set4HzTicks();
		alarmClockLoop(&state);
	}
	
		
}

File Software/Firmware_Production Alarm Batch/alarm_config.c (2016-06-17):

/*
 * alarm_config.c
 *
 * Created: 3/12/2016 8:36:20 PM
 *  Author: sfeller
 */ 

#ifndef _ALARM_CONFIG_C_
#define _ALARM_CONFIG_C_



//#include "alarm_config.h"
#include <avr/io.h>
#include <avr/interrupt.h>

 
 /**********************************
 * pinouts for ATtiny24/44/84 family
 ***********************************/
 
#define MODE_SELECT_POWER PA0
#define MODE_SELECT_INPUT PA1
#define QUAD_INT1 PA2
#define QUAD_INT2 PA3
#define MINUTES_OUT PA7
#define HOURS_OUT PB2
 
#define ALARM_LIGHT PA4
#define ALARM_BUZZER PA5
#define PM_LIGHT PA6

#define HOURS_PWM OCR0B
#define MINS_PWM OCR0A
  
 
 /**********************************
 * time related constants
 ***********************************/
 
#define F_CPU 32768 //default internal clock speed, actual speed will be changed to 32.768 clock crystal
#define TIMER_PRESCALER 1

//#define TIMER_TICKS_PER_INTERRUPT 32767
#define TIMER_TICKS_PER_INTERRUPT 8191  //4Hz interrupt rate
//#define TIMER_TICKS_PER_INTERRUPT 4095
#define TICKS_4HZ 8191
#define TICKS_2HZ 16383
#define TICKS_1HZ 32767

#define TWELVE_HOURS 43200 // 12hours * 60 min * 60 sec = 43200
#define TWENTY_FOUR_HOURS 86400
#define THIRTY_SIX_HOURS 129600 // 36 hours * 60 min * 60 sec - 129000 timer ticks
#define AMPM_LINE 86400 // 24 hrs * 60 min * 60 sec
#define FIVE_OCLOCK_SOMEWHERE 61200 //5pm in seconds
#define NINE_AM 118800// 9*60min*60sec + 86400 
//12 - 24 hrs is am
//24 - 36 hrs is pm


 // conversion = 32768hz / TIMER_PRESCALER / TIMER_TICKS_PER_INTERRUPT = 1 timer interrupts/sec

#define MINS_CONVERSION 60  //  1 timer_ints/sec * 60 secs/min = 60 timer_ints/minute
#define SECONDS_CONVERSION 1
 
#define INITIAL_HOURS_CAL 240
#define INITIAL_MINUTES_CAL 240
 
 
 /**********************************
 * constants for knob "mode" positions
 ***********************************/

#define CAP_SENSE_THRESHOLD 20
#define SWITCH_THRESHOLD 64
#define USB_POWER_THRESHOLD 128
/*
**************************
*the following were the original knob position settings from the plain
*AWK-105 clock. they are here for reference, but will need to be updated.
**************************
#define test_low 0
#define test_high 13

#define time_low 14
#define time_high 64

#define warble_low 65
#define warble_high 128

#define cal_hours_low 129
#define cal_hours_high 215

#define cal_minutes_low 216
#define cal_minutes_high 255
*/

#define POS_test 10
#define POS_minutes 45
#define POS_hours 97
#define POS_warble 173
#define POS_time 225
#define POS_alarm 255



#define CLOCK_POS_test 10
#define CLOCK_POS_minutes 65
#define CLOCK_POS_hours 129
#define CLOCK_POS_warble 216
#define CLOCK_POS_time 255







void indicator_init();
void pwm_init(void);
void timer_init(void);
void analog_init(void);
void pinchange_init(void);
void power_register_init(void);
void init_all(void);


void init_all(){
	indicator_init();
	pwm_init();
	timer_init();
	analog_init();
	pinchange_init();
	power_register_init();
	sei();
}

void indicator_init(){
	PORTA &= ~ (1 << ALARM_BUZZER)|(1 << ALARM_LIGHT)|(1 <<PM_LIGHT);	//disables pullup / turn outputs to zero when the DDRA is flipped
	DDRA |= (1 << ALARM_BUZZER)|(1 << ALARM_LIGHT)|(1 <<PM_LIGHT);		//switch pins from inputs to outputs
	
}

// initialize PWM
void pwm_init()
{
	// Timer/Counter Control  Register 0A
	//  SET WAVE GENERATION MODE
	//  ***********************************************************
	//  Setting WaveGenerationMode bits 00:02 to 0b001 puts the counter in phase correct PWM mode
	//  and sets the TOP of the counter to the full 0xFF range. (see page83 of docs)
	
	//  SET OUTPUT COMPARISON MODE
	//  ***********************************************************
	//  Setting only Compare Output Mode bit A1 (COM0A1) clears the counter when up-counting on a match and sets it
	//  when down-counting. Kinda like inverted mode. (See page 81/82).
	
	TCCR0A = (1<<WGM00)|(1<<COM0A1)|(1<<COM0B1); ;
	
	// SET CLOCK SOURCE
	// No Clock prescaler will be necessary for the PWM
	// System clock is at 32khz
	// 32khz / 256bits*2 for counting up AAAND down = 64Hz
	
	TCCR0B |= (1 << CS00); // set clock source to 0b001 for on with no prescaler
	
	//  SET DATA DIRECTION REGISTERS
	//  ***********************************************************
	// the Output Compare 0A register (OC0A) is PortB2, and OC0B is on PortA7
	// set the Data Direction Register
	DDRB |= (1<<HOURS_OUT);
	DDRA |= (1<<MINUTES_OUT);
}
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

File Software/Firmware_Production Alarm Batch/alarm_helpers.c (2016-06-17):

#ifndef _ALARM_HELPERS_C_
#define _ALARM_HELPERS_C_

#include "alarm_config.c"
#include <stdlib.h>
#include <stdbool.h>
#include <avr/io.h>

inline void setAlarmLightOn(void);
inline void setAlarmLightOff(void);
inline void setPMLightOn(void);
inline void setPMLightOff(void);
inline void setBuzzerOff(void);
inline void setBuzzerOn(void);
void chirp(void);
inline uint8_t pollPot(void);
inline uint8_t pollSwitchVoltage(void);
inline bool isPlainClock(void);
inline bool isSwitchUp(void);
inline struct PotAndCap pollPotWithCapSense(void);
uint8_t calcHoursFromTics(unsigned long tics, uint8_t scale);
uint8_t calcMinsFromTics(unsigned long tics, uint8_t scale);
void set4HzTicks(void);
void set1HzTicks(void);

void setMinutesMeter(uint8_t pwm);
void setHoursMeter(uint8_t pwm);

struct PotAndCap {
	uint8_t pot;
	uint8_t cap;
	};

inline void setAlarmLightOn(){
	PORTA |= (1<<ALARM_LIGHT);	
}

inline void setAlarmLightOff(){
	PORTA &= ~(1<<ALARM_LIGHT);
}

inline void setPMLightOn(){
	PORTA |= (1<<PM_LIGHT);
}

inline void setPMLightOff(){
	PORTA &= ~(1<<PM_LIGHT);
}

inline void setBuzzerOn(){
	PORTA |= (1<<ALARM_BUZZER);
}

inline void setBuzzerOff(){
	PORTA &= ~(1<<ALARM_BUZZER);
}

inline uint8_t pollPot(){

	PRR &= ~(1<<PRADC); //turns on the ADC comparator
	PORTA |= (1<<MODE_SELECT_POWER); //turn on to power pot
	ADCSRA |= (1<<ADSC); // starts AtoD conversion by flipping ADC Start Conversion bit in AD Control and Status Register A
	while(ADCSRA & (1<<ADSC));  // loops while waiting for ADC to finish
	PORTA &= ~(1<<MODE_SELECT_POWER); //turn pot back off to conserve power
	PRR |= (1<<PRADC); //shuts down the ADC and comparator
	
	return ADCH;  //returns hight byte of AtoD conversion
}

inline uint8_t pollSwitchVoltage(){
	PRR &= ~(1<<PRADC); //turns on the ADC comparator
		 
		 ADMUX &= ~(0b00011111); //set the MUX bits to 00000, this selects ADC0 (MODE POWER pin as the AtoD source)
		 
			 //turn pot power back off
			 PORTA &= ~(1<<MODE_SELECT_POWER); //keep pot off to conserve power
		 
				 //make MODE POWER pin  an input
				 DDRA &= ~(1<<MODE_SELECT_POWER); //makes pot power pin an input
	
 					 ADCSRA |= (1<<ADSC); // starts AtoD conversion by flipping ADC Start Conversion bit in AD Control and Status Register A
					 while(ADCSRA & (1<<ADSC));  // loops while waiting for ADC to finish
		 
			//make MODE POWER an output again
			DDRA |= (1<<MODE_SELECT_POWER);		 				
		 				
		//return the admux to the POT input
		ADMUX |= (1<<MUX0); //return to MUX picking the POT input
		 				
	//shut down the ADC
	PRR |= (1<<PRADC); //shuts down the ADC and comparator
	
	return ADCH;
}

inline bool isSwitchUp(){
	
	if (pollSwitchVoltage() < SWITCH_THRESHOLD){
		return true;
	}
	else{
		return false;
	}
}

inline bool isPlainClock(){
	if (pollSwitchVoltage() < USB_POWER_THRESHOLD){
		return true;
	}
	else{
		return false;
	}
}

inline struct PotAndCap pollPotWithCapSense(){
		
	struct PotAndCap potAndCap;
	
	//turn on ADC and power
	PRR &= ~(1<<PRADC); //turns on the ADC comparator
	PORTA |= (1<<MODE_SELECT_POWER); //turn on to power pot
	
	//read pot	
	ADCSRA |= (1<<ADSC); // starts AtoD conversion by flipping ADC Start Conversion bit in AD Control and Status Register A
	while(ADCSRA & (1<<ADSC));  // loops while waiting for ADC to finish
	potAndCap.pot = ADCH; // save high byte in pot
	

		//switch AtoD Mux to MODE POWER pin
		ADMUX &= ~(0b00011111); //set the MUX bits to 00000, this selects ADC0 (MODE POWER pin as the AtoD source)
	
			int i=0;
			while (i<100){i++;}// delay to build up charge
			
			//turn pot power back off
			PORTA &= ~(1<<MODE_SELECT_POWER); //turn pot back off to conserve power
					
				//make MODE POWER pin  an input
				DDRA &= ~(1<<MODE_SELECT_POWER); //makes pot power pin an input
	
						//read residual capacitive charge on input
						ADCSRA |= (1<<ADSC); 
						while(ADCSRA & (1<<ADSC)); 
						potAndCap.cap = ADCH;
	
				//make MODE POWER an output again
				DDRA |= (1<<MODE_SELECT_POWER);
	
	
		//return the admux to the POT input
		ADMUX |= (1<<MUX0); //return to MUX picking the POT input
	
	//shut down the ADC
	PRR |= (1<<PRADC); //shuts down the ADC and comparator
	
	
	return potAndCap;  //returns hight byte of AtoD conversion
}

void setMinutesMeter(uint8_t pwm){
	MINS_PWM = pwm; 
}

void setHoursMeter(uint8_t pwm){
	HOURS_PWM = pwm;
}


uint8_t calcHoursFromTics(unsigned long tics, uint8_t scale){
	uint8_t hours;
	
	hours = (((tics /(60* MINS_CONVERSION) % 12 ) * scale) / 12) ; //order of operations matters to avoid rounding errors
	if (hours==0){
		hours=scale;
	}
	
	return (uint8_t)(hours );  //get the low byte of hours;
}


uint8_t calcMinsFromTics(unsigned long tics, uint8_t scale){
	uint8_t minutes;
	minutes = (((tics / SECONDS_CONVERSION) % 3600) * scale) / 3600;
	
	return (uint8_t)(minutes); //get the low byte of minutes

}

void chirp(void){
	
	setBuzzerOn(); //the buzzer is turned off later on, but the idea is to get a short Bloop!
	int i=0;
	while(i<100){i++;}
}

void set4HzTicks(void){
	OCR1A = TICKS_4HZ;
}

void set1HzTicks(void){
	OCR1A = TICKS_1HZ;
}

void turnOnTimerB(void){
	OCR1B = OCR1A /2 ;
}

void turnOffTimerB(void){
	OCR1B = OCR1A + 1;
}

#endif

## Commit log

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2014-03-26 added google drive files
    [A SIDE.SLDPRT, AWK-105-0001.SLDPRT, AWK-105-0002.SLDPRT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]
2014-03-27 organizing repo
    [A SIDE.SLDPRT, AWK-105-0001.SLDPRT, AWK-105-0002.SLDPRT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]
2014-03-27 moved some mechanical files
    [A SIDE.SLDPRT, B SIDE.SLDPRT]
2014-03-27 moved even more stuff
    [A SIDE.SLDPRT, AWK-105-0001.SLDPRT, AWK-105-0002.SLDPRT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]
2014-03-29 started board layout
    [clock.sch]
2014-03-30 started on schematic capture
    [clock.sch]
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2014-04-03 CAD check files
    [AWK-105-0003.SLDASM, AWK-105-0008.SLDPRT, AWK-105-0009.SLDPRT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]
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2014-04-24 both PWM compare registers in inverting mode
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2014-04-25 updated the face designs
    [Faceplate.SLDPRT]
2014-04-25 modified the faceplate
    [Faceplate.SLDPRT]
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2014-05-19 started into board layout
    [clock.kicad_pcb, clock.sch]
2014-06-24 big catchup
    [AWK-105-0002.SLDPRT, AWK-105-0003.SLDASM, AWK-105-0004.SLDPRT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]
2014-06-25 graphics updates
    [AWK-105-0002.SLDPRT, AWK-105-0003.SLDASM, AWK-105-0004.SLDPRT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]
2014-06-25 made drawings
    [AWK-105-0002.SLDPRT, AWK-105-0010.SLDDRW, PART NUMBER LIST.xlsx]
2014-07-09 board layout updates for battery stuff
    [AA_BATTERY.SLDPRT, AWK-105-0003.SLDASM, clock.kicad_pcb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]
2014-07-17 updates to board layout
    [AWK-105-0002.SLDPRT, AWK-105-0003.SLDASM, AWK-105-0005.SLDPRT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]
2014-07-17 updated board layout
    [clock.kicad_pcb]
2014-07-22 checking board layout against knob parts
    [AWK-105-0002.SLDPRT, AWK-105-0003.SLDASM, AWK-105-0005.SLDPRT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]
2014-11-13 catching up on a bunch of stuff
    [AWK-105-0001.SLDPRT, AWK-105-0002.SLDPRT, AWK-105-0003.SLDASM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]
2014-11-16 updated BOM info
    [AWK-105-0002.SLDPRT, AWK-105-0003.SLDASM, AWK-105-0014.SLDPRT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]
2014-12-02 release to quote
    [BOM awkwardengineer-Clock#2426.csv, awkwardengineer-Clock#2426-SMT-TOP.csv, awkwardengineer-Clock#2426-Th-TOP.csv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]
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2015-01-02 alternate power source research
    [alternate USB power source exploration.xlsx, dial overlay sketch model.SLDPRT]
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2015-01-04 added LDO to schematic and board
    [clock.kicad_pcb, clock.sch]
2015-01-22 meter updates, DFM updates
    [costed parts list.xlsx]
2015-01-27 backer updates and artwork changes
    [costed parts list.xlsx]
2015-03-06 mechanical and BOM updates
    [AWK-105-0002.SLDPRT, AWK-105-0003.SLDASM, AWK-105-0005.SLDPRT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]
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2015-03-06 artwork updates for sending to factory
    [face plate CAD layout.SLDPRT]
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2015-03-06 starting to make purchases
    [Production Planning.xlsx]
2015-03-23 schematic back in old version of kicad
    [clock.sch]
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2015-03-23 quotes on chip programming
    [PreProgramming_worksheet_R2(1).xlsx]
2015-03-23 making a test rig
    [AWK-105-0101 v1.STL, AWK-105-0101.SLDPRT, AWK-105-100.SLDASM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]
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2015-05-27 holy cow getting chips burned!
    [Firmware_Board_preProduction.c]
2015-07-05 production planning and purchases
    [AWK-105-0002 revE.SLDPRT, AWK-105-0003 revE.SLDASM, AWK-105-0004 revE.SLDPRT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]
2015-07-05 getting cases ready for purchase
    [AWK-105-0002 revC.SLDPRT, AWK-105-0002 revD.SLDPRT, AWK-105-0003 revC.SLDASM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]
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2015-07-05 organizing artwork folder and making new artwork
    [REFERENCE back flat pattern.DXF, REFERENCE box outlines.DXF, REFERENCE box outlines.SLDDRW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]
2015-07-05 update board design with new footprint
    [footprint test 2.SLDPRT, footprint test 2.dxf, footprint test.SLDPRT]
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2015-08-24 changing / updating artwork
    [REFERENCE box outlines alarm.DXF, REFERENCE box outlines.SLDDRW]
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2015-10-11 request for shorter threads
    closes issue #28
2015-10-14 updates to BOM to help build quote package
    [AWK-105-0001-H.SLDPRT, AWK-105-0001-M.SLDPRT, AWK-105-0002.SLDPRT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]
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2015-10-29 made a test circuit board for the resistor divider
    [AWK-105-100.SLDASM, board outline.SLDPRT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]
2015-10-29 saved some circuit board updates
    [clock.sch]
2015-10-29 deleted some backer report stuff
    [Kickstarter Backer Report - $159.00 USD reward - Jun 30 06pm.csv, Kickstarter Backer Report - $399.00 USD reward - Jun 30 06pm.csv, Kickstarter Backer Report -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]
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2015-10-29 removed some files from repository
    [costed parts list.xlsx]
2015-10-30 fixed schematic
    closes issue #17
    [clock.sch]
2015-10-30 add filter cap
    closed issue #15
    [clock.sch]
2015-10-30 closes issue 19, shortable pullup
    [clock.sch]
2015-11-01 changed breakaway to a capacitor solution
    [clock.sch]
2015-11-01 foot print and schematic updates
    got the LED TE connector, SMT LDO, transistor for AM/PM lights
    footprints and schematic updated
    [clock.kicad_pcb, clock.sch]
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2015-11-04 made changes to speaker footprint
    [clock.kicad_pcb, clock.sch]
2015-11-05 updated test pad foot print and also some transistors
    [clock.kicad_pcb]
2015-11-09 reorganized board layout, but haven't fully wired
    [clock.kicad_pcb, clock.sch]
2015-11-19 finalized changes and sent to fab
    [clock-B_Cu.gbl, clock-B_Mask.gbs, clock-B_SilkS.gbo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]
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2015-12-17 added photos and revH drawing updates
    [AWK-105-0002 revH.SLDPRT, AWK-105-0002.SLDPRT, AWK-105-0004 revH.SLDPRT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]
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2016-03-07 renamed a folder and lost info from it
    [Production Planning.xlsx, meter test rig production planning.xlsx]
2016-03-07 updated mechanical stuff and some cleanup
    [AWK-105-0002.SLDPRT]
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2016-03-23 mechanical updates mixed on this branch
    [AWK-105-0002.SLDPRT, AWK-105-0010.SLDDRW]
2016-03-27 changed LED backlight power source, simplified POT, added LED dimming
    [clock.sch]
